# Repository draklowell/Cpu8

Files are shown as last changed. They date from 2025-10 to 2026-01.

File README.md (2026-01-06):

# Architecture of Dragonfly 8b9m CPU

## CPU4/4 (Made by previous students 2024)

CPU4/4

## CPU8/16 (Made by students 2025)

CPU8/16

## Google Spreadsheet for CPU components

<https://docs.google.com/spreadsheets/d/1K8h9GaudWlOMMR60cffy0GHXr_kNyvZ4bdUqfh8yQC4/edit?pli=1&gid=0#gid=0>

## Kicad Components and Footprints used in the project

### Bulk capacitor 100uF 16V

<https://www.rcscomponents.kiev.ua/product/100uf-16v-e5r-6-3x5mm-e5r101m16b-hitano-elektrolitychnyi-kondensator_14183.html>

**Footprint:**

Capacitor_THT:C_Radial_D6.3mm_H5.0mm_P2.50mm

### Decoupling capacitor 100nF 50V Y5V

<https://www.rcscomponents.kiev.ua/product/100nf-50v-y5v-k-10-d-5mm-cc-100n_163416.html>

**Footprints:**

Capacitor_THT:C_Disc_D5.0mm_W2.5mm_P5.00mm

Capacitor_THT:C_Disc_D5.0mm_W2.5mm_P2.50mm

### Resistor Pull UP 10k Ohm 0.25W

<https://www.rcscomponents.kiev.ua/product/10-kohm-5-0-25w-vyv-cr025sjtb-10k-hitano_13787.html>

**Footprint:**

Resistor_THT:R_Axial_DIN0207_L6.3mm_D2.5mm_P7

### Screw Terminal DG126/5.0-02P-14.00Z-H**

<https://www.rcscomponents.kiev.ua/product/klemnyk-dg126-5-0-02p-14-00z-h_18375.html>

**Footprint:**

<https://www.tme.eu/en/details/dg126-5.0-2p14/pcb-terminal-blocks/degson-electronics/dg126-5-0-02p-14-00a-h/>

### Connector PDB-38

<https://www.rcscomponents.kiev.ua/product/pbd-38-kls1-208-2-38-s_119543.html>

**Footprint:**

Connector_PinSocket_2.54mm:PinSocket_2x19_P2.54mm_Vertical

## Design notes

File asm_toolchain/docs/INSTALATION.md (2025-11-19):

# Installation Guide

## Prerequisites

- CMake 3.xx

### 1. Build without installation

```bash
cd asm_toolchain
cmake -S . -B build -DCMAKE_BUILD_TYPE=Release
cmake --build build -j
```

**Створює бінарники в**

```bash
build/bin/cpua
build/bin/cpul
build/bin/cpu_objdump
```

**Використання**

```bash
./build/bin/cpua --help
./build/bin/cpul --help
./build/bin/cpu_objdump main.o
```

### 2. System-wide installation (requires sudo)

Встановлює в `/usr/local/bin` - PATH вже налаштований автоматично:

```bash
cd asm_toolchain
cmake -S . -B build -DCMAKE_BUILD_TYPE=Release -DCMAKE_INSTALL_PREFIX=/usr/local
cmake --build build -j
sudo cmake --install build
```

**Перевірка:**

```bash
which cpua
which cpul
which cpu_objdump
cpua --help
cpul --help
cpu_objdump --help
```

### 3. User-local installation (без sudo)

Встановлює в `$HOME/.local/bin` - потребує додавання до PATH один раз:

```bash
cd asm_toolchain
cmake -S . -B build -DCMAKE_BUILD_TYPE=Release -DCMAKE_INSTALL_PREFIX="$HOME/.local"
cmake --build build -j
cmake --install build
```

**Додайте до PATH (один раз для macOS/Linux):**

```bash
echo 'export PATH="$HOME/.local/bin:$PATH"' >> ~/.zshrc
source ~/.zshrc
```

Для bash:

```bash
echo 'export PATH="$HOME/.local/bin:$PATH"' >> ~/.bashrc
source ~/.bashrc
```

**Перевірка:**

```bash
which cpua
which cpul
which cpu_objdump
cpua --help
cpul --help
```

### 4. Uninstallation

**Для user-local installation:**

```bash
cd asm_toolchain
xargs rm -vf < build/install_manifest.txt
```

**Для system-wide installation:**

```bash
cd asm_toolchain
sudo xargs rm -vf < build/install_manifest.txt
```

**Альтернативно (перегляд файлів перед видаленням):**

```bash
cd asm_toolchain
cat build/install_manifest.txt
```

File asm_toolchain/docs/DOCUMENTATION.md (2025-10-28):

# DOCUMENTATION

# ASM Structures

## Operand Types

| OperandType | Explanation | Example | Machine code (Big Endian) |
|---|---|---|---|
| **None** | Інструкція без аргументів | `nop`, `ret`, `hlt` | Тільки 1 байт опкоду |
| **Reg** | 8-бітний регістр | `add ac`, `mov xh, ac` | Опкод визначається регістрами |
| **Imm8** | 8-бітне безпосереднє значення | `ldi ac, 0x12` | 1 байт значення після опкоду |
| **Imm16** | 16-бітне безпосереднє значення (адреса) | `jmp 0x1234` | 2 байти у Big Endian (`12 34`) |
| **Label** | Мітка, що посилається на адресу коду/даних | `jmp main` | Як `Imm16`, але через релокацію |
| **MemAbs16** | Абсолютна адресація через пам'ять | `ld ac, [0x1234]`, `ld ac, [value]` | 2 байти адреси у Big Endian (`12 34`) |
| **MemAtReg16** | Непряма адресація через 16-бітний регістр  | `ld ac, [X]`, `st [Y], ac` | Опкод кодує вибір пари (X/Y/Z/SP/ADR) |
| **SP** | Використання стекового покажчика | `push ac`, `pop ac` | Спеціальний режим доступу |
| **PC** | Лічильник команд | `jmp pc` (якщо підтримується) | Спеціальний режим |

> **Endianness:** усі 16-бітні значення у машинному коді зберігаються у **Big Endian** — спочатку **старший**, потім **молодший** байт (`HI -> LO`).

> **Примітка:** квадратні дужки тепер можуть містити як числовий літерал, так і мітку (`ld ac, [data]`). У випадку з міткою асемблер створює релокацію для абсолютної адреси.

---

## Registers

| Name | Type | Description |
|---|---|---|
| **AC**  | 8-bit  | Основний акумулятор (ALU), молодший байт пари **X** |
| **XH**  | 8-bit  | Старший байт регістра **X** |
| **YH**  | 8-bit  | Старший байт регістра **Y** |
| **YL**  | 8-bit  | Молодший байт регістра **Y** |
| **ZH**  | 8-bit  | Старший байт регістра **Z** |
| **ZL**  | 8-bit  | Молодший байт регістра **Z** |
| **FR**  | 3-bit  | Регістр прапорів: **Sign (S)**,**NotCarry (C)**, **Zero (Z)** NotCarry – інвертований |
| **IR**  | 8-bit  | Instruction Register (зберігає поточний опкод) |
| **X** | 16-bit | Об'єднання **(XH:AC)** — використовується як 16-бітний адресний або арифметичний регістр |
| **Y** | 16-bit | Об'єднання **(YH:YL)** — 16-бітний покажчик |
| **Z** | 16-bit | Об'єднання **(ZH:ZL)** — 16-бітний покажчик |
| **SP**  | 16-bit | Stack Pointer — лічить **вгору/вниз** залежно від операції |
| **PC**  | 16-bit | Program Counter — завжди рахує **вгору** |
| **ADR** | 16-bit | Address Register — завжди також пише адресу в пам’ять |
| **ARG** | 16-bit | Argument Register — тимчасовий регістр для збереження адрес або аргументів |

---

# Symbol Table

## Purpose

**Symbol Table** — це таблиця, у якій асемблер зберігає всі **імена, що з’являються у програмі**:

* мітки (`main:`, `loop:`)
* імена змінних у секціях `.data`, `.bss`
* зовнішні або глобальні символи (`.globl func`, `extern printf`)

## Structure of symbol record

| Field | Desc |
|---|---|
| `name` | Ім’я символу (`"main"`, `"var1"`, `"printf"`) |
| `section` | Секція, де визначено символ (`.text`, `.data`, `.bss`, або `None`) |
| `value` | Адреса (offset у байтах) всередині секції |
| `bind` | Видимість: `Local`, `Global`, або `Weak` |
| `defined` | Чи символ уже має адресу (`true` — визначений, `false` — тільки оголошений) |

## Symbol Life Cycle

### Pass1

Асемблер читає вихідний код і **будує таблицю символів**.

#### Якщо зустрічає мітку

```asm
main:
```

Додає або оновлює символ:

```
define("main", SectionType::Text, current_offset, Local)
```

#### Якщо директива `.globl foo`

Оголошує символ як глобальний, але `defined = false`.

#### Якщо зустрічає посилання на невідомий символ

```asm
jmp func
```

Створює запис `declare("func")` без визначення — щоб пізніше його знайти.

### Pass2

Асемблер формує машинний код.

* Якщо **символ визначений**, бере його адресу (`value`) і вставляє у код.
* Якщо **ще не визначений**, створює **релокаційний запис (RelocEntry)**, щоб лінкер пізніше підставив адресу.

## Example

```asm
.text
main:
    ldi z, func
    jmpx

func:
    nop
```

### Pass1

| name | section | value  | bind  | defined |
|---|---|---|---|---|
| main | .text | 0x0000 | Local | true |
| func | .text | 0x0004 | Local | true |

### Pass2

`ldi z, func` -> знаходить `func` (визначений у `.text` з адресою `0x0004`)
-> асемблер вставляє `0x0004` у машинний код (`00 04`, Big Endian).

## Example with undefined symbol

```asm
.text
main:
    ldi y, msg
    jmp print

.data
msg:
    .ascii "Hello"

.globl print
```

### Pass1

| name  | section | value  | bind | defined |
|---|---|---|---|---|
| main  | .text | 0x0000 | Local  | true |
| msg | .data | 0x0000 | Local  | true |
| print | None | 0x0000 | Global | false |

### Pass2

* `ldi y, msg` -> `msg` визначений, адреса вставляється напряму.
* `jmp print` -> `print` ще не визначений, створюється **релокація**:

```
reloc:
  offset = 0x0003      ; байт, де треба вставити адресу
  symbol = "print"
  type = ABS16
```

Коли `.o` файл зв’яжеться з іншим, де `print` визначений — **лінкер** підставить справжню адресу.

## Error Types

| Error | When |
|---|---|
| `redefinition of symbol` | символ з таким іменем уже визначений |
| `undefined symbol` | після Pass2 символ не знайдений і не Global |
| `invalid section reference` | посилання на секцію, якої не існує |

## Example with `ldi` and `.text`

```asm
.text
main:
    ldi z, label
    jmpx

label:
    nop
```

Це **нормально**: `ldi` просто завантажує адресу `label` (наприклад, `0x0004`) у регістр `Z`, а `jmpx` виконує стрибок туди. `.text` — така ж секція з валідними адресами.

# Object File and Relocation System

## Overview

The **Object File** is an intermediate binary format generated by the assembler and consumed by the linker. It contains:

* Encoded sections of machine code and data.
* A list of symbols (labels, globals, etc.).
* Relocation entries that describe how to adjust addresses during linking.

This system allows the assembler and linker to work independently: the assembler doesn't need to know final memory addresses — it only marks where they should be patched.

---

## Object File Structure

Кожен об'єктний файл складається з трьох основних таблиць:

| Component | Description |
|---|---|
| **Sections** | Містять байти коду або даних (наприклад, `.text`, `.data`, `.bss`). |
| **Symbols** | Містять всі визначені та згадані імена з їхніми адресами та типами зв'язування. |
| **Relocations** | Містять всі позиції, де лінкер повинен підставити адреси. |

### SectionDescription

```cpp
struct SectionDescription {
    std::string name;     // ".text", ".data", ".bss"
    uint8_t flags{0};     // 1=EXEC, 2=WRITE, 4=READ
    uint8_t align{1};     // alignment (1,2,4,...)
    std::vector<uint8_t> data; // raw bytes for .text/.data
    uint32_t bss_size{0}; // size of uninitialized section
};
```

#### Fields Explained

* **name** — ім'я секції.
* **flags** — права доступу секції (EXEC, WRITE, READ). Бітове кодування.
* **align** — вирівнювання пам'яті для секції (має бути степенем 2).
* **data** — машинний код або ініціалізовані дані.
* **bss_size** — розмір пам'яті для неініціалізованих даних (.bss).

#### Example

| Section | Flags | Align | Description |
|---|---|---|---|
| `.text` | EXEC (1) | 1 | Секція коду, виконується |
| `.data` | WRITE+READ (6) | 2 | Ініціалізовані дані |
| `.bss`  | WRITE+READ (6) | 2 | Змінні, ініціалізовані нулями |

---

### SymbolDescription

```cpp
struct SymbolDescription {
    std::string name;    // symbol name
    int32_t section_index; // section index, -1 = UNDEF
    uint32_t value;      // offset within section
    uint8_t bind;        // 0=Local, 1=Global, 2=Weak
};
```

#### Fields Explained

* **name** — ідентифікатор символу (наприклад, `main`, `msg`).
* **section_index** — секція, до якої належить символ (`-1` означає невизначений).
* **value** — зміщення від початку секції.
* **bind** — видимість і тип зв'язування.

#### Usage

* **Local** символи видимі тільки всередині одного об'єктного файлу.
* **Global** символи видимі для інших об'єктних файлів.
* **Weak** символи можуть бути перевизначені сильнішими.

---

## Relocation System

Коли інструкція посилається на мітку або змінну, адреса якої ще не відома, асемблер не може безпосередньо закодувати адресу. Замість цього він генерує **RelocEntry**, який описує де і як підставити значення, коли фінальне розміщення буде відоме.

### RelocEntry

```cpp
struct RelocEntry {
    uint32_t section_index; // section where the relocation applies
    uint32_t offset;        // byte offset within the section
    RelocType type;         // type of relocation (e.g., ABS16)
    uint32_t symbol_index;  // index of the referenced symbol in the symbol table
    int32_t addend{0};      // additional constant offset
};
```

#### Fields Explained

| Field | Meaning |
|---|---|
| **section_index** | У якій секції застосувати релокацію (наприклад, .text). |
| **offset** | Точна позиція байта всередині цієї секції, яку потрібно підставити. |
| **type** | Визначає як застосувати релокацію (наприклад, абсолютна 16-бітна адреса). |
| **symbol_index**  | Вказує на символ, адреса якого має бути вставлена. |
| **addend** | Додаткова константа, яка додається до адреси символу (для `label + N`). |

#### RelocType

| Name | Meaning |
|---|---|
| `ABS16` | Абсолютна 16-бітна адреса, збережена у форматі Big Endian. |

---

### Example Workflow

```asm
.text
main:
    ldi z, msg   ; load address of msg into Z
    jmpx         ; jump to Z

data:
msg:
    .ascii "Hello"
```

#### Pass1

* Визначає `main` та `msg` у секціях `.text` та `.data`.

#### Pass2

* Кодує `ldi z, msg` -> опкод + заповнювач для адреси.
* Оскільки `msg` відомий (у `.data`), його зміщення вставляється.
* Якби `msg` був в іншому об'єкті, асемблер би створив релокацію:

```cpp
RelocEntry {
    section_index = 0,     // .text
    offset = 2,            // where to patch
    type = RelocType::ABS16,
    symbol_index = 1,      // msg
    addend = 0
};
```

#### Linking

* Лінкер завантажує всі `.o` файли, об'єднує секції.
* Він замінює кожну релокацію фінальною абсолютною адресою:

  ```
  final_value = symbol_address + addend
  ```

  і записує її у `offset` всередині відповідної секції.

---

# Lexer

## Purpose

Лексер — це перший етап роботи асемблера.
Він читає вихідний текст програми (`.asm`) і перетворює його у **послідовність токенів** — базових одиниць синтаксису (імена, числа, дужки, коми, тощо).

Кожен токен містить:

* **тип** (`Ident`, `Number`, `Comma`, `Dot`, …),
* **текстове значення** (наприклад `"ldi"` або `"0x42"`),
* **позицію у файлі** (рядок і стовпчик для зручного виведення помилок).

---

## Algorithm

Лексер проходить текст посимвольно зліва направо,
веде лічильники **рядка** і **колонки**, і будує токени за певними правилами.

1. **Пропускає порожні символи** — пробіли, табуляцію, вертикальні/форматні пробіли.
2. **Розпізнає коментарі**:

* `;` або `#` — до кінця рядка;
* `//` — також коментар до кінця рядка.
    Коментарі не потрапляють у потік токенів.

3. **Фіксує переходи рядка** (`\n`, `\r`, `\r\n`) — створює токен `NewLine`,
   оновлює `line++`, `col = 1`.
4. **Розпізнає розділові символи**:

   ```
   [ ] , : .
   ```

   — кожен стає окремим токеном (`LBracket`, `RBracket`, `Comma`, `Colon`, `Dot`).
5. **Ідентифікатори** — послідовність, що починається з літери або `_`,
   далі можуть бути літери, цифри або `_`.
   Формує токен `Ident`.
6. **Числа** — якщо перший символ — цифра, зчитує всі наступні **цифри або літери**,
   формуючи токен `Number`.
   Тип системи числення (0x..., 0b...) визначається пізніше у `parseNumber`.
7. Якщо зустрічає **невідомий символ** — кидає помилку `util::Error("Unexpected character in input")`.
8. Після завершення додає токен `Eof` — кінець файлу.

---

## FSM

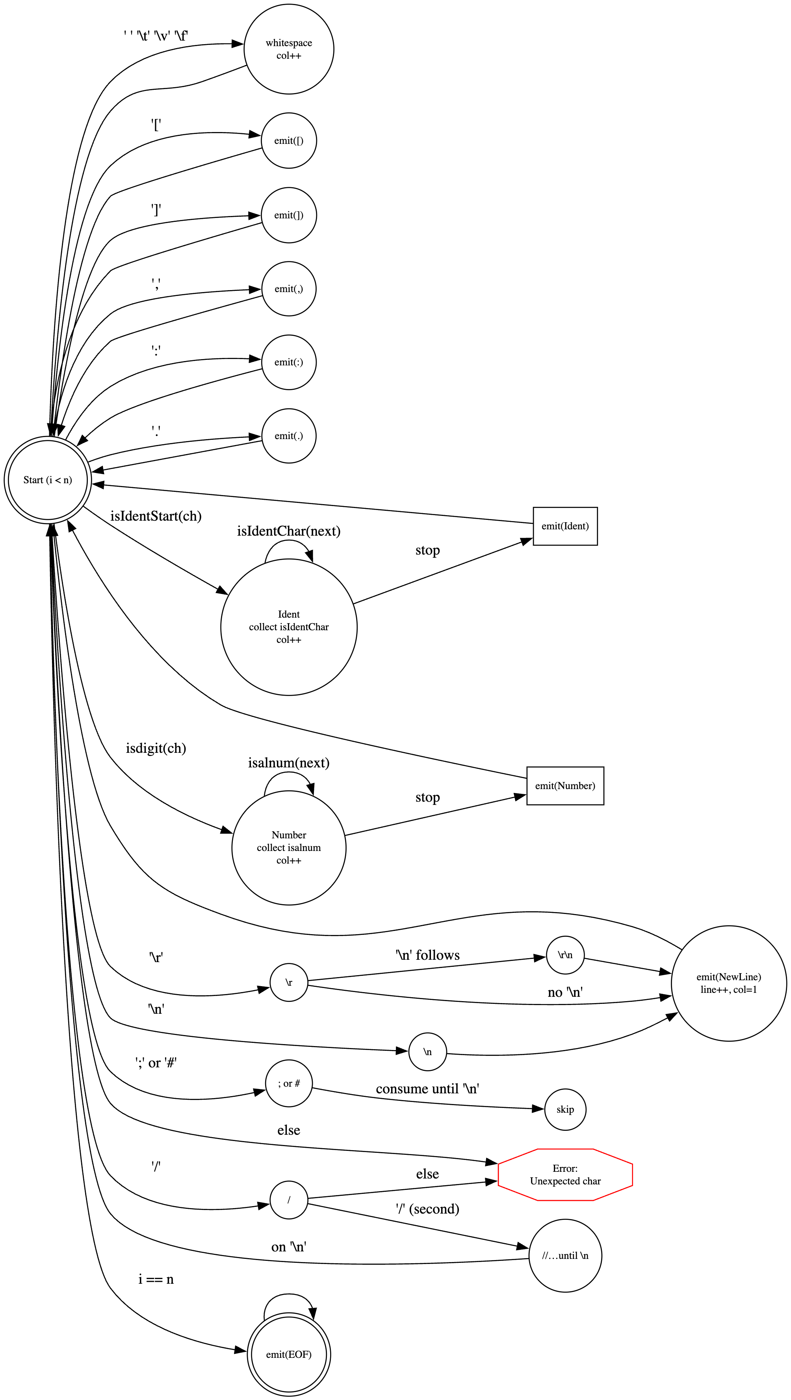
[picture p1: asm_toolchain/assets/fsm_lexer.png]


На зображенні нижче показано **спрощену модель кінцевого автомата (Finite State Machine)**,
який відображає переходи між станами лексера.

* `Start` — початковий стан;
* `NewLine` — обробка переходів рядків;
* `WS` — пропуск пробільних символів;
* `Ident`, `Number` — накопичення тексту токенів;
* `Slash`, `LineComment`, `SemiHash` — обробка коментарів;
* `Emit*` — формування готового токена;
* `Eof` — завершення аналізу;
* `Error` — некоректний символ.

> Кожна стрілка позначає перевірку символу і перехід у новий стан.
> Коли лексер знаходить токен, він “викидає” його у список результатів і повертається до стану `Start`.

---

## Example

Вхідний код:

```asm
; comment
ldi x, 0x42
add-xh
```

Після `lex()` отримаємо токени:

| Тип токена | Текст | Рядок | Колонка |
|---|---|---|---|
| `NewLine`  | | 1 | 1 |
| `Ident` | `ldi` | 2 | 1 |
| `Ident` | `x` | 2 | 5 |
| `Comma` | `,` | 2 | 6 |
| `Number` | `0x42` | 2 | 8 |
| `NewLine`  | | 2 | 12 |
| `Ident` | `add-xh` | 3 | 1 |
| `Eof` | | 3 | 8 |

---

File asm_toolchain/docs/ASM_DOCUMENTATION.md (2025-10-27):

# Documentation assembler CPU8/16

## 1. Overview

CPU8/16 — це навчальний кастомний асемблер для однойменного 8-бітного процесора з вибірковою підтримкою 16-бітних операцій. Джерельні файли проходять через GCC-препроцесор (`cpp`), тому можна використовувати `#define`, `#include`, `#ifdef` та інші директиви. Процес складання виконується у два проходи: **Pass1** збирає мітки та формує таблицю символів, а **Pass2** підставляє адреси й генерує машинний код. Результатом є плоский ROM-образ на 16 КБ, заповнений байтами `0xFF`, у який потрапляють секції `.text` та `.rodata`.

## 2. Syntax basics

Кожен рядок інструкції має формат:

```
<label>:    <mnemonic> <operand1>, <operand2>   ; optional comment
```

* **Мітки** оголошуються через `label:` і можуть використовуватись як адреси.
* **Регістр** нечутливий до регістру запису: `AC`, `ac`, `Ac` — тотожні.
* **Числові літерали**:
  * десяткові: `13`
  * шістнадцяткові: `0x12FF`
  * двійкові: `0b10101010`

## 3. Sections and directives

Нижче наведені стандартні секції з прикладами використання:

### `.text` — код

```asm
.text
.global main
main:
    ldi ac, 0x01
    hlt
```

### `.rodata` — константи

```asm
.rodata
msg: .asciz "Hi"
```

### `.data` — ініціалізовані змінні
>
> **Примітка:** наразі секція `.data` не копіюється до RAM автоматично, але її можна використовувати для явних таблиць у ROM.

```asm
.data
init_value: .word 0x1234
```

### `.bss` — неініціалізовані змінні

У секції `.bss` дані **не** емітяться — асемблер лише підраховує розмір.

```asm
.bss
array:
    .res 64    ; резервує 64 байти, не емітиться у бінарник
```

### `.globl` / `.extern`

```asm
.globl main
.extern memcpy
```

### Directives for data definition

* `.byte`, `.word`, `.ascii`, `.asciz` — формують байти у поточній секції (**заборонено** у `.bss`).
* `.res` — резервує байти лише у `.bss`.

## 4. Adddresation and operand types

| Тип | Приклад | Опис |
|---|---|---|
| Імедіатна | `ldi ac, 0x12` | Завантажує константу у регістр. |
| Абсолютна пам’ять | `ld ac, [label]` | Читає байт із адреси в пам’яті. |
| Регістр до регістра | `mov xh, ac` | Копіює значення між регістрами. |
| 16-бітні адреси | `ldi z, label` | Завантажує повну адресу мітки. |

⚠️(NOT SUPPORTED YET) **Помилка:** якщо спробувати завантажити 16-бітне значення в 8-бітний регістр, з’явиться повідомлення:

```
error: cannot load 16-bit immediate into 8-bit register 'zl'
note: use 'ld zl, [label]' if you meant to load a byte
```

## 5. Mnemonics and instruction set

Інструкції групуються за функціями, подібно до документації AVR:

* **LDI / LD / ST** — завантаження та збереження даних (безпосередні, абсолютні, через покажчики).
* **MOV / PUSH / POP** — передавання даних між регістрами та стеком.
* **CALL / RET / JMP / JZ / JC / ...** — передавання керування.
* **ADD / SUB / NAND / NOR / XOR / NOT / INC / DEC / ...** — арифметико-логічні операції.

Кожна канонічна форма зберігається у таблиці `table.csv`. Людські записи на кшталт `mov ac, xh` автоматично нормалізуються до канонічних імен із дефісами (`mov-ac-xh`) під час підбору опкодів.

## 6. Examples

### Приклад із константою в `.rodata`

```asm
.rodata
msg: .asciz "Hi"

.text
.global main
main:
    ldi z, msg
    ld ac, [msg]
    intd
    shl
    inte
    hlt
```

### Example with `.bss`

```asm
.bss
n: .res 4

.text
main:
    ldi sp, 0xFFFF
    st [n], ac
    hlt
```

## 7. Diagnostics — error messages

| Помилка | Пояснення |
|---|---|
| `undefined symbol` | Посилання на мітку, яка не визначена. |
| `invalid operands for instruction` | Невідповідні операнди, наприклад `mov ac, 0x12`.|
| `cannot load 16-bit immediate into 8-bit register` | Спроба `ldi zl, label` або `ldi ac, 0x1234`. |
| `.byte not allowed in .bss` | Заборонені директиви в секції `.bss`. |
| `unknown instruction` | Мнемоніка відсутня у `table.csv`. |

---

## CLI utilities

### `asm_cli`

```bash
Usage: asm_cli [options] <input.asm> [output]
Options:
  -o <file>         Output path (bin or obj)
  --object          Emit relocatable object (.o)
  --no-preprocess   Do not run external preprocessor
  --verbose         Print section size summary
  --help            Show this help message
```

* **Базова збірка ROM** (16 КБ образ, заповнений `0xFF`):

  ```bash
  ./asm_cpu program.S build/program.bin
  ```

* **Вивід обʼєкта для лінкера**:

  ```bash
  ./asm_cpu --object -o build/program.o program.S
  ```

  У цьому режимі `.text`, `.rodata` та релокації зберігаються для подальшого лінкування.

* **Вимкнення зовнішнього препроцесора** — корисно, якщо файл уже пройшов `cpp` або препроцесор не потрібен (притримуємось конвенції, що .s файли не потребують препроцесингу, а .S файли — потребують):

  ```bash
  ./asm_cpu --no-preprocess program_pp.S build/program.bin
  ```

* **Додаткові підказки про розмір секцій**:

  ```bash
  ./asm_cpu --verbose program.S build/program.bin
  ```

  Після успішної збірки утиліта виведе кількість байтів у `.text` та `.rodata`, а також сумарний розмір ROM.

### `ld_cli`

```bash
Usage: ld <out.bin> <in1.o> <in2.o> ... [--map <file.map>] [--entry <sym>] [--rom-size N] [--rom-fill 0xFF]
```

* **Стандартне лінкування кількох обʼєктів**:

  ```bash
  ./ld_cpu build/program.bin build/startup.o build/main.o
  ```

  За замовчуванням точка входу — символ `main`, а результатом буде 16 КБ ROM із заповненням `0xFF`.

* **Зміна точки входу**:

  ```bash
  ./ld_cpu build/program.bin build/startup.o build/main.o --entry reset
  ```

* **Генерація map-файлу з розкладкою символів**:

  ```bash
  ./ld_cpu build/program.bin build/main.o --map build/program.map
  ```

* **Контроль розміру та заповнення ROM** (байтове значення можна задавати у будь-якій нотації, що підтримується `std::stoul`):

  ```bash
  ./ld_cpu build/program.bin build/main.o --rom-size 8192 --rom-fill 0x00
  ```

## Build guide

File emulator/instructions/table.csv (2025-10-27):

hexOpcode | decOpcode | mnemonic | maxCycles | minCycles
00 | 000 | nop | 3 | 3
01 | 001 | inte | 4 | 4
02 | 002 | intd | 4 | 4
03 | 003 | ldi-ac-[byte] | 6 | 6
04 | 004 | ld-ac-[word] | 10 | 10
05 | 005 | ldi-xh-[byte] | 6 | 6
06 | 006 | ld-xh-[word] | 10 | 10
07 | 007 | ldi-yl-[byte] | 6 | 6
08 | 008 | ld-yl-[word] | 10 | 10
09 | 009 | ldi-yh-[byte] | 6 | 6
0a | 010 | ld-yh-[word] | 10 | 10
0b | 011 | ldi-fr-[byte] | 6 | 6
0c | 012 | ld-fr-[word] | 10 | 10
0d | 013 | ldi-zl-[byte] | 6 | 6
0e | 014 | ld-zl-[word] | 10 | 10
0f | 015 | ldi-zh-[byte] | 6 | 6
10 | 016 | ld-zh-[word] | 10 | 10
11 | 017 | ldi-x-[word] | 7 | 7
12 | 018 | ldi-y-[word] | 7 | 7
13 | 019 | ldi-z-[word] | 7 | 7
14 | 020 | ldi-sp-[word] | 7 | 7
15 | 021 | ldx-ac | 6 | 6
16 | 022 | ldx-xh | 6 | 6
17 | 023 | ldx-yl | 6 | 6
18 | 024 | ldx-yh | 6 | 6
19 | 025 | ldx-fr | 6 | 6
1a | 026 | st-[word]-ac | 10 | 10
1b | 027 | st-[word]-xh | 10 | 10
1c | 028 | inth | 11 | 11
1d | 029 | st-[word]-yl | 10 | 10
1e | 030 | st-[word]-yh | 10 | 10
1f | 031 | st-[word]-fr | 10 | 10
20 | 032 | st-[word]-zl | 10 | 10
21 | 033 | st-[word]-zh | 10 | 10
22 | 034 | stx-ac | 6 | 6
23 | 035 | stx-xh | 6 | 6
24 | 036 | stx-yl | 6 | 6
25 | 037 | stx-yh | 6 | 6
26 | 038 | stx-fr | 6 | 6
27 | 039 | mov-xh-ac | 4 | 4
28 | 040 | mov-yl-ac | 4 | 4
29 | 041 | mov-yh-ac | 4 | 4
2a | 042 | mov-fr-ac | 4 | 4
2b | 043 | mov-zl-ac | 4 | 4
2c | 044 | mov-zh-ac | 4 | 4
2d | 045 | mov-ac-xh | 4 | 4
2e | 046 | mov-yl-xh | 4 | 4
2f | 047 | mov-yh-xh | 4 | 4
30 | 048 | mov-fr-xh | 4 | 4
31 | 049 | mov-zl-xh | 4 | 4
32 | 050 | mov-zh-xh | 4 | 4
33 | 051 | mov-ac-yl | 4 | 4
34 | 052 | mov-xh-yl | 4 | 4
35 | 053 | mov-yh-yl | 4 | 4
36 | 054 | mov-fr-yl | 4 | 4
37 | 055 | mov-zl-yl | 4 | 4
38 | 056 | mov-zh-yl | 4 | 4
39 | 057 | mov-ac-yh | 4 | 4
3a | 058 | mov-xh-yh | 4 | 4
3b | 059 | mov-yl-yh | 4 | 4
3c | 060 | mov-fr-yh | 4 | 4
3d | 061 | mov-zl-yh | 4 | 4
3e | 062 | mov-zh-yh | 4 | 4
3f | 063 | mov-ac-fr | 4 | 4
40 | 064 | mov-xh-fr | 4 | 4
41 | 065 | mov-yl-fr | 4 | 4
42 | 066 | mov-yh-fr | 4 | 4
43 | 067 | mov-zl-fr | 4 | 4
44 | 068 | mov-zh-fr | 4 | 4
45 | 069 | mov-ac-zl | 4 | 4
46 | 070 | mov-xh-zl | 4 | 4
47 | 071 | mov-yl-zl | 4 | 4
48 | 072 | mov-yh-zl | 4 | 4
49 | 073 | mov-fr-zl | 4 | 4
4a | 074 | mov-zh-zl | 4 | 4
4b | 075 | mov-ac-zh | 4 | 4
4c | 076 | mov-xh-zh | 4 | 4
4d | 077 | mov-yl-zh | 4 | 4
4e | 078 | mov-yh-zh | 4 | 4
4f | 079 | mov-fr-zh | 4 | 4
50 | 080 | mov-zl-zh | 4 | 4
51 | 081 | mov-sp-z | 5 | 5
52 | 082 | mov-z-sp | 5 | 5
53 | 083 | mov-z-pc | 5 | 5
54 | 084 | push-ac | 6 | 6
55 | 085 | push-xh | 6 | 6
56 | 086 | push-yl | 6 | 6
57 | 087 | push-yh | 6 | 6
58 | 088 | push-fr | 6 | 6
59 | 089 | push-zl | 6 | 6
5a | 090 | push-zh | 6 | 6
5b | 091 | push-x | 7 | 7
5c | 092 | push-y | 7 | 7
5d | 093 | push-z | 7 | 7
5e | 094 | push-pc | 7 | 7
5f | 095 | pop-ac | 7 | 7
60 | 096 | pop-xh | 7 | 7
61 | 097 | pop-yl | 7 | 7
62 | 098 | pop-yh | 7 | 7
63 | 099 | pop-fr | 7 | 7
64 | 100 | pop-zl | 7 | 7
65 | 101 | pop-zh | 7 | 7
66 | 102 | pop-x | 8 | 8
67 | 103 | pop-y | 8 | 8
68 | 104 | pop-z | 8 | 8
69 | 105 | jnz-[word] | 9 | 3
6a | 106 | jnzx | 5 | 3
6b | 107 | jz-[word] | 9 | 3
6c | 108 | jzx | 5 | 3
6d | 109 | jnc-[word] | 9 | 3
6e | 110 | jncx | 5 | 3
6f | 111 | jc-[word] | 9 | 3
70 | 112 | jcx | 5 | 3
71 | 113 | jp-[word] | 9 | 3
72 | 114 | jpx | 5 | 3
73 | 115 | jm-[word] | 9 | 3
74 | 116 | jmx | 5 | 3
75 | 117 | jmp-[word] | 9 | 9
76 | 118 | jmpx | 5 | 5
77 | 119 | cnz-[word] | 13 | 3
78 | 120 | cz-[word] | 13 | 3
79 | 121 | cnc-[word] | 13 | 3
7a | 122 | cc-[word] | 13 | 3
7b | 123 | cp-[word] | 13 | 3
7c | 124 | cm-[word] | 13 | 3
7d | 125 | call-[word] | 13 | 13
7e | 126 | rnz | 8 | 3
7f | 127 | rz | 8 | 3
80 | 128 | rnc | 8 | 3
81 | 129 | rc | 8 | 3
82 | 130 | rp | 8 | 3
83 | 131 | rm | 8 | 3
84 | 132 | ret | 8 | 8
85 | 133 | add-ac | 5 | 5
86 | 134 | add-xh | 5 | 5
87 | 135 | add-yl | 5 | 5
88 | 136 | add-yh | 5 | 5
89 | 137 | add-zl | 5 | 5
8a | 138 | add-zh | 5 | 5
8b | 139 | addi-[byte] | 7 | 7
8c | 140 | sub-ac | 5 | 5
8d | 141 | sub-xh | 5 | 5
8e | 142 | sub-yl | 5 | 5
8f | 143 | sub-yh | 5 | 5
90 | 144 | sub-zl | 5 | 5
91 | 145 | sub-zh | 5 | 5
92 | 146 | subi-[byte] | 7 | 7
93 | 147 | nand-ac | 5 | 5
94 | 148 | nand-xh | 5 | 5
95 | 149 | nand-yl | 5 | 5
96 | 150 | nand-yh | 5 | 5
97 | 151 | nand-zl | 5 | 5
98 | 152 | nand-zh | 5 | 5
99 | 153 | nandi-[byte] | 7 | 7
9a | 154 | xor-ac | 5 | 5
9b | 155 | xor-xh | 5 | 5
9c | 156 | xor-yl | 5 | 5
9d | 157 | xor-yh | 5 | 5
9e | 158 | xor-zl | 5 | 5
9f | 159 | xor-zh | 5 | 5
a0 | 160 | xori-[byte] | 7 | 7
a1 | 161 | nor-ac | 5 | 5
a2 | 162 | nor-xh | 5 | 5
a3 | 163 | nor-yl | 5 | 5
a4 | 164 | nor-yh | 5 | 5
a5 | 165 | nor-zl | 5 | 5
a6 | 166 | nor-zh | 5 | 5
a7 | 167 | nori-[byte] | 7 | 7
a8 | 168 | adc-ac | 5 | 5
a9 | 169 | adc-xh | 5 | 5
aa | 170 | adc-yl | 5 | 5
ab | 171 | adc-yh | 5 | 5
ac | 172 | adc-zl | 5 | 5
ad | 173 | adc-zh | 5 | 5
ae | 174 | adci-[byte] | 7 | 7
af | 175 | sbb-ac | 5 | 5
b0 | 176 | sbb-xh | 5 | 5
b1 | 177 | sbb-yl | 5 | 5
b2 | 178 | sbb-yh | 5 | 5
b3 | 179 | sbb-zl | 5 | 5
b4 | 180 | sbb-zh | 5 | 5
b5 | 181 | sbbi-[byte] | 7 | 7
b6 | 182 | inc-ac | 5 | 5
b7 | 183 | inc-xh | 5 | 5
b8 | 184 | inc-yl | 5 | 5
b9 | 185 | inc-yh | 5 | 5
ba | 186 | inc-zl | 5 | 5
bb | 187 | inc-zh | 5 | 5
bc | 188 | dec-ac | 5 | 5
bd | 189 | dec-xh | 5 | 5
be | 190 | dec-yl | 5 | 5
bf | 191 | dec-yh | 5 | 5
c0 | 192 | dec-zl | 5 | 5
c1 | 193 | dec-zh | 5 | 5
c2 | 194 | icc-ac | 5 | 5
c3 | 195 | icc-xh | 5 | 5
c4 | 196 | icc-yl | 5 | 5
c5 | 197 | icc-yh | 5 | 5
c6 | 198 | icc-zl | 5 | 5
c7 | 199 | icc-zh | 5 | 5
c8 | 200 | dcb-ac | 5 | 5
c9 | 201 | dcb-xh | 5 | 5
ca | 202 | dcb-yl | 5 | 5
cb | 203 | dcb-yh | 5 | 5
cc | 204 | dcb-zl | 5 | 5
cd | 205 | dcb-zh | 5 | 5
ce | 206 | not-ac | 5 | 5
cf | 207 | not-xh | 5 | 5
d0 | 208 | not-yl | 5 | 5
d1 | 209 | not-yh | 5 | 5
d2 | 210 | not-zl | 5 | 5
d3 | 211 | not-zh | 5 | 5
d4 | 212 | cmp-ac | 5 | 5
d5 | 213 | cmp-xh | 5 | 5
d6 | 214 | cmp-yl | 5 | 5
d7 | 215 | cmp-yh | 5 | 5
d8 | 216 | cmp-zl | 5 | 5
d9 | 217 | cmp-zh | 5 | 5
da | 218 | cmpi-[byte] | 7 | 7
db | 219 | shl | 4 | 4
dc | 220 | shr | 4 | 4
dd | 221 | hlt | 1 | 1

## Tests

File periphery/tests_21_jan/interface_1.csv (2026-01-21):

time | not_read | not_write | address | data | clk
676 | 1 | 1 | 0 | 225 | 0
1512 | 1 | 1 | 0 | 225 | 0
2404 | 1 | 1 | 0 | 225 | 0
3284 | 1 | 1 | 0 | 225 | 0
4476 | 1 | 1 | 0 | 225 | 0
6008 | 1 | 1 | 0 | 225 | 0
7536 | 1 | 1 | 0 | 160 | 0
9068 | 1 | 1 | 0 | 0 | 0
10436 | 1 | 1 | 0 | 0 | 0
11872 | 1 | 1 | 0 | 0 | 0
13324 | 1 | 1 | 0 | 0 | 0
14764 | 1 | 1 | 0 | 0 | 0
16208 | 1 | 1 | 0 | 0 | 0
17652 | 1 | 1 | 0 | 0 | 0
19096 | 1 | 1 | 0 | 161 | 0
20712 | 1 | 1 | 0 | 225 | 0
22328 | 1 | 1 | 0 | 225 | 0
23944 | 1 | 1 | 0 | 225 | 0
25556 | 1 | 1 | 0 | 225 | 0
27172 | 1 | 1 | 0 | 160 | 0
28796 | 1 | 1 | 0 | 0 | 0
30232 | 1 | 1 | 0 | 0 | 0
31676 | 1 | 1 | 0 | 0 | 0
33124 | 1 | 1 | 0 | 0 | 0
34568 | 1 | 1 | 0 | 0 | 0
36020 | 1 | 1 | 0 | 0 | 0
37456 | 1 | 1 | 0 | 0 | 0
38904 | 1 | 1 | 0 | 161 | 0
40516 | 1 | 1 | 0 | 225 | 0
42140 | 1 | 1 | 0 | 225 | 0
43748 | 1 | 1 | 0 | 225 | 0
45364 | 1 | 1 | 0 | 225 | 0
46976 | 1 | 1 | 0 | 161 | 0
48592 | 1 | 1 | 0 | 0 | 0
50040 | 1 | 1 | 0 | 0 | 0
51484 | 1 | 1 | 0 | 0 | 0
52928 | 1 | 1 | 0 | 0 | 0
54380 | 1 | 1 | 0 | 0 | 0
55816 | 1 | 1 | 0 | 0 | 0
57264 | 1 | 1 | 0 | 0 | 0
58708 | 1 | 1 | 0 | 161 | 0
60324 | 1 | 1 | 0 | 225 | 0
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

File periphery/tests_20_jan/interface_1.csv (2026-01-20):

time | not_read | not_write | address | data | clk
676 | 1 | 1 | 0 | 0 | 0
1416 | 1 | 1 | 0 | 0 | 0
2200 | 1 | 1 | 0 | 0 | 0
2984 | 1 | 1 | 0 | 0 | 0
3800 | 1 | 1 | 0 | 0 | 0
5164 | 1 | 1 | 0 | 0 | 0
6516 | 1 | 1 | 0 | 255 | 0
8048 | 1 | 1 | 0 | 255 | 0
9576 | 1 | 1 | 0 | 255 | 0
11108 | 1 | 1 | 0 | 255 | 0
12724 | 1 | 1 | 0 | 255 | 0
14344 | 1 | 1 | 0 | 255 | 0
15952 | 1 | 1 | 0 | 0 | 0
17396 | 1 | 1 | 0 | 0 | 0
18844 | 1 | 1 | 0 | 0 | 0
20288 | 1 | 1 | 0 | 0 | 0
21736 | 1 | 1 | 0 | 0 | 0
23180 | 1 | 1 | 0 | 0 | 0
24628 | 1 | 1 | 0 | 0 | 0
26068 | 1 | 1 | 0 | 255 | 0
27688 | 1 | 1 | 0 | 255 | 0
29300 | 1 | 1 | 0 | 255 | 0
30920 | 1 | 1 | 0 | 255 | 0
32528 | 1 | 1 | 0 | 255 | 0
34144 | 1 | 1 | 0 | 255 | 0
35756 | 1 | 1 | 0 | 0 | 0
37204 | 1 | 1 | 0 | 0 | 0
38648 | 1 | 1 | 0 | 0 | 0
40100 | 1 | 1 | 0 | 0 | 0
41540 | 1 | 1 | 0 | 0 | 0
42984 | 1 | 1 | 0 | 0 | 0
44428 | 1 | 1 | 0 | 0 | 0
45872 | 1 | 1 | 0 | 255 | 0
47488 | 1 | 1 | 0 | 255 | 0
49104 | 1 | 1 | 0 | 255 | 0
50720 | 1 | 1 | 0 | 255 | 0
52340 | 1 | 1 | 0 | 255 | 0
53948 | 1 | 1 | 0 | 255 | 0
55564 | 1 | 1 | 0 | 0 | 0
57008 | 1 | 1 | 0 | 0 | 0
58460 | 1 | 1 | 0 | 0 | 0
59896 | 1 | 1 | 0 | 0 | 0
61344 | 1 | 1 | 0 | 0 | 0
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

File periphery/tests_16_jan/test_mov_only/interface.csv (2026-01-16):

time | not_read | not_write | address | data | clk
676 | 1 | 1 | 0 | 0 | 0
1416 | 1 | 1 | 0 | 0 | 0
2200 | 1 | 1 | 0 | 0 | 0
2984 | 1 | 1 | 0 | 0 | 0
3800 | 1 | 1 | 0 | 0 | 0
5164 | 1 | 1 | 0 | 0 | 0
6516 | 1 | 1 | 0 | 0 | 0
7880 | 1 | 1 | 0 | 0 | 0
9244 | 1 | 1 | 0 | 0 | 0
10600 | 1 | 1 | 0 | 0 | 0
12044 | 1 | 1 | 0 | 0 | 0
13496 | 1 | 1 | 0 | 0 | 0
14932 | 1 | 1 | 0 | 0 | 0
16380 | 1 | 1 | 0 | 0 | 0
17824 | 1 | 1 | 0 | 0 | 0
19268 | 1 | 1 | 0 | 0 | 0
20712 | 1 | 1 | 0 | 0 | 0
22156 | 1 | 1 | 0 | 0 | 0
23608 | 1 | 1 | 0 | 0 | 0
25048 | 1 | 1 | 0 | 0 | 0
26492 | 1 | 1 | 0 | 0 | 0
27936 | 1 | 1 | 0 | 0 | 0
29384 | 1 | 1 | 0 | 0 | 0
30836 | 1 | 1 | 0 | 0 | 0
32272 | 1 | 1 | 0 | 0 | 0
33716 | 1 | 1 | 0 | 0 | 0
35164 | 1 | 1 | 0 | 0 | 0
36608 | 1 | 1 | 0 | 0 | 0
38060 | 1 | 1 | 0 | 0 | 0
39496 | 1 | 1 | 0 | 0 | 0
40944 | 1 | 1 | 0 | 0 | 0
42388 | 1 | 1 | 0 | 0 | 0
43832 | 1 | 1 | 0 | 0 | 0
45284 | 1 | 1 | 0 | 0 | 0
46724 | 1 | 1 | 0 | 0 | 0
48176 | 1 | 1 | 0 | 0 | 0
49612 | 1 | 1 | 0 | 0 | 0
51060 | 1 | 1 | 0 | 0 | 0
52504 | 1 | 1 | 0 | 0 | 0
53948 | 1 | 1 | 0 | 0 | 0
55400 | 1 | 1 | 0 | 0 | 0
56840 | 1 | 1 | 0 | 0 | 0
58284 | 1 | 1 | 0 | 0 | 0
59728 | 1 | 1 | 0 | 0 | 0
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

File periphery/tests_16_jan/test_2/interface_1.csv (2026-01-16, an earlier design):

time | not_read | not_write | address | data | clk
676 | 1 | 1 | 0 | 0 | 0
1416 | 1 | 1 | 0 | 0 | 0
2200 | 1 | 1 | 0 | 0 | 0
2984 | 1 | 1 | 0 | 0 | 0
3800 | 1 | 1 | 0 | 0 | 0
5164 | 1 | 1 | 0 | 0 | 0
6516 | 1 | 1 | 0 | 0 | 0
7880 | 1 | 1 | 0 | 0 | 0
9244 | 1 | 1 | 0 | 0 | 0
10600 | 1 | 1 | 0 | 0 | 0
12044 | 1 | 1 | 0 | 0 | 0
13496 | 1 | 1 | 0 | 0 | 0
14932 | 1 | 1 | 0 | 0 | 0
16380 | 1 | 1 | 0 | 0 | 0
17824 | 1 | 1 | 0 | 0 | 0
19268 | 1 | 1 | 0 | 0 | 0
20712 | 1 | 1 | 0 | 0 | 0
22156 | 1 | 1 | 0 | 0 | 0
23608 | 1 | 1 | 0 | 0 | 0
25048 | 1 | 1 | 0 | 0 | 0
26492 | 1 | 1 | 0 | 0 | 0
27936 | 1 | 1 | 0 | 0 | 0
29384 | 1 | 1 | 0 | 0 | 0
30836 | 1 | 1 | 0 | 0 | 0
32272 | 1 | 1 | 0 | 0 | 0
33716 | 1 | 1 | 0 | 0 | 0
35164 | 1 | 1 | 0 | 0 | 0
36608 | 1 | 1 | 0 | 0 | 0
38060 | 1 | 1 | 0 | 0 | 0
39496 | 1 | 1 | 0 | 0 | 0
40944 | 1 | 1 | 0 | 0 | 0
42388 | 1 | 1 | 0 | 0 | 0
43832 | 1 | 1 | 0 | 0 | 0
45284 | 1 | 1 | 0 | 0 | 0
46724 | 1 | 1 | 0 | 0 | 0
48176 | 1 | 1 | 0 | 0 | 0
49612 | 1 | 1 | 0 | 0 | 0
51060 | 1 | 1 | 0 | 0 | 0
52504 | 1 | 1 | 0 | 0 | 0
53948 | 1 | 1 | 0 | 0 | 0
55400 | 1 | 1 | 0 | 0 | 0
56840 | 1 | 1 | 0 | 0 | 0
58284 | 1 | 1 | 0 | 0 | 0
59728 | 1 | 1 | 0 | 0 | 0
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

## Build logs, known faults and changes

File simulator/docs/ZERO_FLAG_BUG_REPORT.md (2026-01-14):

# Звіт про помилку: Неправильна робота Zero Flag Detection

**Дата:** 13 січня 2026
**Статус:** Критична помилка
**Компонент:** ALU Hub — схема визначення Zero Flag

---

## Опис проблеми

При виконанні програми з умовним переходом `jz` (jump if zero), інструкція **завжди виконує стрибок**, незалежно від значення акумулятора.

### Тестова програма

```asm
ldi-ac-[byte] 0x0A   ; AC = 10 (не нуль!)
cmpi-[byte] 0x05     ; порівняти AC з 5 (10 ≠ 5, Z має бути 0)
jz-[word] 0x000B     ; НЕ повинен стрибати, бо Z=0
```

### Очікувана vs Фактична поведінка

| Параметр | Очікувано | Фактично |
|---|---|---|
| AC після `ldi` | 0x0A | 0x0A ✓ |
| Z після `cmpi` | 0 | **1** ✗ |
| Стрибок `jz` | НІ | **ТАК** ✗ |
| Кінцевий PC | 0x0007 | **0x000B** ✗ |

---

## Діагностика

### Крок 1: Моніторинг сигналу STATE10 (Zero Flag)

Запуск діагностичного скрипта `diag_jz.py`:

```
Cyc | PC     | Instr | AC   | ZeroOut | Mnemonic
------------------------------------------------------------
 11 | 0x0004 | 0xDA  | 0x0A | Z=0     | cmpi-[byte]
 12 | 0x0004 | 0xDA  | 0x0A | Z=1     | cmpi-[byte]  ← ПОМИЛКА!
 16 | 0x0005 | 0x6B  | 0x0A | Z=1     | jz-[word]
 22 | 0x000B | 0x6B  | 0x0A | Z=1     | jz-[word]    ← Стрибнув!
```

**Висновок:** Флаг Z неправильно встановлюється в 1 після `cmpi`.

### Крок 2: Моніторинг виходу ALU

Запуск діагностичного скрипта `diag_alu.py`:

```
Cyc | PC     | AC   | ALU  | Z   | ZO  | Mnemonic
------------------------------------------------------------
 11 | 0x0004 | 0x0A | 0x05 | Z=0 | ZO=1 | cmpi-[byte]  ← ZO=1 при ALU≠0!
 12 | 0x0004 | 0x0A | 0x74 | Z=1 | ZO=1 | cmpi-[byte]
```

**Критична помилка:** `ZO=1` (Zero Output HIGH) коли `ALU=0x05` (не нуль!).

---

## Аналіз схеми

### Компоненти Zero Detection

Схема визначення Zero flag знаходиться в `alu_hub.frp` і використовує:
- **U10** — 74LS02 (quad NOR) для нижніх біт F0-F3
- **U9** — 74LS02 (quad NOR) для верхніх біт F4-F7

### Поточна логіка (НЕПРАВИЛЬНА)

```
U10 (нижні біти):
├── Gate 1: Y1 = NOR(F0, F1)
├── Gate 2: Y2 = NOR(F2, F3)
├── Gate 3: Y3 = NOR(Y1, Y2)  ← Проблемний каскад!
└── Gate 4: ALUZO = NOT(Y4_u9)

U9 (верхні біти):
├── Gate 1: Y1 = NOR(F4, F5)
├── Gate 2: Y2 = NOR(F6, F7)
├── Gate 3: Y3 = NOR(Y1, Y2)
└── Gate 4: Y4 = NOR(Y3_u9, Y3_u10)
```

### Математичний доказ помилки

**Тест 1: Всі біти = 0 (результат 0x00)**
```
U10: Y1 = NOR(0,0) = 1
     Y2 = NOR(0,0) = 1
     Y3 = NOR(1,1) = 0  ← НЕ ТАК!

U9:  Y3 = NOR(1,1) = 0
     Y4 = NOR(0,0) = 1

ALUZO = NOT(1) = 0  ← НЕПРАВИЛЬНО! Має бути 1!
```

**Тест 2: F0 = 1, решта = 0 (результат 0x01)**
```
U10: Y1 = NOR(1,0) = 0
     Y2 = NOR(0,0) = 1
     Y3 = NOR(0,1) = 0

U9:  Y3 = 0
     Y4 = NOR(0,0) = 1

ALUZO = NOT(1) = 0  ← Той самий результат!
```

**Висновок:** ALUZO завжди = 0, незалежно від вхідних даних.

### Причина помилки

Каскад `NOR → NOR` реалізує формулу:
```
NOR(NOR(A,B), NOR(C,D)) = (A OR B) AND (C OR D)
```

Це **НЕ еквівалентно** потрібній функції:
```
ZERO = NOT(F0 OR F1 OR F2 OR F3 OR F4 OR F5 OR F6 OR F7)
```

---

## Вплив на систему

### Зламані інструкції

| Мнемоніка | Опис | Статус |
|---|---|---|
| `jz-[word]` | Jump if Zero | ❌ Завжди стрибає |
| `jnz-[word]` | Jump if Not Zero | ❌ Ніколи не стрибає |
| `jzx` | Jump if Zero (indirect) | ❌ Завжди стрибає |
| `jnzx` | Jump if Not Zero (indirect) | ❌ Ніколи не стрибає |
| `cz-[word]` | Call if Zero | ❌ Завжди викликає |
| `cnz-[word]` | Call if Not Zero | ❌ Ніколи не викликає |
| `rz` | Return if Zero | ❌ Завжди повертає |
| `rnz` | Return if Not Zero | ❌ Ніколи не повертає |

**Всього:** 8 інструкцій повністю непрацездатні.

---

## Рекомендації щодо виправлення

### Варіант 1: Апаратне виправлення (рекомендовано)

Замінити каскад NOR→NOR на правильну логіку:

**Опція A: Використати 74LS30 (8-input NAND) + інвертор**
```
ZERO = NOT(NAND(F0,F1,F2,F3,F4,F5,F6,F7))
     = NOT(NOT(F0 AND F1 AND ... AND F7))
```
*Примітка: Потрібно інвертувати входи!*

**Опція B: Правильний каскад з AND**
```
        F0 ──┬── NOR ──┐
        F1 ──┘         │
        F2 ──┬── NOR ──┼── AND ──┐
        F3 ──┘         │         │
        F4 ──┬── NOR ──┘         ├── ALUZO
        F5 ──┘                   │
        F6 ──┬── NOR ────────────┘
        F7 ──┘
```

### Варіант 2: Виправлення в симуляторі

Модифікувати файл `simulator/netlists/alu_hub.frp`:
1. Змінити підключення U9/U10 gates
2. Або додати новий компонент для Zero detection

### Варіант 3: Обхідний шлях в мікрокоді

Не рекомендується — потребує повного перепроектування мікрокоду.

---

## Файли для аналізу

| Файл | Опис |
|---|---|
| `simulator/netlists/alu_hub.frp` | Netlist ALU Hub (містить помилку) |
| `simulator/diag_jz.py` | Діагностика JZ інструкції |
| `simulator/diag_alu.py` | Діагностика ALU виходів |
| `schematics/alu_hub/` | KiCad схема ALU Hub |

---

## Історія змін

| Дата | Автор | Опис |
|---|---|---|
| 2026-01-13 | GitHub Copilot | Початкова діагностика та звіт |

---

## Додаток: Діагностичні скрипти

### diag_jz.py
Моніторить сигнал STATE10 (Zero flag) під час виконання тестової програми.

### diag_alu.py
Моніторить виходи ALU (F0-F7) та сигнали ZO/Z для аналізу логіки Zero detection.

### Запуск діагностики
```bash
cd /Users/nikitalenyk/Desktop/Cpu8/simulator
python3 diag_jz.py
python3 diag_alu.py
```

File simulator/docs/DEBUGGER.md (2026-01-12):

# Dragonfly 8b9m GDB CLI - Debugger Documentation

Interactive debugger for the CPU8 simulator with GDB-style commands.

## Quick Start

```bash
# Start debugger with ROM file
python debugger.py program.bin

# Execute command on startup
python debugger.py -c "run" program.bin

# Execute commands from file
python debugger.py -x commands.txt program.bin
```

## Architecture Notes

### Instruction Encoding

Instructions are 1, 2, or 3 bytes:
- **1-byte**: Opcode only (e.g., `nop`, `hlt`, `ret`)
- **2-byte**: Opcode + byte operand (e.g., `ldi zh, 0x10`)
- **3-byte**: Opcode + word operand (e.g., `ldi sp, 0xFFFE`, `call 0x000D`)

### Endianness

Word operands (16-bit addresses/values) are stored in **big-endian** format:
- High byte first, then low byte
- Example: `ldi sp, 0xFFFE` is encoded as `14 FF FE`
  - `0x14` = opcode
  - `0xFF` = high byte
  - `0xFE` = low byte

### Accumulator (AC)

The Accumulator (AC) is the **XL register** — they are the same physical register:
- `ac` and `xl` refer to the same 8-bit register
- The X register pair consists of XH (high byte) and XL/AC (low byte)

## Command Reference

### Execution Commands

| Command | Alias | Description |
|---|---|---|
| `run` | `r` | Start or restart the program |
| `nexti [count]` | `n`, `ni` | Execute next instruction(s) (full instruction) |
| `step [count]` | `s` | Step program (same as nexti) |
| `stepi [count]` | `si` | Step one clock cycle (more granular than nexti) |
| `continue` | `c` | Continue until breakpoint or halt |
| `reset` | - | Reset CPU to initial state |

#### Execution Granularity

The debugger provides three levels of execution control:

1. **`nexti`/`n`** — Execute a **full CPU instruction**
   - A 3-byte instruction (e.g., `ldi sp, 0xFFFE`) executes completely
   - PC advances by the instruction size (1, 2, or 3 bytes)

2. **`stepi`/`si`** — Execute one **clock cycle**
   - More granular than nexti
   - Useful for seeing CPU state mid-instruction

3. **`tick`/`t`** — Execute one **simulator tick**
   - Lowest level granularity
   - One clock cycle = period/2 ticks per phase

#### Examples
```
(gdb-dragonfly) run
(gdb-dragonfly) nexti 5        # Execute 5 full instructions
(gdb-dragonfly) stepi 10       # Execute 10 clock cycles
(gdb-dragonfly) continue       # Run until breakpoint
```

---

### Display Commands

| Command | Alias | Description |
|---|---|---|
| `info <what>` | `i` | Display various information |
| `registers` | `reg` | Display all CPU registers |
| `print <expr>` | `p` | Print register/expression value |
| `examine [/FMT] <addr>` | `x` | Examine memory |
| `disassemble [addr] [count]` | `dis` | Disassemble instructions |
| `list [addr]` | `l` | List disassembly around location |
| `backtrace [count]` | `bt` | Show execution history |
| `status` | - | Show CPU status |

#### Register Display

The `registers` command shows all CPU registers:

```
--------- Registers ----------
  PC = 0x0009   (    9)
  SP = 0xFFFE   (65534)

  X = 0x000C     XH=0x00 AC=0x0C
  Y = 0x0000     YH=0x00 YL=0x00
  Z = 0x0800     ZH=0x08 ZL=0x00

  FLAGS = 0b00000000  (0x00)
------------------------------
```

> The X register line shows AC (Accumulator) instead of XL because AC = XL.

#### Info Subcommands
```
info registers      (or: info reg, info r)   - Display all CPU registers
info breakpoints    (or: info b)             - List all breakpoints
info watches        (or: info w)             - List watch expressions
info program                                 - Show ROM and program info
info cpu                                     - Show CPU state
info components     (or: info comp, info c)  - List hardware components
info period                                  - Show clock period
```

#### Examine Format
Format: `/[count][format]`
- `b` - bytes
- `h` - halfwords (16-bit)
- `w` - words (32-bit)
- `i` - instructions

#### Examples
```
(gdb-dragonfly) info registers
(gdb-dragonfly) print pc
(gdb-dragonfly) x/16b 0x100     # Examine 16 bytes at 0x100
(gdb-dragonfly) x/8i 0x0        # Disassemble 8 instructions
(gdb-dragonfly) disassemble 0x100 20
```

---

### Breakpoint Commands

| Command | Alias | Description |
|---|---|---|
| `break <addr>` | `b` | Set breakpoint at address |
| `delete [id]` | `d` | Delete breakpoint(s) |
| `enable <id>` | - | Enable breakpoint |
| `disable <id>` | - | Disable breakpoint |

#### Examples
```
(gdb-dragonfly) break 0x100     # Set breakpoint
(gdb-dragonfly) info b          # List breakpoints
(gdb-dragonfly) delete 1        # Delete breakpoint #1
(gdb-dragonfly) delete          # Delete all breakpoints
```

---

### Watch Commands

| Command | Description |
|---|---|
| `watch <expr>` | Add watch expression |

#### Examples
```
(gdb-dragonfly) watch pc        # Watch program counter
(gdb-dragonfly) watch x         # Watch X register
(gdb-dragonfly) info watches    # Show all watches
```

---

### Low-Level Simulation Commands

| Command | Alias | Description |
|---|---|---|
| `tick [count]` | `t` | Execute simulator ticks (lowest level) |
| `period [value]` | - | Get/set clock period |
| `check [cycles]` | `sc` | Check for short circuits |

#### Simulation Levels

The CPU8 simulator operates at multiple levels:

```
┌─────────────────────────────────────────────────────────┐
│  nexti/n    Execute full instruction (1-3 bytes)        │
│             PC advances by instruction size             │
├─────────────────────────────────────────────────────────┤
│  stepi/si   Execute one clock cycle                     │
│             PC may advance by 1 byte                    │
├─────────────────────────────────────────────────────────┤
│  tick/t     Execute one simulator tick                  │
│             Lowest level (period/2 ticks = half cycle)  │
└─────────────────────────────────────────────────────────┘
```

- **tick**: Executes individual simulator ticks (lowest granularity)
- **period**: Controls simulator ticks per CPU clock cycle (default: 800)
- **check**: Runs simulation and checks for conflicts (short circuits) on rising clock edge

#### Examples
```
(gdb-dragonfly) tick            # Execute one simulator tick
(gdb-dragonfly) tick 100        # Execute 100 ticks
(gdb-dragonfly) period          # Show current period
(gdb-dragonfly) period 800      # Set period to 800 ticks
(gdb-dragonfly) check           # Check 1 clock cycle for short circuits
(gdb-dragonfly) check 10        # Check 10 clock cycles
(gdb-dragonfly) sc 100          # Check 100 cycles (alias)
```

---

### Network/Pin Read Commands

| Command | Description |
|---|---|
| `rn <network> [...]` | Read network value(s) |
| `rc <component> <pin>` | Read component pin by alias |
| `pins <component>` | Show all pins for component |
| `components [filter]` | List components |

#### Network Output Format
- `1` - HIGH (driven high)
- `0` - LOW (driven low)
- `Z` - FLOATING (not driven)
- `X` - CONFLICT (multiple drivers)

#### Range Specification
Use ` - ` (with spaces) to specify a range from high bit to low bit:
```
rn C3:/STATE16 - C3:/STATE0    # Read 17 bits (16 down to 0)
rn PC:/DATA7 - PC:/DATA0       # Read 8-bit bus
```

#### Examples
```
(gdb-dragonfly) rn C3:/STATE0!              # Single network
(gdb-dragonfly) rn NET1 NET2 NET3           # Multiple networks
(gdb-dragonfly) rn C3:/STATE16 - C3:/STATE0 # Range (17 bits)

(gdb-dragonfly) rc C1:DECODER1 Y0           # Read decoder output
(gdb-dragonfly) rc I:PAD2 CLOCK             # Read clock input
(gdb-dragonfly) rc I:PAD2 N_HALT            # Read halt signal

(gdb-dragonfly) pins C1:DECODER1            # Show all decoder pins
(gdb-dragonfly) pins I:PAD2                 # Show interface pins

(gdb-dragonfly) components                  # List all components
(gdb-dragonfly) components C1               # Filter by prefix
```

---

### Configuration Commands

| Command | Description |
|---|---|
| `set disasm on\|off` | Toggle auto-disassembly |
| `set context <count>` | Set disassembly context lines |
| `set period <ticks>` | Set clock period |
| `set var <comp> <var> <val>` | Set component variable |

#### Examples
```
(gdb-dragonfly) set disasm off              # Disable auto-disassembly
(gdb-dragonfly) set context 10              # Show 10 context lines
(gdb-dragonfly) set period 800              # Set clock period
(gdb-dragonfly) set var I:PAD2 RESET 1      # Set RESET high
(gdb-dragonfly) set var I:PAD2 WAIT 0       # Set WAIT low
```

---

### Other Commands

| Command | Alias | Description |
|---|---|---|
| `quit` | `q` | Exit debugger |
| `help [command]` | - | Show help |

---

## Available Registers

| Register | Description |
|---|---|
| `pc` | Program Counter (16-bit) |
| `sp` | Stack Pointer (16-bit) |
| `ac` | Accumulator (same as `xl`) |
| `x`, `xh`, `xl` | X register pair and bytes (XL = Accumulator) |
| `y`, `yh`, `yl` | Y register pair and bytes |
| `z`, `zh`, `zl` | Z register pair and bytes |
| `flags`, `fr` | Flags register |

> **Note:** The Accumulator (AC) is the same physical register as XL.
> In the register display, it appears as `X = 0x00XX  XH=0x00 AC=0xXX`.

---

## Component Naming Convention

Components use the format `MODULE:COMPONENT`:

| Module | Description |
|---|---|
| `ALU` | ALU hub |
| `C1` | Core 1 (instruction decoder) |
| `C2` | Core 2 |
| `C3` | Core 3 (microcode) |
| `I` | Interface (external connections) |
| `PC` | Program counter |
| `REG` | Register file |
| `SP` | Stack pointer |

---

## Tips

1. **Empty line** repeats the last command (like GDB)
2. **Tab completion** works for commands
3. Use `help <command>` for detailed help on any command
4. Network names usually end with `!` - it's added automatically if missing
5. Use `info components` to discover available component names
6. Use `pins <component>` to see available pin aliases

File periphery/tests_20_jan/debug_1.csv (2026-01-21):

time | data | state | pcinc | not_scclear | not_instread | clk | not_enable | direction
904 | 0 | 130 | 0 | 1 | 0 | 0 | 1 | 0
2860 | 0 | 130 | 0 | 1 | 0 | 0 | 1 | 0
4900 | 0 | 130 | 0 | 1 | 0 | 0 | 1 | 0
6940 | 0 | 130 | 0 | 1 | 0 | 0 | 1 | 0
8980 | 0 | 130 | 0 | 1 | 0 | 0 | 1 | 0
11020 | 0 | 130 | 0 | 1 | 0 | 0 | 1 | 0
13144 | 0 | 130 | 0 | 1 | 0 | 0 | 1 | 0
15272 | 0 | 130 | 0 | 1 | 0 | 0 | 1 | 0
17396 | 0 | 130 | 0 | 1 | 0 | 0 | 1 | 0
19528 | 0 | 130 | 0 | 1 | 0 | 0 | 1 | 0
21644 | 0 | 130 | 0 | 1 | 0 | 0 | 1 | 0
23772 | 0 | 130 | 0 | 1 | 0 | 0 | 1 | 0
25896 | 0 | 130 | 0 | 1 | 0 | 0 | 1 | 0
28020 | 0 | 130 | 0 | 1 | 0 | 0 | 1 | 0
30144 | 0 | 130 | 0 | 1 | 0 | 0 | 1 | 0
32272 | 0 | 130 | 0 | 1 | 0 | 0 | 1 | 0
34396 | 0 | 130 | 0 | 1 | 0 | 0 | 1 | 0
36520 | 0 | 130 | 0 | 1 | 0 | 0 | 1 | 0
38644 | 0 | 130 | 0 | 1 | 0 | 0 | 1 | 0
40772 | 0 | 130 | 0 | 1 | 0 | 0 | 1 | 0
42896 | 0 | 130 | 0 | 1 | 0 | 0 | 1 | 0
45020 | 0 | 130 | 0 | 1 | 0 | 0 | 1 | 0
47152 | 0 | 130 | 0 | 1 | 0 | 0 | 1 | 0
49272 | 0 | 130 | 0 | 1 | 0 | 0 | 1 | 0
51396 | 0 | 130 | 0 | 1 | 0 | 0 | 1 | 0
53520 | 0 | 130 | 0 | 1 | 0 | 0 | 1 | 0
55644 | 0 | 130 | 0 | 1 | 0 | 0 | 1 | 0
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

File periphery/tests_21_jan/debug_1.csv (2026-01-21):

time | data | state | pcinc | not_scclear | not_instread | clk | not_enable | direction
904 | 0 | 132 | 0 | 1 | 0 | 0 | 1 | 0
2860 | 0 | 132 | 0 | 1 | 0 | 0 | 1 | 0
4900 | 0 | 132 | 0 | 1 | 0 | 0 | 1 | 0
6940 | 0 | 132 | 0 | 1 | 0 | 0 | 1 | 0
8980 | 0 | 132 | 0 | 1 | 0 | 0 | 1 | 0
11020 | 0 | 132 | 0 | 1 | 0 | 0 | 1 | 0
13144 | 0 | 132 | 0 | 1 | 0 | 0 | 1 | 0
15272 | 0 | 132 | 0 | 1 | 0 | 0 | 1 | 0
17396 | 0 | 132 | 0 | 1 | 0 | 0 | 1 | 0
19528 | 0 | 132 | 0 | 1 | 0 | 0 | 1 | 0
21644 | 0 | 132 | 0 | 1 | 0 | 0 | 1 | 0
23772 | 0 | 132 | 0 | 1 | 0 | 0 | 1 | 0
25896 | 0 | 132 | 0 | 1 | 0 | 0 | 1 | 0
28020 | 0 | 132 | 0 | 1 | 0 | 0 | 1 | 0
30144 | 0 | 132 | 0 | 1 | 0 | 0 | 1 | 0
32272 | 0 | 132 | 0 | 1 | 0 | 0 | 1 | 0
34396 | 0 | 132 | 0 | 1 | 0 | 0 | 1 | 0
36520 | 0 | 132 | 0 | 1 | 0 | 0 | 1 | 0
38644 | 0 | 132 | 0 | 1 | 0 | 0 | 1 | 0
40772 | 0 | 132 | 0 | 1 | 0 | 0 | 1 | 0
42896 | 0 | 132 | 0 | 1 | 0 | 0 | 1 | 0
45020 | 0 | 132 | 0 | 1 | 0 | 0 | 1 | 0
47152 | 0 | 132 | 0 | 1 | 0 | 0 | 1 | 0
49272 | 0 | 132 | 0 | 1 | 0 | 0 | 1 | 0
51396 | 0 | 132 | 0 | 1 | 0 | 0 | 1 | 0
53520 | 0 | 132 | 0 | 1 | 0 | 0 | 1 | 0
55644 | 0 | 132 | 0 | 1 | 0 | 0 | 1 | 0
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

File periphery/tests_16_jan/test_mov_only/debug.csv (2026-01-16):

time | data | state | pcinc | not_scclear | not_instread | clk
556 | 0 | 128 | 0 | 1 | 1 | 0
1360 | 0 | 128 | 0 | 1 | 1 | 0
2428 | 0 | 128 | 0 | 1 | 1 | 0
4132 | 0 | 128 | 0 | 1 | 1 | 0
5828 | 0 | 128 | 0 | 1 | 1 | 0
7528 | 0 | 128 | 0 | 1 | 1 | 0
9232 | 0 | 128 | 0 | 1 | 1 | 0
10928 | 0 | 128 | 0 | 1 | 1 | 0
12712 | 0 | 128 | 0 | 1 | 1 | 0
14496 | 0 | 128 | 0 | 1 | 1 | 0
16284 | 0 | 128 | 0 | 1 | 1 | 0
18068 | 0 | 128 | 0 | 1 | 1 | 0
19852 | 0 | 128 | 0 | 1 | 1 | 0
21636 | 0 | 128 | 0 | 1 | 1 | 0
23424 | 0 | 128 | 0 | 1 | 1 | 0
25208 | 0 | 128 | 0 | 1 | 1 | 0
26992 | 0 | 128 | 0 | 1 | 1 | 0
28784 | 0 | 128 | 0 | 1 | 1 | 0
30564 | 0 | 128 | 0 | 1 | 1 | 0
32348 | 0 | 128 | 0 | 1 | 1 | 0
34132 | 0 | 128 | 0 | 1 | 1 | 0
35924 | 0 | 128 | 0 | 1 | 1 | 0
37700 | 0 | 128 | 0 | 1 | 1 | 0
39488 | 0 | 128 | 0 | 1 | 1 | 0
41272 | 0 | 128 | 0 | 1 | 1 | 0
43064 | 0 | 128 | 0 | 1 | 1 | 0
44844 | 0 | 128 | 0 | 1 | 1 | 0
46628 | 0 | 128 | 0 | 1 | 1 | 0
48412 | 0 | 128 | 0 | 1 | 1 | 0
50204 | 0 | 128 | 0 | 1 | 1 | 0
51980 | 0 | 128 | 0 | 1 | 1 | 0
53768 | 0 | 128 | 0 | 1 | 1 | 0
55552 | 0 | 128 | 0 | 1 | 1 | 0
57336 | 0 | 128 | 0 | 1 | 1 | 0
59124 | 0 | 128 | 0 | 1 | 1 | 0
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

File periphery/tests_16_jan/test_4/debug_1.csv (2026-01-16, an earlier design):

time | data | state | pcinc | not_scclear | not_instread | clk
556 | 16 | 248 | 0 | 1 | 1 | 0
1412 | 16 | 248 | 0 | 1 | 1 | 0
2596 | 16 | 248 | 0 | 1 | 1 | 0
4384 | 16 | 248 | 0 | 1 | 1 | 0
6172 | 16 | 248 | 0 | 1 | 1 | 0
7952 | 16 | 248 | 0 | 1 | 1 | 0
9736 | 16 | 248 | 0 | 1 | 1 | 0
11520 | 16 | 248 | 0 | 1 | 1 | 0
13400 | 16 | 248 | 0 | 1 | 1 | 0
15264 | 16 | 248 | 0 | 1 | 1 | 0
17132 | 16 | 248 | 0 | 1 | 1 | 0
19000 | 16 | 248 | 0 | 1 | 1 | 0
20872 | 16 | 248 | 0 | 1 | 1 | 0
22744 | 16 | 248 | 0 | 1 | 1 | 0
24620 | 16 | 248 | 0 | 1 | 1 | 0
26484 | 16 | 248 | 0 | 1 | 1 | 0
28352 | 16 | 248 | 0 | 1 | 1 | 0
30220 | 16 | 248 | 0 | 1 | 1 | 0
32092 | 16 | 248 | 0 | 1 | 1 | 0
33960 | 16 | 248 | 0 | 1 | 1 | 0
35832 | 16 | 248 | 0 | 1 | 1 | 0
37704 | 16 | 248 | 0 | 1 | 1 | 0
39572 | 16 | 248 | 0 | 1 | 1 | 0
41444 | 16 | 248 | 0 | 1 | 1 | 0
43312 | 16 | 248 | 0 | 1 | 1 | 0
45184 | 16 | 248 | 0 | 1 | 1 | 0
47052 | 16 | 248 | 0 | 1 | 1 | 0
48924 | 16 | 248 | 0 | 1 | 1 | 0
50792 | 16 | 248 | 0 | 1 | 1 | 0
52660 | 16 | 248 | 0 | 1 | 1 | 0
54532 | 16 | 248 | 0 | 1 | 1 | 0
56408 | 16 | 248 | 0 | 1 | 1 | 0
58272 | 16 | 248 | 0 | 1 | 1 | 0
60144 | 16 | 248 | 0 | 1 | 1 | 0
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

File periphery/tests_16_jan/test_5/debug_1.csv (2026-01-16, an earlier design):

time | data | state | pcinc | not_scclear | not_instread | clk
556 | 16 | 248 | 0 | 1 | 0 | 0
1412 | 16 | 248 | 0 | 1 | 0 | 0
2596 | 16 | 248 | 0 | 1 | 0 | 0
4384 | 16 | 248 | 0 | 1 | 0 | 0
6172 | 16 | 248 | 0 | 1 | 0 | 0
7952 | 16 | 248 | 0 | 1 | 0 | 0
9736 | 16 | 248 | 0 | 1 | 0 | 0
11520 | 16 | 248 | 0 | 1 | 0 | 0
13400 | 16 | 248 | 0 | 1 | 0 | 0
15264 | 16 | 248 | 0 | 1 | 0 | 0
17132 | 16 | 248 | 0 | 1 | 0 | 0
19000 | 16 | 248 | 0 | 1 | 0 | 0
20872 | 16 | 248 | 0 | 1 | 0 | 0
22744 | 16 | 248 | 0 | 1 | 0 | 0
24620 | 16 | 248 | 0 | 1 | 0 | 0
26484 | 16 | 248 | 0 | 1 | 0 | 0
28352 | 16 | 248 | 0 | 1 | 0 | 0
30220 | 16 | 248 | 0 | 1 | 0 | 0
32092 | 16 | 248 | 0 | 1 | 0 | 0
33960 | 16 | 248 | 0 | 1 | 0 | 0
35832 | 16 | 248 | 0 | 1 | 0 | 0
37704 | 16 | 248 | 0 | 1 | 0 | 0
39572 | 16 | 248 | 0 | 1 | 0 | 0
41444 | 16 | 248 | 0 | 1 | 0 | 0
43312 | 16 | 248 | 0 | 1 | 0 | 0
45184 | 16 | 248 | 0 | 1 | 0 | 0
47052 | 16 | 248 | 0 | 1 | 0 | 0
48924 | 16 | 248 | 0 | 1 | 0 | 0
50792 | 16 | 248 | 0 | 1 | 0 | 0
52660 | 16 | 248 | 0 | 1 | 0 | 0
54532 | 16 | 248 | 0 | 1 | 0 | 0
56408 | 16 | 248 | 0 | 1 | 0 | 0
58272 | 16 | 248 | 0 | 1 | 0 | 0
60144 | 16 | 248 | 0 | 1 | 0 | 0
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

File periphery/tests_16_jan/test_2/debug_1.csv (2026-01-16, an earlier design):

time | data | state | pcinc | not_scclear | not_instread | clk
556 | 0 | 128 | 0 | 1 | 1 | 0
1360 | 0 | 128 | 0 | 1 | 1 | 0
2428 | 0 | 128 | 0 | 1 | 1 | 0
4132 | 0 | 128 | 0 | 1 | 1 | 0
5828 | 0 | 128 | 0 | 1 | 1 | 0
7528 | 0 | 128 | 0 | 1 | 1 | 0
9232 | 0 | 128 | 0 | 1 | 1 | 0
10928 | 0 | 128 | 0 | 1 | 1 | 0
12712 | 0 | 128 | 0 | 1 | 1 | 0
14496 | 0 | 128 | 0 | 1 | 1 | 0
16284 | 0 | 128 | 0 | 1 | 1 | 0
18068 | 0 | 128 | 0 | 1 | 1 | 0
19852 | 0 | 128 | 0 | 1 | 1 | 0
21636 | 0 | 128 | 0 | 1 | 1 | 0
23424 | 0 | 128 | 0 | 1 | 1 | 0
25208 | 0 | 128 | 0 | 1 | 1 | 0
26992 | 0 | 128 | 0 | 1 | 1 | 0
28784 | 0 | 128 | 0 | 1 | 1 | 0
30564 | 0 | 128 | 0 | 1 | 1 | 0
32348 | 0 | 128 | 0 | 1 | 1 | 0
34132 | 0 | 128 | 0 | 1 | 1 | 0
35924 | 0 | 128 | 0 | 1 | 1 | 0
37700 | 0 | 128 | 0 | 1 | 1 | 0
39488 | 0 | 128 | 0 | 1 | 1 | 0
41272 | 0 | 128 | 0 | 1 | 1 | 0
43064 | 0 | 128 | 0 | 1 | 1 | 0
44844 | 0 | 128 | 0 | 1 | 1 | 0
46628 | 0 | 128 | 0 | 1 | 1 | 0
48412 | 0 | 128 | 0 | 1 | 1 | 0
50204 | 0 | 128 | 0 | 1 | 1 | 0
51980 | 0 | 128 | 0 | 1 | 1 | 0
53768 | 0 | 128 | 0 | 1 | 1 | 0
55552 | 0 | 128 | 0 | 1 | 1 | 0
57336 | 0 | 128 | 0 | 1 | 1 | 0
59124 | 0 | 128 | 0 | 1 | 1 | 0
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

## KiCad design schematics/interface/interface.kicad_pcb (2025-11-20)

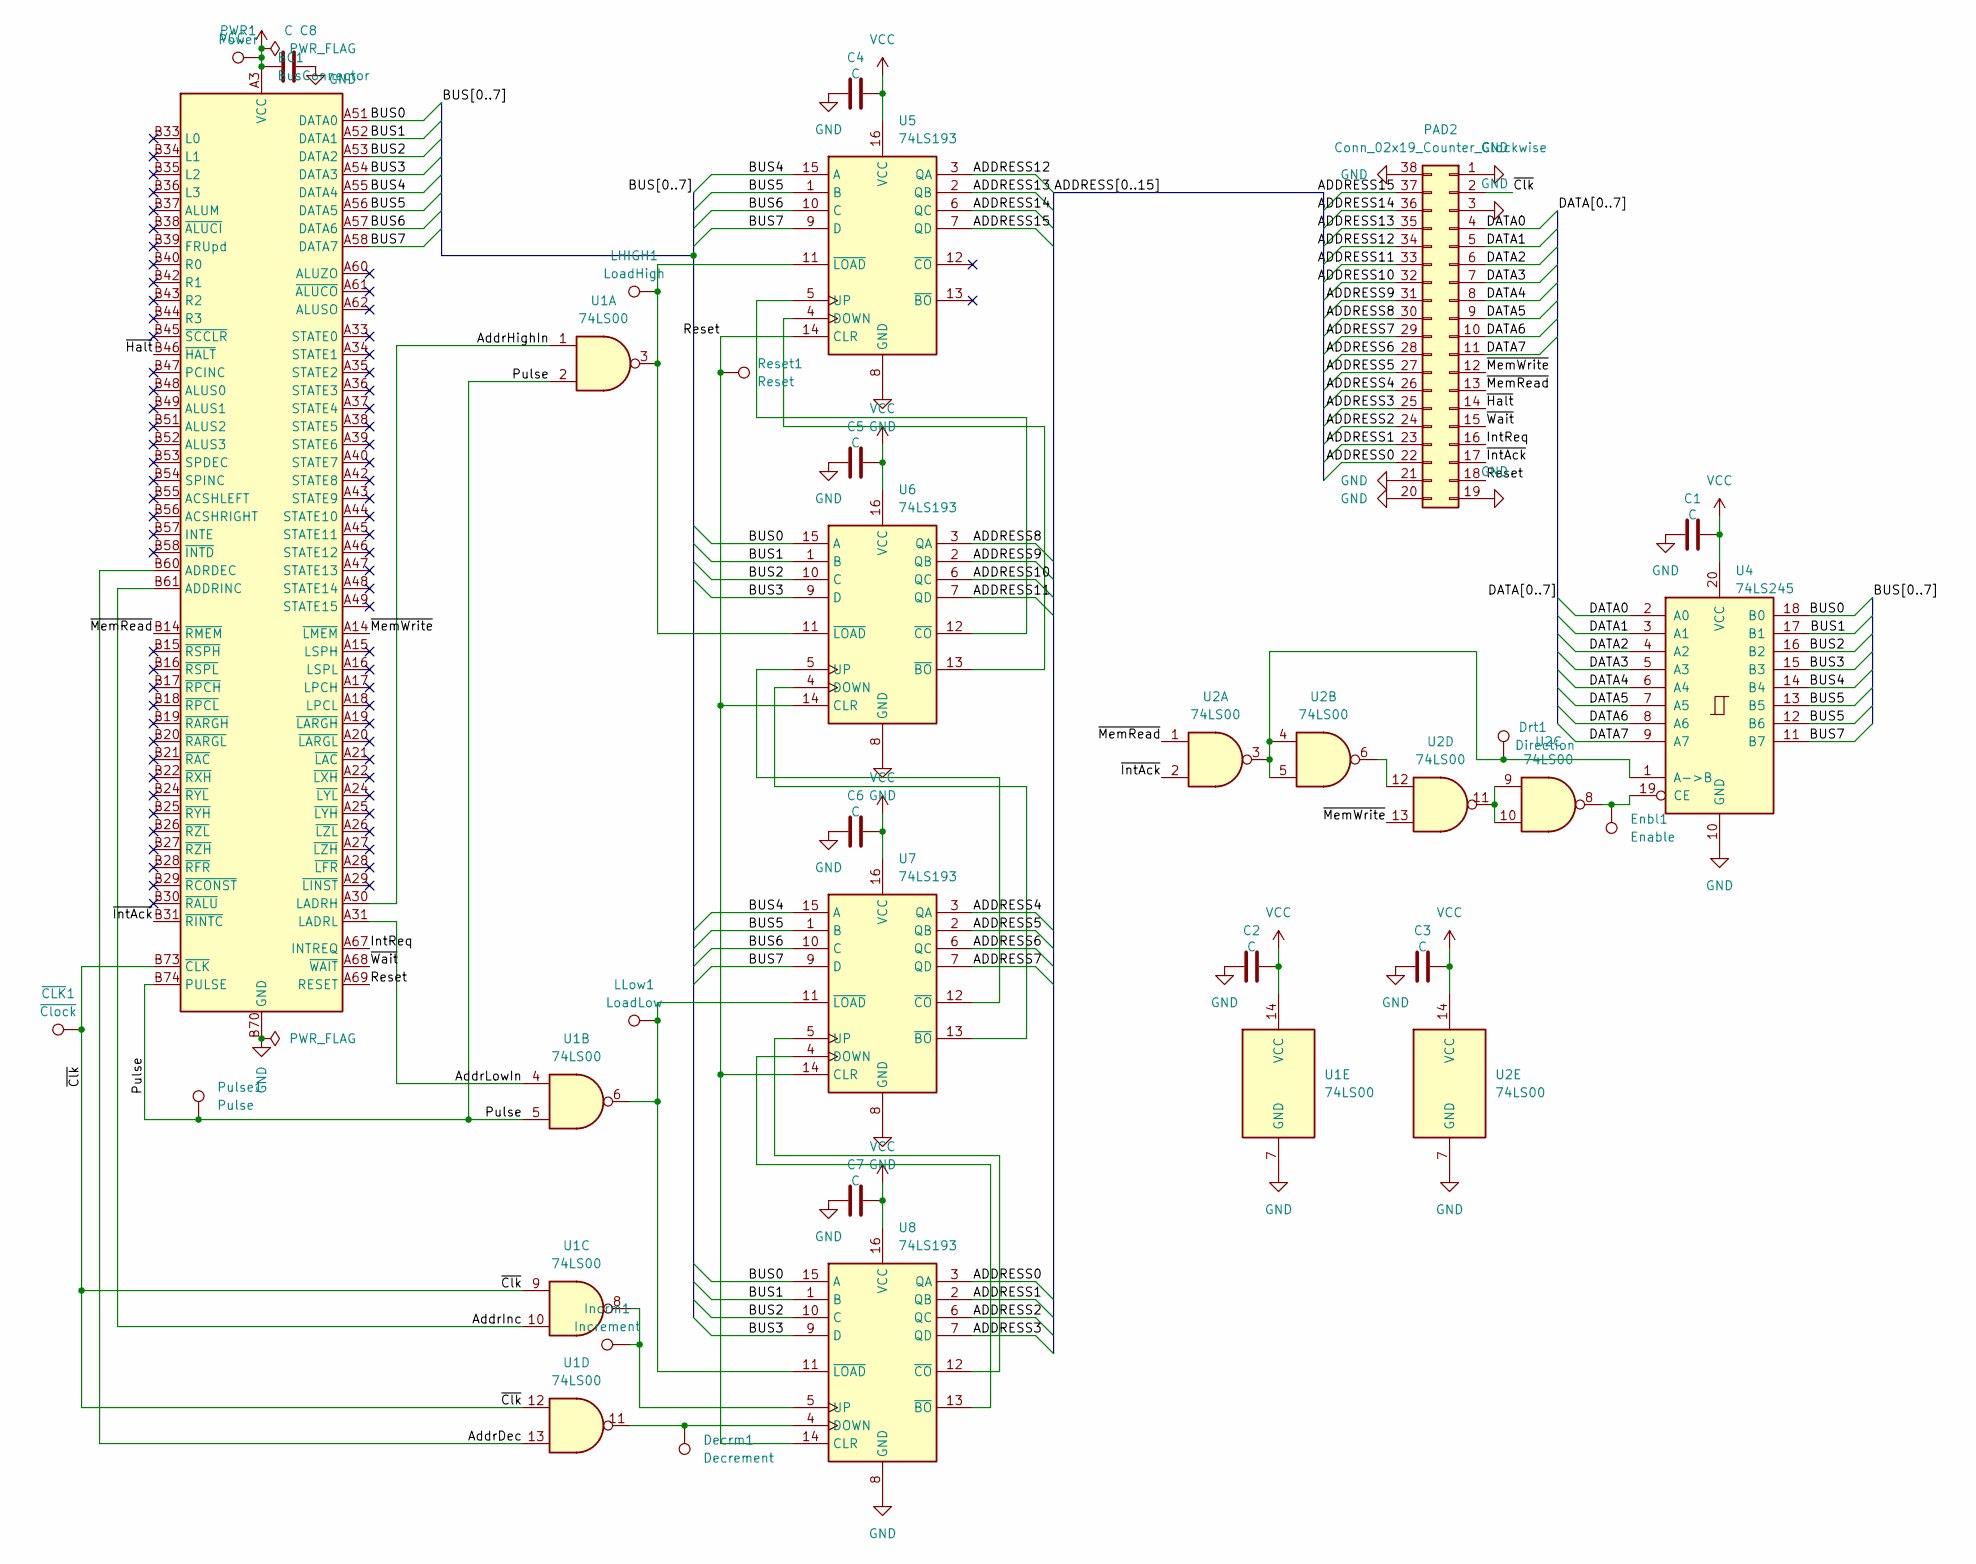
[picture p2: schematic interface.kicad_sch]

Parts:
BC1: BusConnector; BUS_PCIexpress_x16
C1, C2, C3, C4, C5, C6, C7: C; C_Disc_D5.0mm_W2.5mm_P5.00mm
C8: C; C_Radial_D6.3mm_H5.0mm_P2.50mm
Decrm1: Decrement; TestPoint_Pad_D1.0mm
Drt1: Direction; TestPoint_Pad_D1.0mm
Enbl1: Enable; TestPoint_Pad_D1.0mm
Incrm1: Increment; TestPoint_Pad_D1.0mm
LHIGH1: LoadHigh; TestPoint_Pad_D1.0mm
LLow1: LoadLow; TestPoint_Pad_D1.0mm
PAD2: Conn_02x19_Counter_Clockwise; PinSocket_2x19_P2.54mm_Vertical
PWR1: Power; TestPoint_Pad_D1.0mm
Pulse1: Pulse; TestPoint_Pad_D1.0mm
Reset1: Reset; TestPoint_Pad_D1.0mm
U1, U2: 74LS00; DIP-14_W7.62mm_Socket_LongPads
U4: 74LS245; DIP-20_W7.62mm_Socket_LongPads
U5, U6, U7, U8: 74LS193; DIP-16_W7.62mm_Socket_LongPads
~{CLK}1: ~{Clock}; TestPoint_Pad_D1.0mm

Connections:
/ADDRESS0: PAD2.22, U8.3 (QA)
/ADDRESS1: PAD2.23, U8.2 (QB)
/ADDRESS2: PAD2.24, U8.6 (QC)
/ADDRESS3: PAD2.25, U8.7 (QD)
/ADDRESS4: PAD2.26, U7.3 (QA)
/ADDRESS5: PAD2.27, U7.2 (QB)
/ADDRESS6: PAD2.28, U7.6 (QC)
/ADDRESS7: PAD2.29, U7.7 (QD)
/ADDRESS8: PAD2.30, U6.3 (QA)
/ADDRESS9: PAD2.31, U6.2 (QB)
/ADDRESS10: PAD2.32, U6.6 (QC)
/ADDRESS11: PAD2.33, U6.7 (QD)
/ADDRESS12: PAD2.34, U5.3 (QA)
/ADDRESS13: PAD2.35, U5.2 (QB)
/ADDRESS14: PAD2.36, U5.6 (QC)
/ADDRESS15: PAD2.37, U5.7 (QD)
/AddrDec: BC1.B60 (ADRDEC), U1.13
/AddrHighIn: BC1.A30 (LADRH), U1.1
/AddrInc: BC1.B61 (ADDRINC), U1.10
/AddrLowIn: BC1.A31 (LADRL), U1.4
/BUS0: BC1.A51 (DATA0), U4.18 (B0), U6.15 (A), U8.15 (A)
/BUS1: BC1.A52 (DATA1), U4.17 (B1), U6.1 (B), U8.1 (B)
/BUS2: BC1.A53 (DATA2), U4.16 (B2), U6.10 (C), U8.10 (C)
/BUS3: BC1.A54 (DATA3), U4.15 (B3), U6.9 (D), U8.9 (D)
/BUS4: BC1.A55 (DATA4), U4.14 (B4), U5.15 (A), U7.15 (A)
/BUS5: BC1.A56 (DATA5), U4.12 (B6), U4.13 (B5), U5.1 (B), U7.1 (B)
/BUS6: BC1.A57 (DATA6), U5.10 (C), U7.10 (C)
/BUS7: BC1.A58 (DATA7), U4.11 (B7), U5.9 (D), U7.9 (D)
/DATA0: PAD2.4, U4.2 (A0)
/DATA1: PAD2.5, U4.3 (A1)
/DATA2: PAD2.6, U4.4 (A2)
/DATA3: PAD2.7, U4.5 (A3)
/DATA4: PAD2.8, U4.6 (A4)
/DATA5: PAD2.9, U4.7 (A5)
/DATA6: PAD2.10, U4.8 (A6)
/DATA7: PAD2.11, U4.9 (A7)
/IntReq: BC1.A67 (INTREQ), PAD2.16
/Pulse: BC1.B74 (PULSE), Pulse1.1, U1.2, U1.5
/Reset: BC1.A69 (RESET), PAD2.18, Reset1.1, U5.14 (CLR), U6.14 (CLR), U7.14 (CLR), U8.14 (CLR)
/~Clk: BC1.B73 (~CLK), PAD2.2, U1.9, U1.12, ~{CLK}1.1
/~Halt: BC1.B46 (~HALT), PAD2.14
/~IntAck: BC1.B31 (~RINTC), PAD2.17, U2.2
/~MemRead: BC1.B14 (~RMEM), PAD2.13, U2.1
/~MemWrite: BC1.A14 (~LMEM), PAD2.12, U2.13
/~Wait: BC1.A68 (~WAIT), PAD2.15
GND: BC1.A12 (GND), BC1.A13 (GND), BC1.A23 (GND), BC1.A32 (GND), BC1.A41 (GND), BC1.A50 (GND), BC1.A59 (GND), BC1.A63 (GND), BC1.A64 (GND), BC1.A65 (GND), BC1.A66 (GND), BC1.A70 (GND), BC1.A71 (GND), BC1.A72 (GND), BC1.A73 (GND), BC1.A74 (GND), BC1.A75 (GND), BC1.A76 (GND), BC1.B12 (GND), BC1.B13 (GND), BC1.B23 (GND), BC1.B32 (GND), BC1.B41 (GND), BC1.B50 (GND), BC1.B59 (GND), BC1.B62 (GND), BC1.B63 (GND), BC1.B64 (GND), BC1.B65 (GND), BC1.B66 (GND), BC1.B67 (GND), BC1.B68 (GND), BC1.B69 (GND), BC1.B70 (GND), BC1.B71 (GND), BC1.B72 (GND), BC1.B75 (GND), BC1.B76 (GND), C1.2, C2.2, C3.2, C4.2, C5.2, C6.2, C7.2, C8.2, PAD2.1, PAD2.3, PAD2.19, PAD2.20, PAD2.21, PAD2.38, U1.7 (GND), U2.7 (GND), U4.10 (GND), U5.8 (GND), U6.8 (GND), U7.8 (GND), U8.8 (GND)
unnamed: U2.9, U2.10, U2.11
unnamed: U2.6, U2.12
unnamed: Drt1.1, U2.3, U2.4, U2.5, U4.1 (A->B)
unnamed: Enbl1.1, U2.8, U4.19 (CE)
unnamed: U5.4 (DOWN), U6.13 (~BO)
unnamed: U5.5 (UP), U6.12 (~CO)
unnamed: LHIGH1.1, U1.3, U5.11 (~LOAD), U6.11 (~LOAD)
unnamed: U6.4 (DOWN), U7.13 (~BO)
unnamed: U6.5 (UP), U7.12 (~CO)
unnamed: U7.4 (DOWN), U8.13 (~BO)
unnamed: U7.5 (UP), U8.12 (~CO)
unnamed: LLow1.1, U1.6, U7.11 (~LOAD), U8.11 (~LOAD)
unnamed: Decrm1.1, U1.11, U8.4 (DOWN)
unnamed: Incrm1.1, U1.8, U8.5 (UP)
VCC: BC1.A1 (VCC), BC1.A2 (VCC), BC1.A3 (VCC), BC1.A4 (VCC), BC1.A5 (VCC), BC1.B1 (VCC), BC1.B2 (VCC), BC1.B3 (VCC), BC1.B4 (VCC), BC1.B5 (VCC), C1.1, C2.1, C3.1, C4.1, C5.1, C6.1, C7.1, C8.1, PWR1.1, U1.14 (VCC), U2.14 (VCC), U4.20 (VCC), U5.16 (VCC), U6.16 (VCC), U7.16 (VCC), U8.16 (VCC)

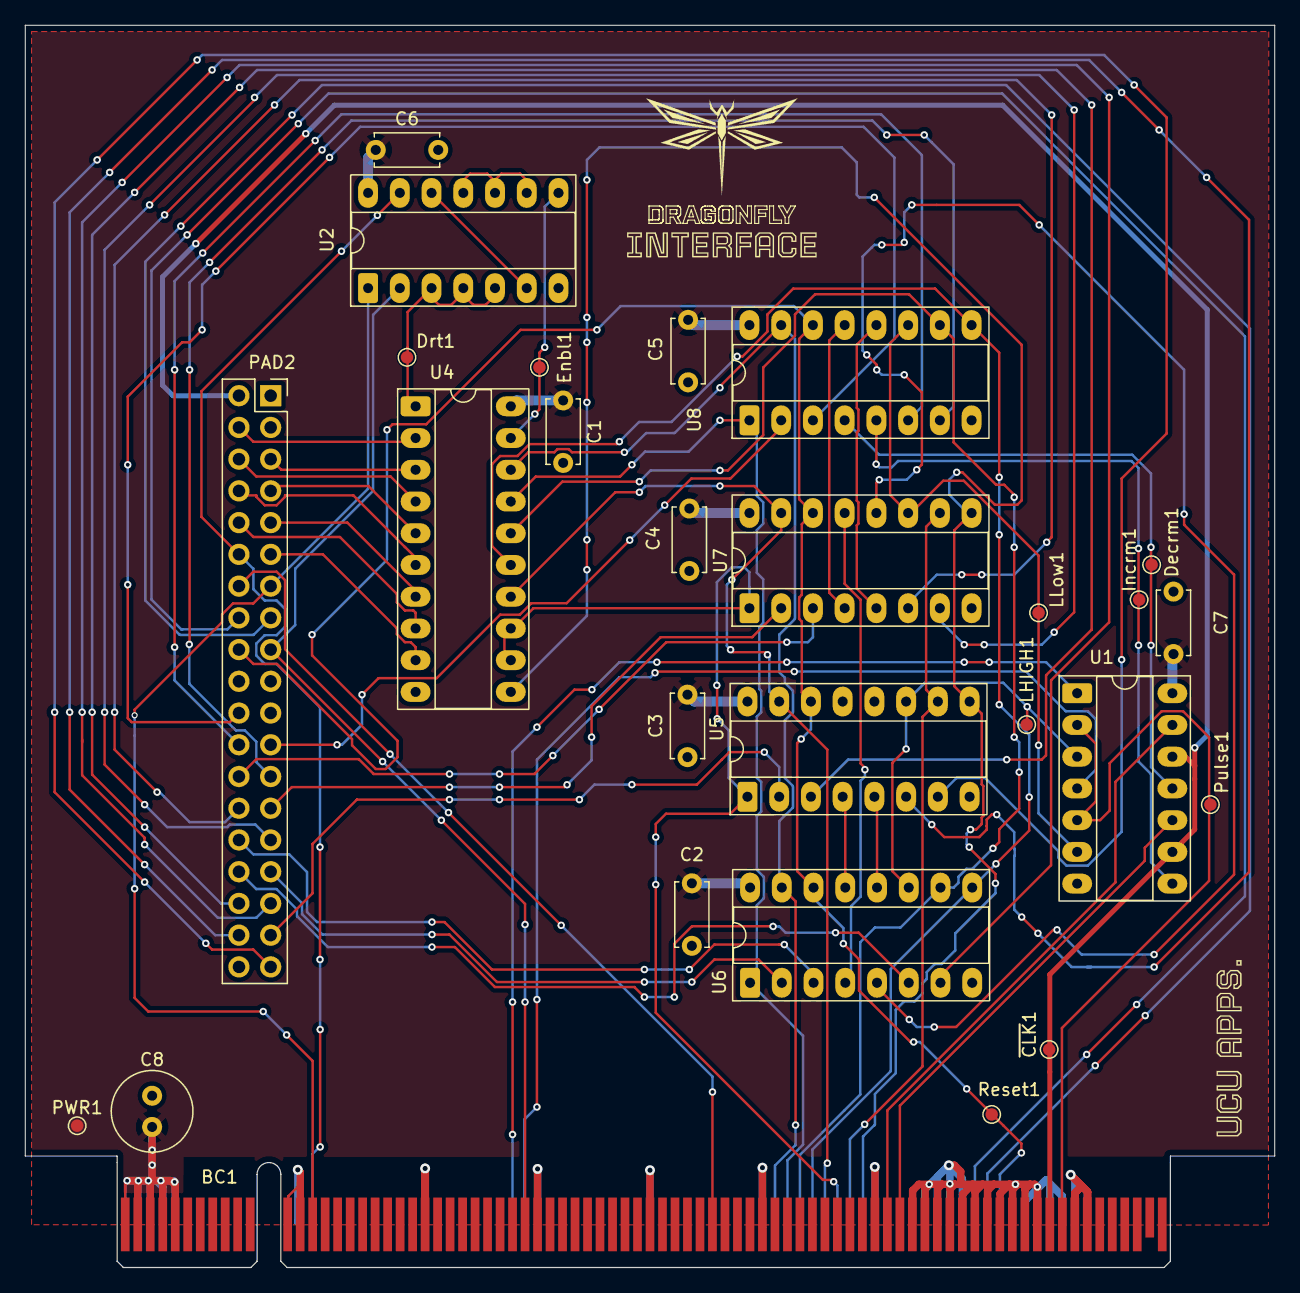
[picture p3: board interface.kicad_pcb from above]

Board: 2 copper layers, 100.0 x 99.4 mm, 28 parts (0 on the bottom side), 61 nets.

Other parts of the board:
kibuzzard-691DE158: G***; kibuzzard-691DE158
kibuzzard-6911D1BC: G***; kibuzzard-6911D1BC

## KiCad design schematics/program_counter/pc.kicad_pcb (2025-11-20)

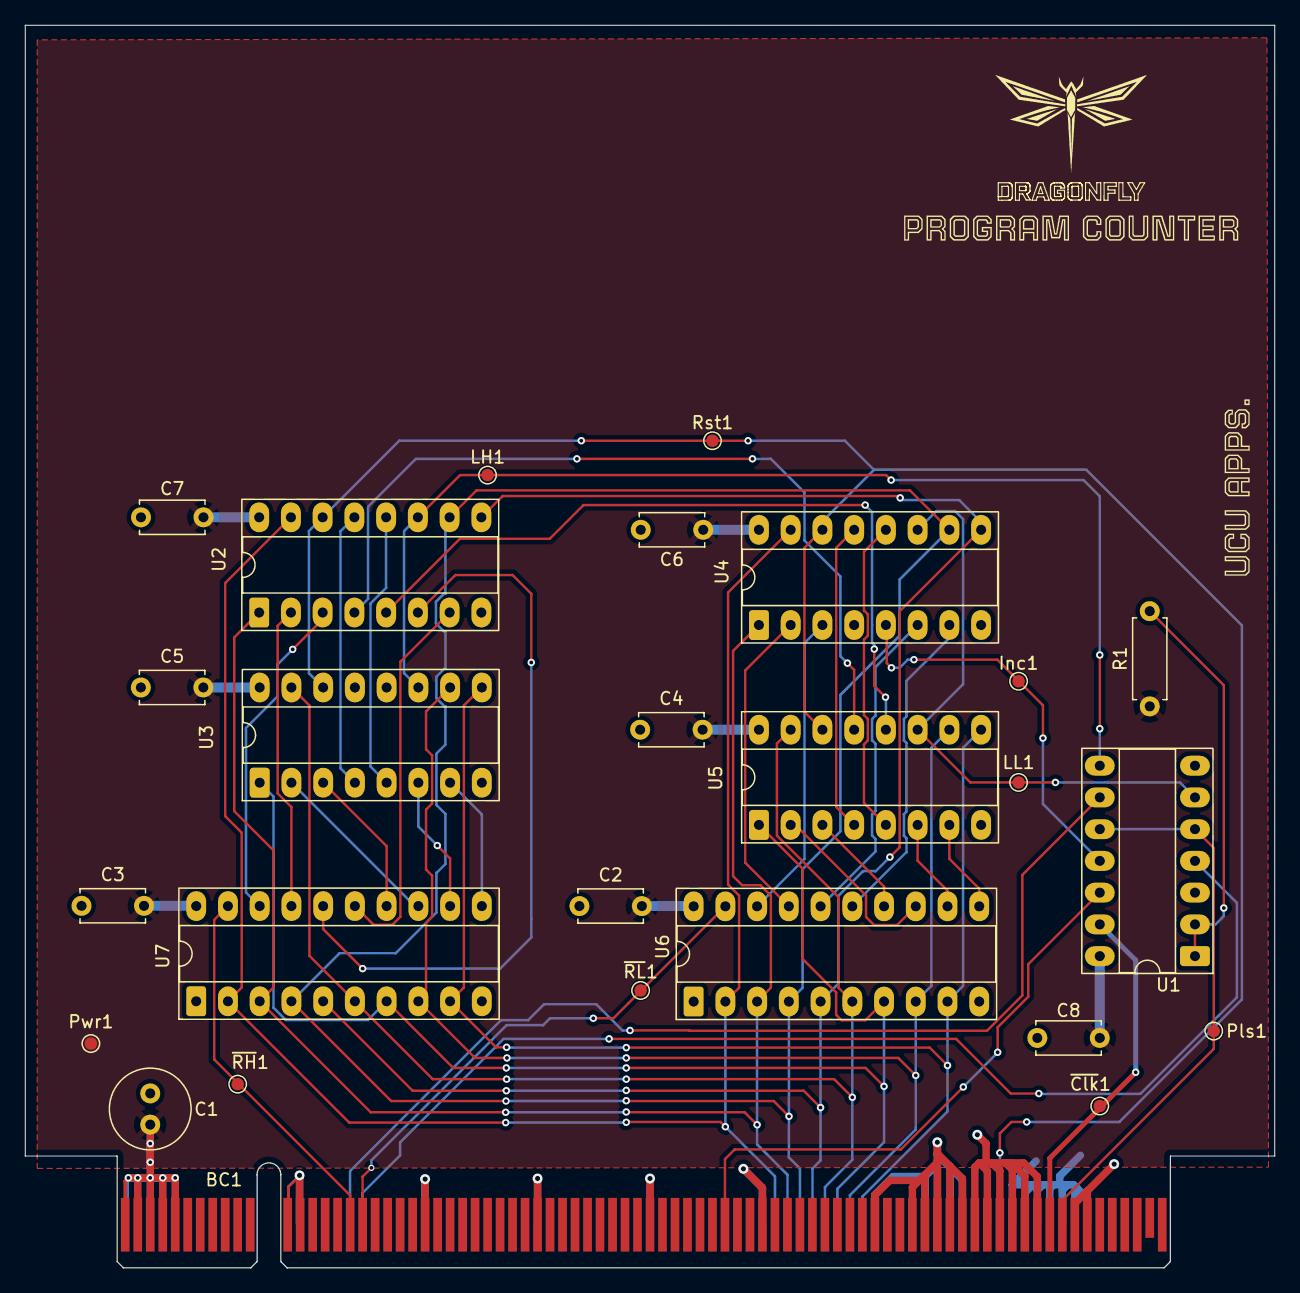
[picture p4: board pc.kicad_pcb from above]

Board: 2 copper layers, 100.0 x 99.4 mm, 25 parts (0 on the bottom side), 44 nets.

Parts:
BC1: BusConnector; BUS_PCIexpress_x16
C1: C; C_Radial_D6.3mm_H5.0mm_P2.50mm
C2, C3, C4, C5, C6, C7, C8: C; C_Disc_D5.0mm_W2.5mm_P5.00mm
Inc1: Increment; TestPoint_Pad_D1.0mm
LH1: LoadHigh; TestPoint_Pad_D1.0mm
LL1: LoadLow; TestPoint_Pad_D1.0mm
Pls1: Pulse; TestPoint_Pad_D1.0mm
Pwr1: Power; TestPoint_Pad_D1.0mm
R1: R; R_Axial_DIN0207_L6.3mm_D2.5mm_P7.62mm_Horizontal
Rst1: Reset; TestPoint_Pad_D1.0mm
U1: 74HC00; DIP-14_W7.62mm_Socket_LongPads
U2, U3, U4, U5: 74HC193; DIP-16_W7.62mm_Socket_LongPads
U6, U7: 74HC245; DIP-20_W7.62mm_Socket_LongPads
kibuzzard-691DE17B: G***; kibuzzard-691DE17B
kibuzzard-6911BE41: G***; kibuzzard-6911BE41

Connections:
/CPu: Inc1.1, U1.11, U4.5 (UP)
/DATA0: BC1.A51 (DATA0), U2.15 (A), U4.15 (A), U6.2 (A0), U7.2 (A0)
/DATA1: BC1.A52 (DATA1), U2.1 (B), U4.1 (B), U6.3 (A1), U7.3 (A1)
/DATA2: BC1.A53 (DATA2), U2.10 (C), U4.10 (C), U6.4 (A2), U7.4 (A2)
/DATA3: BC1.A54 (DATA3), U2.9 (D), U4.9 (D), U6.5 (A3), U7.5 (A3)
/DATA4: BC1.A55 (DATA4), U3.15 (A), U5.15 (A), U6.6 (A4), U7.6 (A4)
/DATA5: BC1.A56 (DATA5), U3.1 (B), U5.1 (B), U6.7 (A5), U7.7 (A5)
/DATA6: BC1.A57 (DATA6), U3.10 (C), U5.10 (C), U6.8 (A6), U7.8 (A6)
/DATA7: BC1.A58 (DATA7), U3.9 (D), U5.9 (D), U6.9 (A7), U7.9 (A7)
/DH0: U2.3 (QA), U7.18 (B0)
/DH1: U2.2 (QB), U7.17 (B1)
/DH2: U2.6 (QC), U7.16 (B2)
/DH3: U2.7 (QD), U7.15 (B3)
/DH4: U3.3 (QA), U7.14 (B4)
/DH5: U3.2 (QB), U7.13 (B5)
/DH6: U3.6 (QC), U7.12 (B6)
/DH7: U3.7 (QD), U7.11 (B7)
/DL0: U4.3 (QA), U6.18 (B0)
/DL1: U4.2 (QB), U6.17 (B1)
/DL2: U4.6 (QC), U6.16 (B2)
/DL3: U4.7 (QD), U6.15 (B3)
/DL4: U5.3 (QA), U6.14 (B4)
/DL5: U5.2 (QB), U6.13 (B5)
/DL6: U5.6 (QC), U6.12 (B6)
/DL7: U5.7 (QD), U6.11 (B7)
/LPCH: BC1.A17 (LPCH), U1.9
/LPCL: BC1.A18 (LPCL), U1.4
/PCINC: BC1.B47 (PCINC), U1.12
/PULSE: BC1.B74 (PULSE), Pls1.1, U1.5, U1.10
/Ph: LH1.1, U1.8, U2.11 (~LOAD), U3.11 (~LOAD)
/Pl: LL1.1, U1.6, U4.11 (~LOAD), U5.11 (~LOAD)
/RESET: BC1.A69 (RESET), Rst1.1, U2.14 (CLR), U3.14 (CLR), U4.14 (CLR), U5.14 (CLR)
/~CLK: BC1.B73 (~CLK), U1.13
/~RPCH: BC1.B17 (~RPCH), U7.19 (CE)
/~RPCL: BC1.B18 (~RPCL), U6.19 (CE)
GND: BC1.A12 (GND), BC1.A13 (GND), BC1.A23 (GND), BC1.A32 (GND), BC1.A41 (GND), BC1.A50 (GND), BC1.A59 (GND), BC1.A63 (GND), BC1.A64 (GND), BC1.A65 (GND), BC1.A66 (GND), BC1.A70 (GND), BC1.A71 (GND), BC1.A72 (GND), BC1.A73 (GND), BC1.A74 (GND), BC1.A75 (GND), BC1.A76 (GND), BC1.B12 (GND), BC1.B13 (GND), BC1.B23 (GND), BC1.B32 (GND), BC1.B41 (GND), BC1.B50 (GND), BC1.B59 (GND), BC1.B62 (GND), BC1.B63 (GND), BC1.B64 (GND), BC1.B65 (GND), BC1.B66 (GND), BC1.B67 (GND), BC1.B68 (GND), BC1.B69 (GND), BC1.B70 (GND), BC1.B71 (GND), BC1.B72 (GND), BC1.B75 (GND), BC1.B76 (GND), C1.2, C2.1, C3.1, C4.1, C5.1, C6.1, C7.2, C8.2, U1.7 (GND), U2.8 (GND), U3.8 (GND), U4.8 (GND), U5.8 (GND), U6.1 (A->B), U6.10 (GND), U7.1 (A->B), U7.10 (GND)
unnamed: R1.2, U1.1, U1.2
unnamed: U2.4 (DOWN), U5.13 (~BO)
unnamed: U2.5 (UP), U5.12 (~CO)
unnamed: U2.13 (~BO), U3.4 (DOWN)
unnamed: U2.12 (~CO), U3.5 (UP)
unnamed: U4.13 (~BO), U5.4 (DOWN)
unnamed: U4.12 (~CO), U5.5 (UP)
VCC: BC1.A1 (VCC), BC1.A2 (VCC), BC1.A3 (VCC), BC1.A4 (VCC), BC1.A5 (VCC), BC1.B1 (VCC), BC1.B2 (VCC), BC1.B3 (VCC), BC1.B4 (VCC), BC1.B5 (VCC), C1.1, C2.2, C3.2, C4.2, C5.2, C6.2, C7.1, C8.1, Pwr1.1, R1.1, U1.14 (VCC), U2.16 (VCC), U3.16 (VCC), U4.16 (VCC), U5.16 (VCC), U6.20 (VCC), U7.20 (VCC)

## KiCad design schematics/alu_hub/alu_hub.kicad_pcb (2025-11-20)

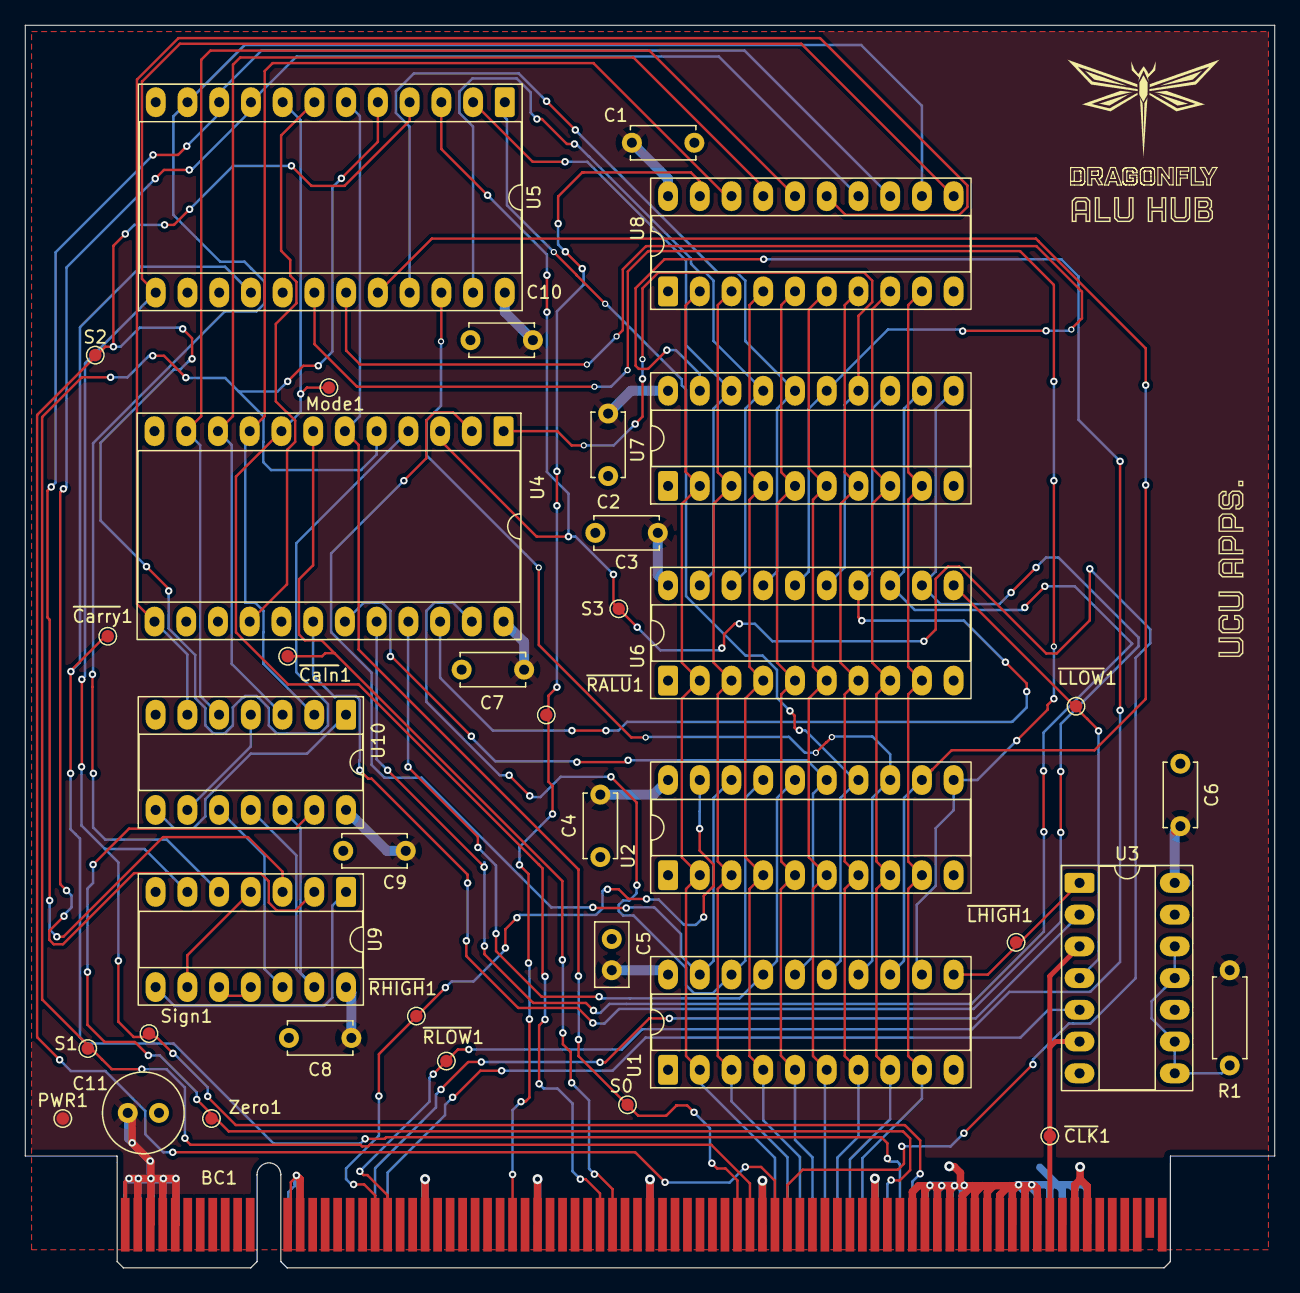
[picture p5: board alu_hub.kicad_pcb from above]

Board: 2 copper layers, 100.0 x 99.4 mm, 33 parts (0 on the bottom side), 59 nets.

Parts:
BC1: BusConnector; BUS_PCIexpress_x16
C1, C2, C3, C4, C6, C7, C8, C9, C10: C; C_Disc_D5.0mm_W2.5mm_P5.00mm
C5: C; C_Disc_D5.0mm_W2.5mm_P2.50mm
C11: C; C_Radial_D6.3mm_H5.0mm_P2.50mm
Mode1: Mode; TestPoint_Pad_D1.0mm
PWR1: Power; TestPoint_Pad_D1.0mm
R1: R; R_Axial_DIN0207_L6.3mm_D2.5mm_P7.62mm_Horizontal
S0: S0; TestPoint_Pad_D1.0mm
S1: S1; TestPoint_Pad_D1.0mm
S2: S2; TestPoint_Pad_D1.0mm
S3: S3; TestPoint_Pad_D1.0mm
Sign1: Sign; TestPoint_Pad_D1.0mm
U1, U6: 74LS574; DIP-20_W7.62mm_Socket_LongPads
U2, U7, U8: 74LS245; DIP-20_W7.62mm_Socket_LongPads
U3, U9, U10: 74LS02; DIP-14_W7.62mm_Socket_LongPads
U4, U5: 74LS181; DIP-24_W15.24mm_Socket_LongPads
Zero1: Zero; TestPoint_Pad_D1.0mm
kibuzzard-691DDF7A: G***; kibuzzard-691DDF7A
kibuzzard-6911C7CA: G***; kibuzzard-6911C7CA

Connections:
/DATA0: BC1.A51 (DATA0), U1.2 (D0), U2.2 (A0), U6.2 (D0), U7.2 (A0), U8.2 (A0)
/DATA1: BC1.A52 (DATA1), U1.3 (D1), U2.3 (A1), U6.3 (D1), U7.3 (A1), U8.3 (A1)
/DATA2: BC1.A53 (DATA2), U1.4 (D2), U2.4 (A2), U6.4 (D2), U7.4 (A2), U8.4 (A2)
/DATA3: BC1.A54 (DATA3), U1.5 (D3), U2.5 (A3), U6.5 (D3), U7.5 (A3), U8.5 (A3)
/DATA4: BC1.A55 (DATA4), U1.6 (D4), U2.6 (A4), U6.6 (D4), U7.6 (A4), U8.6 (A4)
/DATA5: BC1.A56 (DATA5), U1.7 (D5), U2.7 (A5), U6.7 (D5), U7.7 (A5), U8.7 (A5)
/DATA6: BC1.A57 (DATA6), U1.8 (D6), U2.8 (A6), U6.8 (D6), U7.8 (A6), U8.8 (A6)
/DATA7: BC1.A58 (DATA7), U1.9 (D7), U2.9 (A7), U6.9 (D7), U7.9 (A7), U8.9 (A7)
/HIGH0: U1.19 (Q0), U2.18 (B0), U4.2 (A0)
/HIGH1: U1.18 (Q1), U2.17 (B1), U4.23 (A1)
/HIGH2: U1.17 (Q2), U2.16 (B2), U4.21 (A2)
/HIGH3: U1.16 (Q3), U2.15 (B3), U4.19 (A3)
/HIGH4: U1.15 (Q4), U2.14 (B4), U5.1 (B0)
/HIGH5: U1.14 (Q5), U2.13 (B5), U5.22 (B1)
/HIGH6: U1.13 (Q6), U2.12 (B6), U5.20 (B2)
/HIGH7: U1.12 (Q7), U2.11 (B7), U5.18 (B3)
/LOW0: U5.2 (A0), U6.19 (Q0), U7.18 (B0)
/LOW1: U5.23 (A1), U6.18 (Q1), U7.17 (B1)
/LOW2: U5.21 (A2), U6.17 (Q2), U7.16 (B2)
/LOW3: U5.19 (A3), U6.16 (Q3), U7.15 (B3)
/LOW4: U4.1 (B0), U6.15 (Q4), U7.14 (B4)
/LOW5: U4.22 (B1), U6.14 (Q5), U7.13 (B5)
/LOW6: U4.20 (B2), U6.13 (Q6), U7.12 (B6)
/LOW7: U4.18 (B3), U6.12 (Q7), U7.11 (B7)
GND: BC1.A12 (GND), BC1.A13 (GND), BC1.A23 (GND), BC1.A32 (GND), BC1.A41 (GND), BC1.A50 (GND), BC1.A59 (GND), BC1.A63 (GND), BC1.A64 (GND), BC1.A65 (GND), BC1.A66 (GND), BC1.A70 (GND), BC1.A71 (GND), BC1.A72 (GND), BC1.A73 (GND), BC1.A74 (GND), BC1.A75 (GND), BC1.A76 (GND), BC1.B12 (GND), BC1.B13 (GND), BC1.B23 (GND), BC1.B32 (GND), BC1.B41 (GND), BC1.B50 (GND), BC1.B59 (GND), BC1.B62 (GND), BC1.B63 (GND), BC1.B64 (GND), BC1.B65 (GND), BC1.B66 (GND), BC1.B67 (GND), BC1.B68 (GND), BC1.B69 (GND), BC1.B70 (GND), BC1.B71 (GND), BC1.B72 (GND), BC1.B75 (GND), BC1.B76 (GND), C1.1, C2.1, C3.1, C4.1, C5.1, C6.1, C7.1, C8.1, C9.1, C10.1, C11.1, U1.1 (OE), U1.10 (GND), U2.1 (A->B), U2.10 (GND), U3.7 (GND), U4.12 (GND), U5.12 (GND), U6.1 (OE), U6.10 (GND), U7.1 (A->B), U7.10 (GND), U8.1 (A->B), U8.10 (GND), U9.7 (GND), U10.7 (GND)
unnamed: BC1.B37 (ALUM), Mode1.1, U4.8 (M), U5.8 (M)
unnamed: BC1.B48 (ALUS0), S0.1, U4.6 (S0), U5.6 (S0)
unnamed: BC1.B49 (ALUS1), S1.1, U4.5 (S1), U5.5 (S1)
unnamed: BC1.B51 (ALUS2), S2.1, U4.4 (S2), U5.4 (S2)
unnamed: BC1.B52 (ALUS3), S3.1, U4.3 (S3), U5.3 (S3)
unnamed: BC1.A62 (ALUSO), Sign1.1, U5.13 (F3), U8.11 (B7), U9.6
unnamed: BC1.A60 (ALUZO), U10.13, Zero1.1
unnamed: BC1.B38 (~ALUCI), U4.7 (Cn)
unnamed: BC1.A61 (~ALUCO), U5.16 (Cn+4)
unnamed: BC1.B73 (~CLK), U3.3, U3.6
unnamed: BC1.A19 (~LARGH), U3.2
unnamed: BC1.A20 (~LARGL), U3.5
unnamed: BC1.B30 (~RALU), U8.19 (CE)
unnamed: BC1.B19 (~RARGH), U2.19 (CE)
unnamed: BC1.B20 (~RARGL), U7.19 (CE)
unnamed: R1.2, U3.8, U3.9, U3.11, U3.12
unnamed: U1.11 (Cp), U3.1
unnamed: U4.16 (Cn+4), U5.7 (Cn)
unnamed: U4.9 (F0), U8.18 (B0), U10.2
unnamed: U4.10 (F1), U8.17 (B1), U10.3
unnamed: U4.11 (F2), U8.16 (B2), U10.5
unnamed: U4.13 (F3), U8.15 (B3), U10.6
unnamed: U5.9 (F0), U8.14 (B4), U9.2
unnamed: U5.10 (F1), U8.13 (B5), U9.3
unnamed: U5.11 (F2), U8.12 (B6), U9.5
unnamed: U3.4, U6.11 (Cp)
unnamed: U9.1, U9.8
unnamed: U9.4, U9.9
unnamed: U9.10, U9.11
unnamed: U10.1, U10.8
unnamed: U10.4, U10.9
unnamed: U9.12, U10.10
unnamed: U9.13, U10.11, U10.12
VCC: BC1.A1 (VCC), BC1.A2 (VCC), BC1.A3 (VCC), BC1.A4 (VCC), BC1.A5 (VCC), BC1.B1 (VCC), BC1.B2 (VCC), BC1.B3 (VCC), BC1.B4 (VCC), BC1.B5 (VCC), C1.2, C2.2, C3.2, C4.2, C5.2, C6.2, C7.2, C8.2, C9.2, C10.2, C11.2, PWR1.1, R1.1, U1.20 (VCC), U2.20 (VCC), U3.14 (VCC), U4.24 (VCC), U5.24 (VCC), U6.20 (VCC), U7.20 (VCC), U8.20 (VCC), U9.14 (VCC), U10.14 (VCC)

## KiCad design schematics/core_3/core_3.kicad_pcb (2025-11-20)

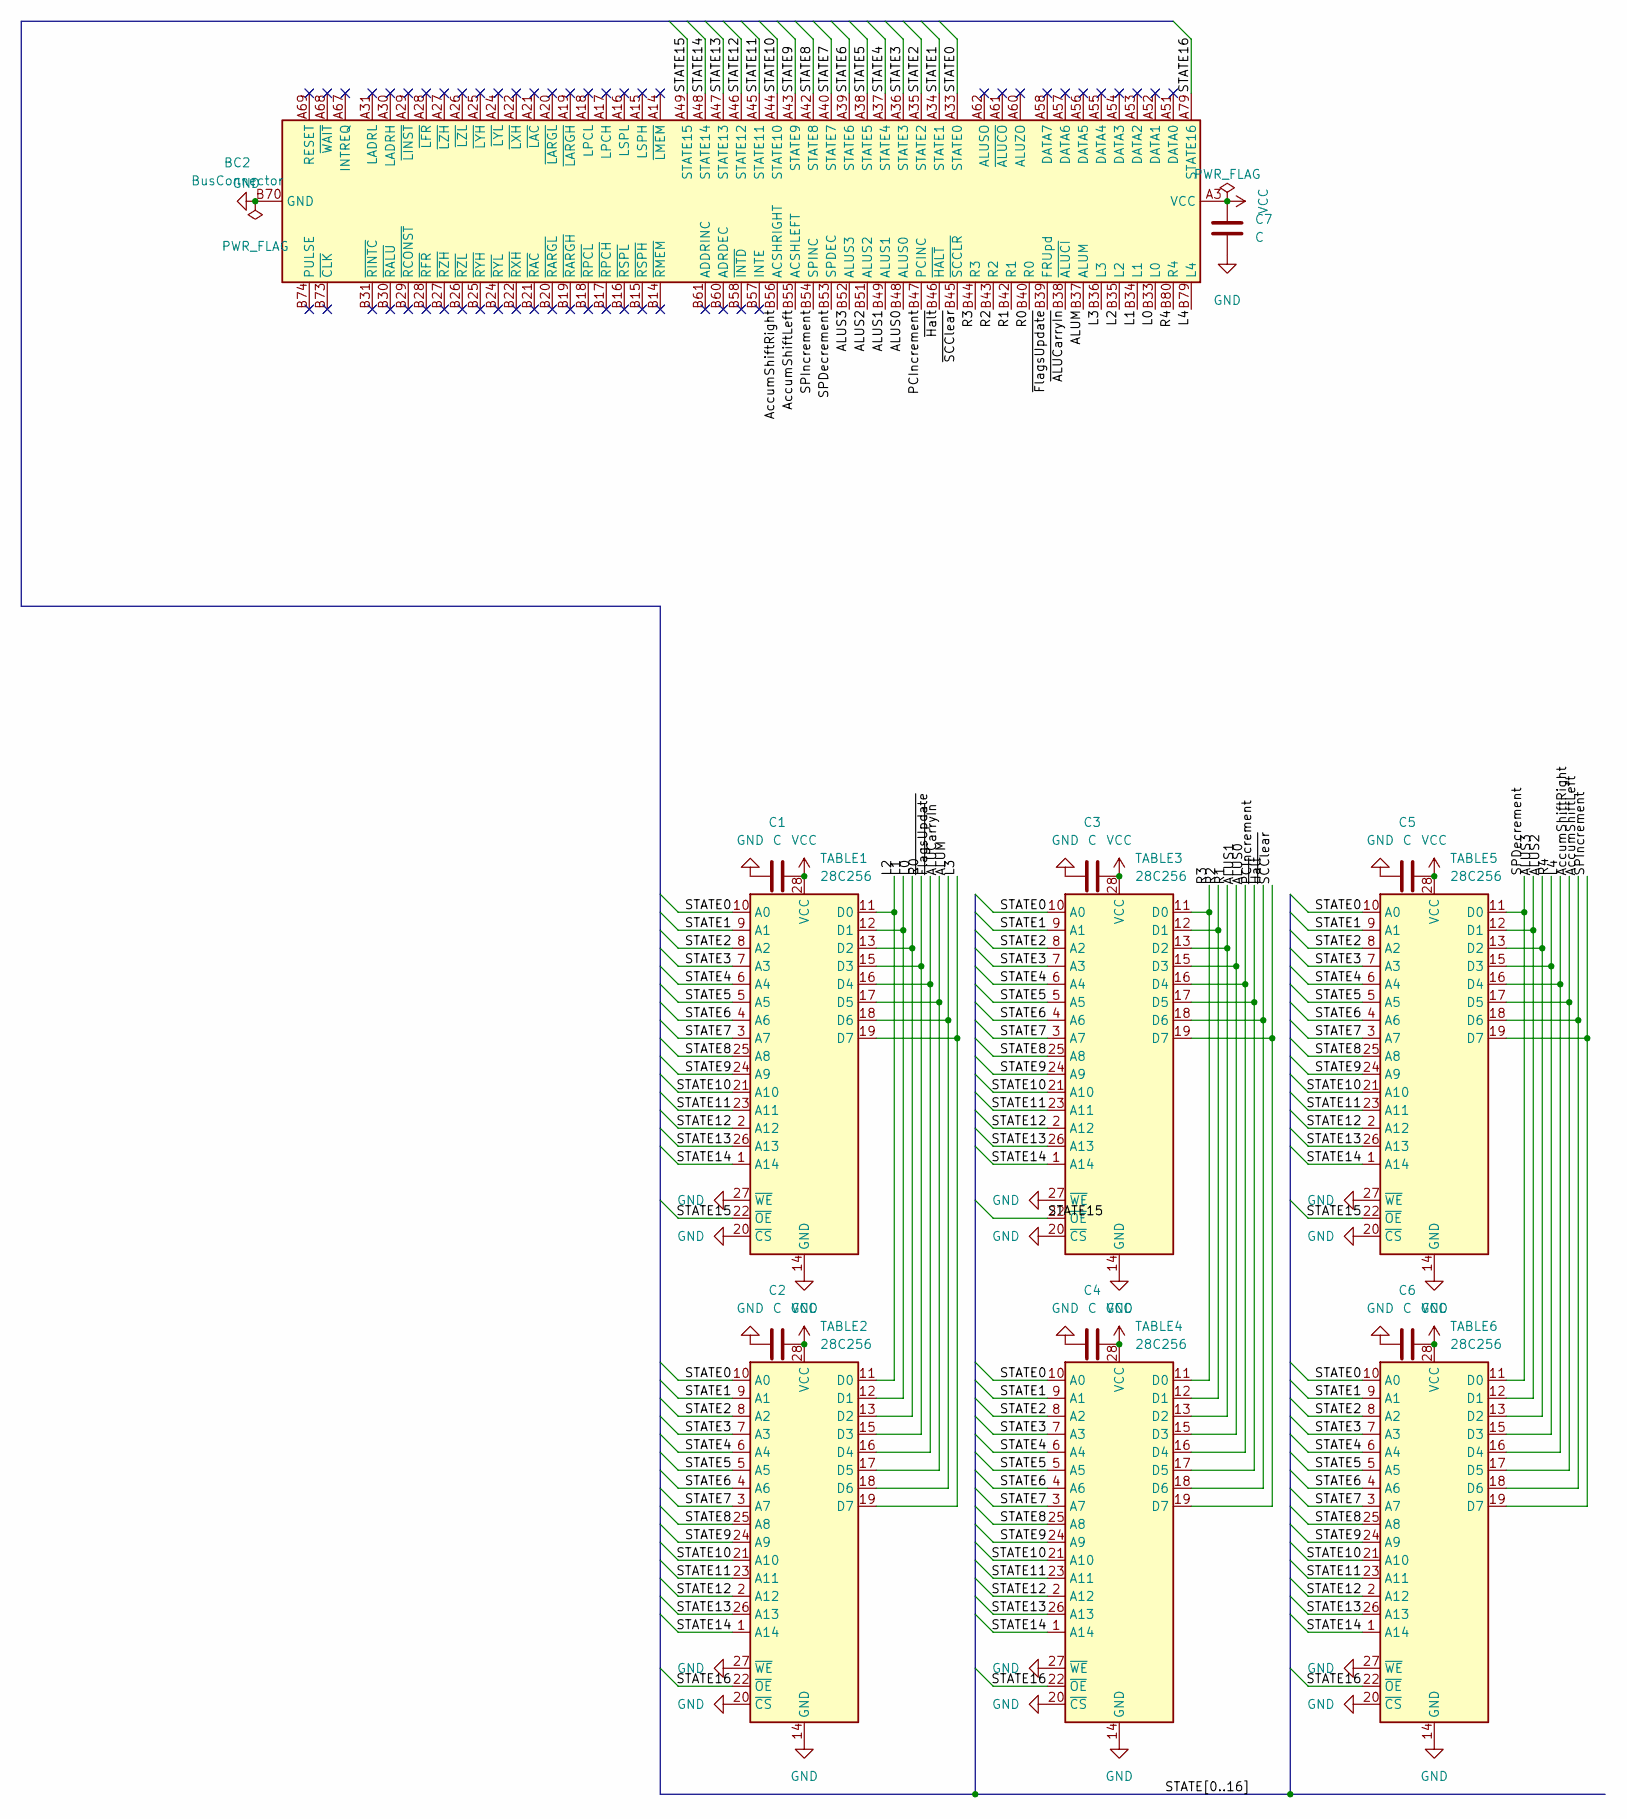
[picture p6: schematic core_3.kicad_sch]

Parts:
BC2: BusConnector; BUS_PCIexpress_x16
C1, C2, C3, C4, C5, C6: C; C_Disc_D5.0mm_W2.5mm_P2.50mm
C7: C; C_Radial_D6.3mm_H5.0mm_P2.50mm
TABLE1, TABLE2, TABLE3, TABLE4, TABLE5, TABLE6: 28C256; DIP-28_W15.24mm_Socket_LongPads

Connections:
/ALUM: BC2.B37 (ALUM), TABLE1.18 (D6), TABLE2.18 (D6)
/ALUS0: BC2.B48 (ALUS0), TABLE3.16 (D4), TABLE4.16 (D4)
/ALUS1: BC2.B49 (ALUS1), TABLE3.15 (D3), TABLE4.15 (D3)
/ALUS2: BC2.B51 (ALUS2), TABLE5.13 (D2), TABLE6.13 (D2)
/ALUS3: BC2.B52 (ALUS3), TABLE5.12 (D1), TABLE6.12 (D1)
/AccumShiftLeft: BC2.B55 (ACSHLEFT), TABLE5.18 (D6), TABLE6.18 (D6)
/AccumShiftRight: BC2.B56 (ACSHRIGHT), TABLE5.17 (D5), TABLE6.17 (D5)
/L0: BC2.B33 (L0), TABLE1.13 (D2), TABLE2.13 (D2)
/L1: BC2.B34 (L1), TABLE1.12 (D1), TABLE2.12 (D1)
/L2: BC2.B35 (L2), TABLE1.11 (D0), TABLE2.11 (D0)
/L3: BC2.B36 (L3), TABLE1.19 (D7), TABLE2.19 (D7)
/L4: BC2.B79 (L4), TABLE5.16 (D4), TABLE6.16 (D4)
/PCIncrement: BC2.B47 (PCINC), TABLE3.17 (D5), TABLE4.17 (D5)
/R0: BC2.B40 (R0), TABLE1.15 (D3), TABLE2.15 (D3)
/R1: BC2.B42 (R1), TABLE3.13 (D2), TABLE4.13 (D2)
/R2: BC2.B43 (R2), TABLE3.12 (D1), TABLE4.12 (D1)
/R3: BC2.B44 (R3), TABLE3.11 (D0), TABLE4.11 (D0)
/R4: BC2.B80 (R4), TABLE5.15 (D3), TABLE6.15 (D3)
/SPDecrement: BC2.B53 (SPDEC), TABLE5.11 (D0), TABLE6.11 (D0)
/SPIncrement: BC2.B54 (SPINC), TABLE5.19 (D7), TABLE6.19 (D7)
/STATE0: BC2.A33 (STATE0), TABLE1.10 (A0), TABLE2.10 (A0), TABLE3.10 (A0), TABLE4.10 (A0), TABLE5.10 (A0), TABLE6.10 (A0)
/STATE1: BC2.A34 (STATE1), TABLE1.9 (A1), TABLE2.9 (A1), TABLE3.9 (A1), TABLE4.9 (A1), TABLE5.9 (A1), TABLE6.9 (A1)
/STATE2: BC2.A35 (STATE2), TABLE1.8 (A2), TABLE2.8 (A2), TABLE3.8 (A2), TABLE4.8 (A2), TABLE5.8 (A2), TABLE6.8 (A2)
/STATE3: BC2.A36 (STATE3), TABLE1.7 (A3), TABLE2.7 (A3), TABLE3.7 (A3), TABLE4.7 (A3), TABLE5.7 (A3), TABLE6.7 (A3)
/STATE4: BC2.A37 (STATE4), TABLE1.6 (A4), TABLE2.6 (A4), TABLE3.6 (A4), TABLE4.6 (A4), TABLE5.6 (A4), TABLE6.6 (A4)
/STATE5: BC2.A38 (STATE5), TABLE1.5 (A5), TABLE2.5 (A5), TABLE3.5 (A5), TABLE4.5 (A5), TABLE5.5 (A5), TABLE6.5 (A5)
/STATE6: BC2.A39 (STATE6), TABLE1.4 (A6), TABLE2.4 (A6), TABLE3.4 (A6), TABLE4.4 (A6), TABLE5.4 (A6), TABLE6.4 (A6)
/STATE7: BC2.A40 (STATE7), TABLE1.3 (A7), TABLE2.3 (A7), TABLE3.3 (A7), TABLE4.3 (A7), TABLE5.3 (A7), TABLE6.3 (A7)
/STATE8: BC2.A42 (STATE8), TABLE1.25 (A8), TABLE2.25 (A8), TABLE3.25 (A8), TABLE4.25 (A8), TABLE5.25 (A8), TABLE6.25 (A8)
/STATE9: BC2.A43 (STATE9), TABLE1.24 (A9), TABLE2.24 (A9), TABLE3.24 (A9), TABLE4.24 (A9), TABLE5.24 (A9), TABLE6.24 (A9)
/STATE10: BC2.A44 (STATE10), TABLE1.21 (A10), TABLE2.21 (A10), TABLE3.21 (A10), TABLE4.21 (A10), TABLE5.21 (A10), TABLE6.21 (A10)
/STATE11: BC2.A45 (STATE11), TABLE1.23 (A11), TABLE2.23 (A11), TABLE3.23 (A11), TABLE4.23 (A11), TABLE5.23 (A11), TABLE6.23 (A11)
/STATE12: BC2.A46 (STATE12), TABLE1.2 (A12), TABLE2.2 (A12), TABLE3.2 (A12), TABLE4.2 (A12), TABLE5.2 (A12), TABLE6.2 (A12)
/STATE13: BC2.A47 (STATE13), TABLE1.26 (A13), TABLE2.26 (A13), TABLE3.26 (A13), TABLE4.26 (A13), TABLE5.26 (A13), TABLE6.26 (A13)
/STATE14: BC2.A48 (STATE14), TABLE1.1 (A14), TABLE2.1 (A14), TABLE3.1 (A14), TABLE4.1 (A14), TABLE5.1 (A14), TABLE6.1 (A14)
/STATE15: BC2.A49 (STATE15), TABLE1.22 (~OE), TABLE3.22 (~OE), TABLE5.22 (~OE)
/STATE16: BC2.A79 (STATE16), TABLE2.22 (~OE), TABLE4.22 (~OE), TABLE6.22 (~OE)
/~ALUCarryIn: BC2.B38 (~ALUCI), TABLE1.17 (D5), TABLE2.17 (D5)
/~FlagsUpdate: BC2.B39 (FRUpd), TABLE1.16 (D4), TABLE2.16 (D4)
/~Halt: BC2.B46 (~HALT), TABLE3.18 (D6), TABLE4.18 (D6)
/~SCClear: BC2.B45 (~SCCLR), TABLE3.19 (D7), TABLE4.19 (D7)
GND: BC2.A12 (GND), BC2.A13 (GND), BC2.A23 (GND), BC2.A32 (GND), BC2.A50 (GND), BC2.A59 (GND), BC2.A63 (GND), BC2.A64 (GND), BC2.A65 (GND), BC2.A66 (GND), BC2.A70 (GND), BC2.A71 (GND), BC2.A72 (GND), BC2.A73 (GND), BC2.A74 (GND), BC2.A75 (GND), BC2.A76 (GND), BC2.B12 (GND), BC2.B13 (GND), BC2.B23 (GND), BC2.B32 (GND), BC2.B50 (GND), BC2.B59 (GND), BC2.B62 (GND), BC2.B63 (GND), BC2.B64 (GND), BC2.B65 (GND), BC2.B66 (GND), BC2.B67 (GND), BC2.B68 (GND), BC2.B69 (GND), BC2.B70 (GND), BC2.B71 (GND), BC2.B72 (GND), BC2.B75 (GND), BC2.B76 (GND), C1.2, C2.2, C3.2, C4.2, C5.2, C6.2, C7.2, TABLE1.14 (GND), TABLE1.20 (~CS), TABLE1.27 (~WE), TABLE2.14 (GND), TABLE2.20 (~CS), TABLE2.27 (~WE), TABLE3.14 (GND), TABLE3.20 (~CS), TABLE3.27 (~WE), TABLE4.14 (GND), TABLE4.20 (~CS), TABLE4.27 (~WE), TABLE5.14 (GND), TABLE5.20 (~CS), TABLE5.27 (~WE), TABLE6.14 (GND), TABLE6.20 (~CS), TABLE6.27 (~WE)
VCC: BC2.A1 (VCC), BC2.A2 (VCC), BC2.A3 (VCC), BC2.A4 (VCC), BC2.A5 (VCC), BC2.B1 (VCC), BC2.B2 (VCC), BC2.B3 (VCC), BC2.B4 (VCC), BC2.B5 (VCC), C1.1, C2.1, C3.1, C4.1, C5.1, C6.1, C7.1, TABLE1.28 (VCC), TABLE2.28 (VCC), TABLE3.28 (VCC), TABLE4.28 (VCC), TABLE5.28 (VCC), TABLE6.28 (VCC)

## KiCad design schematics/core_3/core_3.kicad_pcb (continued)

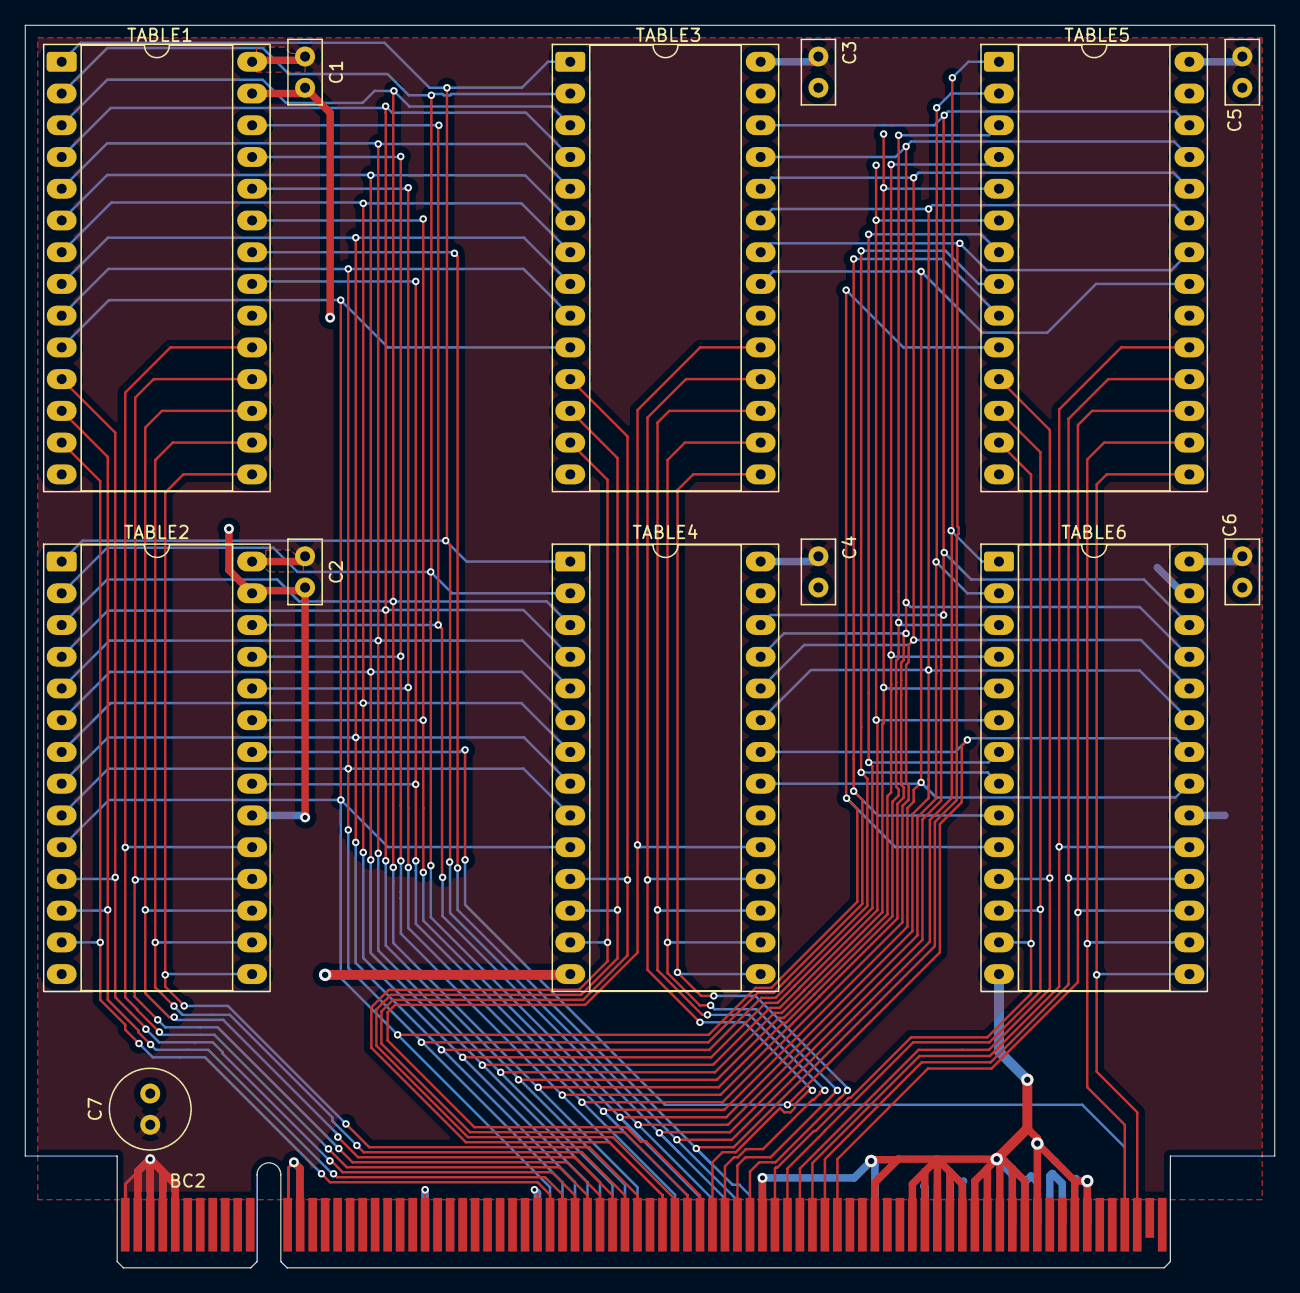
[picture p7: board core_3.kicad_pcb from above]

Board: 2 copper layers, 100.0 x 99.4 mm, 14 parts (0 on the bottom side), 43 nets.

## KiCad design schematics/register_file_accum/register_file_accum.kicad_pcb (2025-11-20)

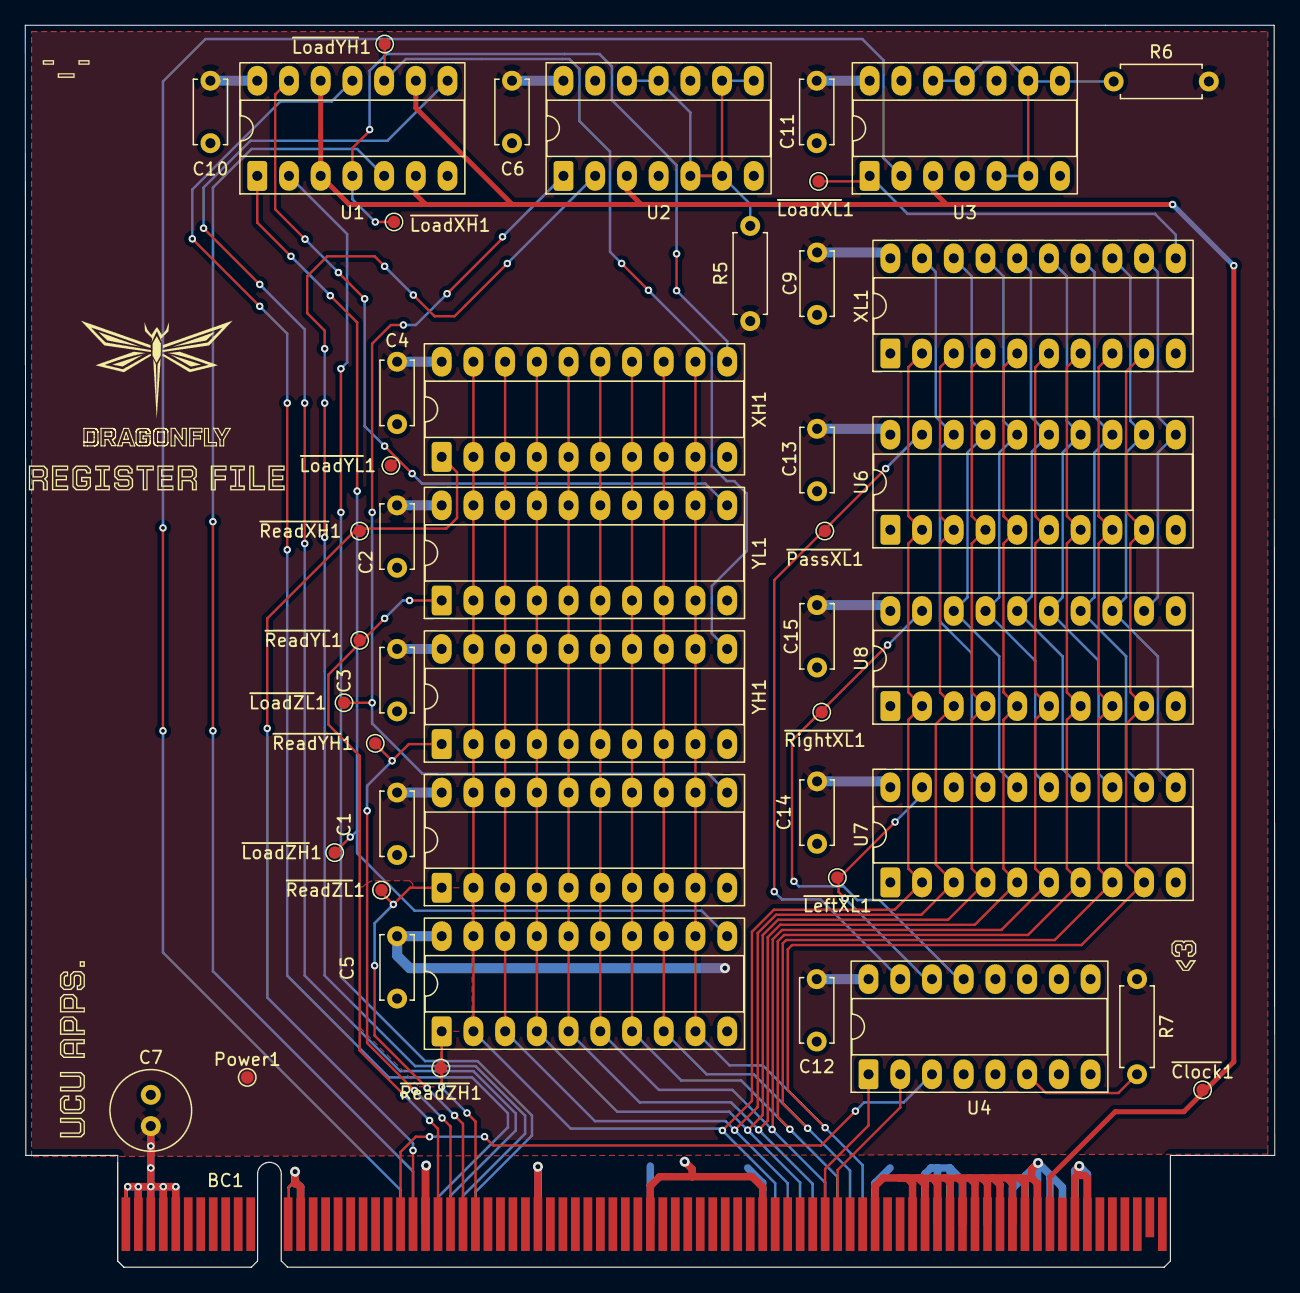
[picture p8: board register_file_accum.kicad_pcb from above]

Board: 2 copper layers, 100.1 x 99.4 mm, 36 parts (0 on the bottom side), 45 nets.

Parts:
BC1: BusConnector; BUS_PCIexpress_x16
C1, C2, C3, C4, C5, C6, C9, C10, C11, C12, C13, C14, C15: C; C_Disc_D5.0mm_W2.5mm_P5.00mm
C7: C; C_Radial_D6.3mm_H5.0mm_P2.50mm
Power1: Power; TestPoint_Pad_D1.0mm
R5, R6, R7: R; R_Axial_DIN0207_L6.3mm_D2.5mm_P7.62mm_Horizontal
U1, U2, U3: 74LS02; DIP-14_W7.62mm_Socket_LongPads
U4: 74LS138; DIP-16_W7.62mm_Socket_LongPads
U6, U7, U8: 74LS245; DIP-20_W7.62mm_Socket_LongPads
XH1: 74LS574; DIP-20_W7.62mm_Socket_LongPads
XL1: 74LS574; DIP-20_W7.62mm_Socket_LongPads
YH1: 74LS574; DIP-20_W7.62mm_Socket_LongPads
YL1: 74LS574; DIP-20_W7.62mm_Socket_LongPads
ZH1: 74LS574; DIP-20_W7.62mm_Socket_LongPads
ZL1: 74LS574; DIP-20_W7.62mm_Socket_LongPads
kibuzzard-691DE1A7: G***; kibuzzard-691DE1A7
kibuzzard-691DE1B7: G***; kibuzzard-691DE1B7
kibuzzard-691DE19C: G***; kibuzzard-691DE19C
kibuzzard-6911B41A: G***; kibuzzard-6911B41A

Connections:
/ACCUM0: U6.18 (B0), U7.17 (B1), XL1.19 (Q0)
/ACCUM1: U6.17 (B1), U7.16 (B2), U8.18 (B0), XL1.18 (Q1)
/ACCUM2: U6.16 (B2), U7.15 (B3), U8.17 (B1), XL1.17 (Q2)
/ACCUM3: U6.15 (B3), U7.14 (B4), U8.16 (B2), XL1.16 (Q3)
/ACCUM4: U6.14 (B4), U7.13 (B5), U8.15 (B3), XL1.15 (Q4)
/ACCUM5: U6.13 (B5), U7.12 (B6), U8.14 (B4), XL1.14 (Q5)
/ACCUM6: U6.12 (B6), U7.11 (B7), U8.13 (B5), XL1.13 (Q6)
/ACCUM7: U6.11 (B7), U8.12 (B6), XL1.12 (Q7)
/ACSHLEFT: U4.14 (O1), U7.19 (CE)
/ACSHRIGHT: U4.13 (O2), U8.19 (CE)
/DATA0: BC1.A51 (DATA0), U6.2 (A0), U7.2 (A0), U8.2 (A0), XH1.2 (D0), XH1.19 (Q0), XL1.2 (D0), YH1.2 (D0), YH1.19 (Q0), YL1.2 (D0), YL1.19 (Q0), ZH1.2 (D0), ZH1.19 (Q0), ZL1.2 (D0), ZL1.19 (Q0)
/DATA1: BC1.A52 (DATA1), U6.3 (A1), U7.3 (A1), U8.3 (A1), XH1.3 (D1), XH1.18 (Q1), XL1.3 (D1), YH1.3 (D1), YH1.18 (Q1), YL1.3 (D1), YL1.18 (Q1), ZH1.3 (D1), ZH1.18 (Q1), ZL1.3 (D1), ZL1.18 (Q1)
/DATA2: BC1.A53 (DATA2), U6.4 (A2), U7.4 (A2), U8.4 (A2), XH1.4 (D2), XH1.17 (Q2), XL1.4 (D2), YH1.4 (D2), YH1.17 (Q2), YL1.4 (D2), YL1.17 (Q2), ZH1.4 (D2), ZH1.17 (Q2), ZL1.4 (D2), ZL1.17 (Q2)
/DATA3: BC1.A54 (DATA3), U6.5 (A3), U7.5 (A3), U8.5 (A3), XH1.5 (D3), XH1.16 (Q3), XL1.5 (D3), YH1.5 (D3), YH1.16 (Q3), YL1.5 (D3), YL1.16 (Q3), ZH1.5 (D3), ZH1.16 (Q3), ZL1.5 (D3), ZL1.16 (Q3)
/DATA4: BC1.A55 (DATA4), U6.6 (A4), U7.6 (A4), U8.6 (A4), XH1.6 (D4), XH1.15 (Q4), XL1.6 (D4), YH1.6 (D4), YH1.15 (Q4), YL1.6 (D4), YL1.15 (Q4), ZH1.6 (D4), ZH1.15 (Q4), ZL1.6 (D4), ZL1.15 (Q4)
/DATA5: BC1.A56 (DATA5), U6.7 (A5), U7.7 (A5), U8.7 (A5), XH1.7 (D5), XH1.14 (Q5), XL1.7 (D5), YH1.7 (D5), YH1.14 (Q5), YL1.7 (D5), YL1.14 (Q5), ZH1.7 (D5), ZH1.14 (Q5), ZL1.7 (D5), ZL1.14 (Q5)
/DATA6: BC1.A57 (DATA6), U6.8 (A6), U7.8 (A6), U8.8 (A6), XH1.8 (D6), XH1.13 (Q6), XL1.8 (D6), YH1.8 (D6), YH1.13 (Q6), YL1.8 (D6), YL1.13 (Q6), ZH1.8 (D6), ZH1.13 (Q6), ZL1.8 (D6), ZL1.13 (Q6)
/DATA7: BC1.A58 (DATA7), U6.9 (A7), U7.9 (A7), U8.9 (A7), XH1.9 (D7), XH1.12 (Q7), XL1.9 (D7), YH1.9 (D7), YH1.12 (Q7), YL1.9 (D7), YL1.12 (Q7), ZH1.9 (D7), ZH1.12 (Q7), ZL1.9 (D7), ZL1.12 (Q7)
/LAC: BC1.A21 (~LAC), U3.2
/SHL: BC1.B55 (ACSHLEFT), U4.1 (A0)
/SHR: BC1.B56 (ACSHRIGHT), U4.2 (A1)
/~CLK: BC1.B73 (~CLK), U1.3, U1.6, U1.9, U1.12, U2.3, U3.3
/~PASS: BC1.B21 (~RAC), U4.3 (A2)
/~RAC: U4.15 (O0), U6.19 (CE)
GND: BC1.A12 (GND), BC1.A13 (GND), BC1.A23 (GND), BC1.A32 (GND), BC1.A41 (GND), BC1.A50 (GND), BC1.A59 (GND), BC1.A63 (GND), BC1.A64 (GND), BC1.A65 (GND), BC1.A66 (GND), BC1.A70 (GND), BC1.A71 (GND), BC1.A72 (GND), BC1.A73 (GND), BC1.A74 (GND), BC1.A75 (GND), BC1.A76 (GND), BC1.B12 (GND), BC1.B13 (GND), BC1.B23 (GND), BC1.B32 (GND), BC1.B41 (GND), BC1.B50 (GND), BC1.B59 (GND), BC1.B62 (GND), BC1.B63 (GND), BC1.B64 (GND), BC1.B65 (GND), BC1.B66 (GND), BC1.B67 (GND), BC1.B68 (GND), BC1.B69 (GND), BC1.B70 (GND), BC1.B71 (GND), BC1.B72 (GND), BC1.B75 (GND), BC1.B76 (GND), C1.1, C2.1, C3.1, C4.1, C5.1, C6.2, C7.2, C9.2, C10.2, C11.2, C12.2, C13.2, C14.2, C15.2, U1.7 (GND), U2.7 (GND), U3.7 (GND), U4.4 (E1), U4.5 (E2), U4.8 (GND), U6.1 (A->B), U6.10 (GND), U7.1 (A->B), U7.10 (GND), U7.18 (B0), U8.1 (A->B), U8.10 (GND), U8.11 (B7), XH1.10 (GND), XL1.1 (OE), XL1.10 (GND), YH1.10 (GND), YL1.10 (GND), ZH1.10 (GND), ZL1.10 (GND)
unnamed: BC1.A22 (~LXH), U1.5
unnamed: BC1.A25 (~LYH), U1.8
unnamed: BC1.A24 (~LYL), U1.11
unnamed: BC1.A27 (~LZH), U1.2
unnamed: BC1.A26 (~LZL), U2.2
unnamed: BC1.B22 (~RXH), XH1.1 (OE)
unnamed: BC1.B25 (~RYH), YH1.1 (OE)
unnamed: BC1.B24 (~RYL), YL1.1 (OE)
unnamed: BC1.B27 (~RZH), ZH1.1 (OE)
unnamed: BC1.B26 (~RZL), ZL1.1 (OE)
unnamed: R5.2, U2.5, U2.6, U2.8, U2.9, U2.11, U2.12
unnamed: R6.1, U3.5, U3.6, U3.8, U3.9, U3.11, U3.12
unnamed: R7.2, U4.6 (E3)
unnamed: U1.4, XH1.11 (Cp)
unnamed: U3.1, XL1.11 (Cp)
unnamed: U1.10, YH1.11 (Cp)
unnamed: U1.13, YL1.11 (Cp)
unnamed: U1.1, ZH1.11 (Cp)
unnamed: U2.1, ZL1.11 (Cp)
VCC: BC1.A1 (VCC), BC1.A2 (VCC), BC1.A3 (VCC), BC1.A4 (VCC), BC1.A5 (VCC), BC1.B1 (VCC), BC1.B2 (VCC), BC1.B3 (VCC), BC1.B4 (VCC), BC1.B5 (VCC), C1.2, C2.2, C3.2, C4.2, C5.2, C6.1, C7.1, C9.1, C10.1, C11.1, C12.1, C13.1, C14.1, C15.1, Power1.1, R5.1, R6.2, R7.1, U1.14 (VCC), U2.14 (VCC), U3.14 (VCC), U4.16 (VCC), U6.20 (VCC), U7.20 (VCC), U8.20 (VCC), XH1.20 (VCC), XL1.20 (VCC), YH1.20 (VCC), YL1.20 (VCC), ZH1.20 (VCC), ZL1.20 (VCC)

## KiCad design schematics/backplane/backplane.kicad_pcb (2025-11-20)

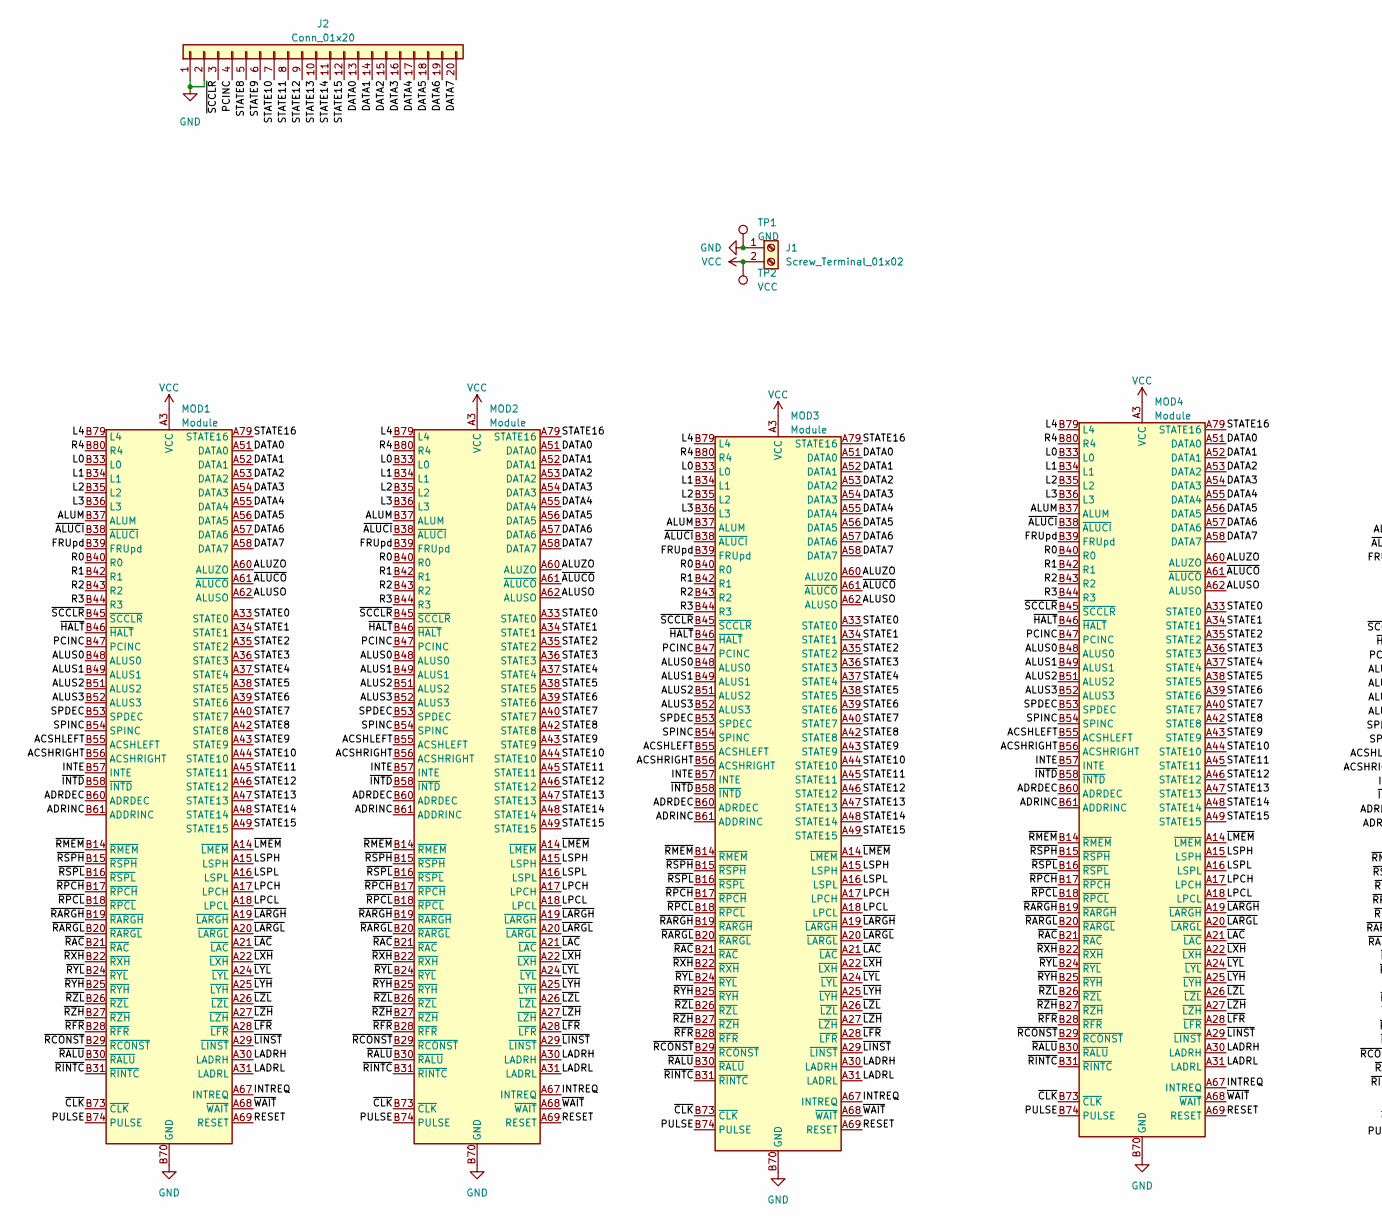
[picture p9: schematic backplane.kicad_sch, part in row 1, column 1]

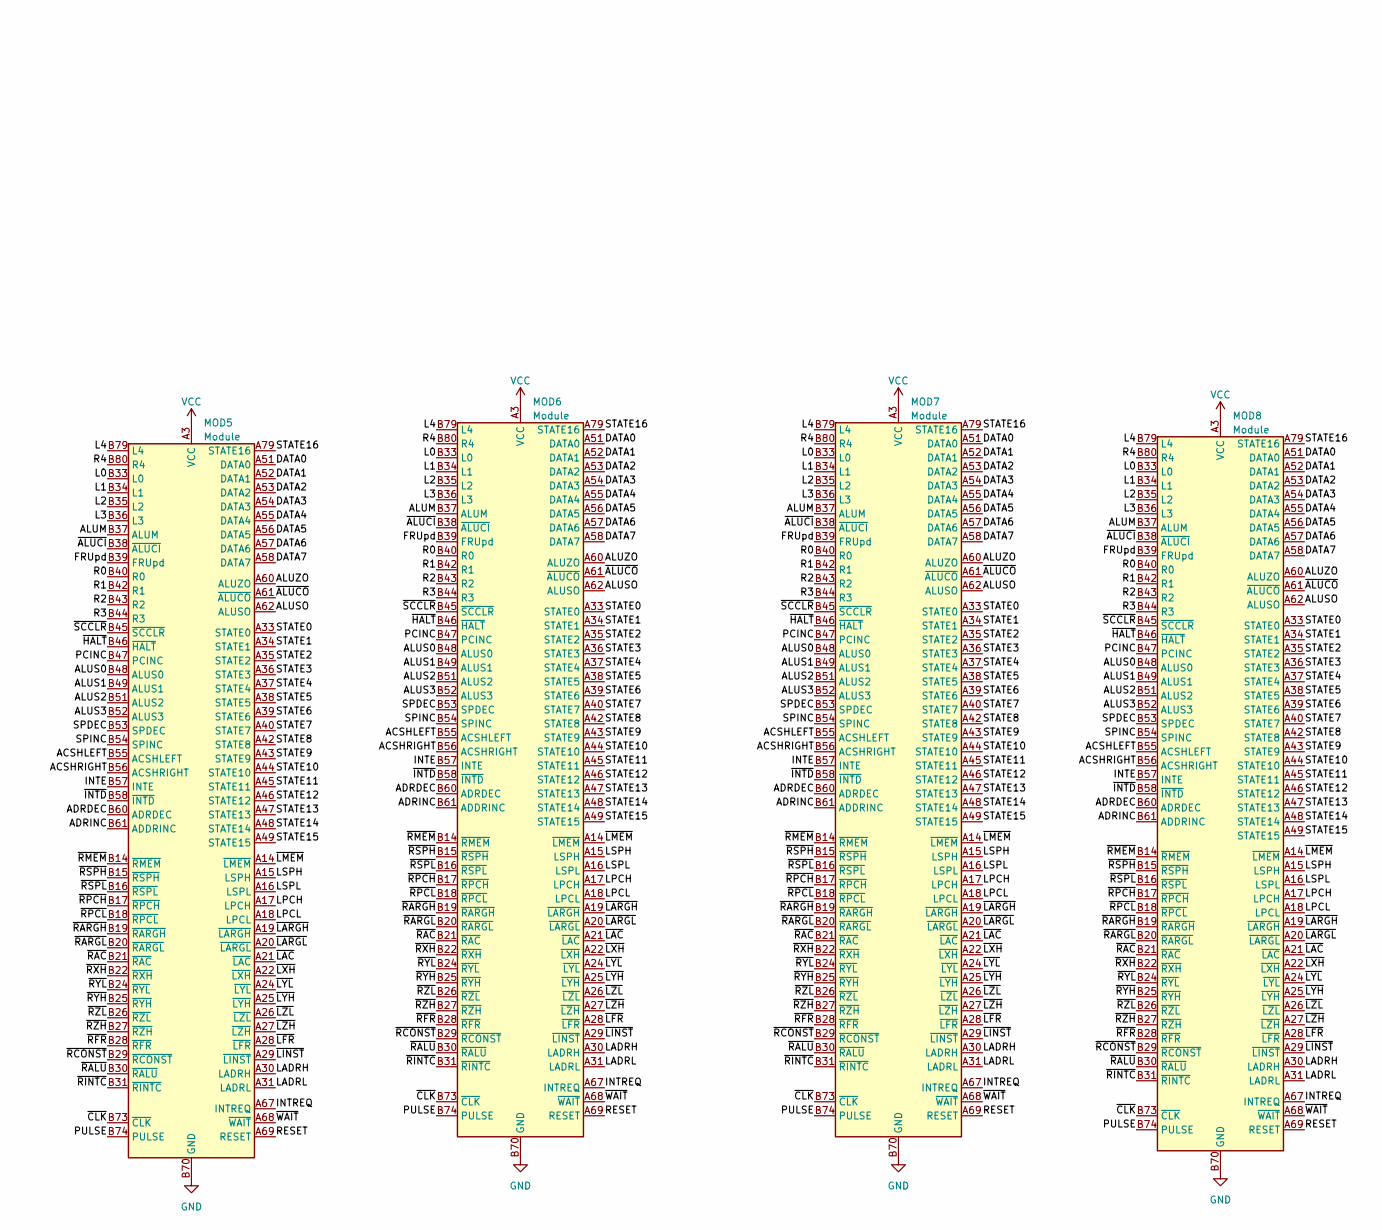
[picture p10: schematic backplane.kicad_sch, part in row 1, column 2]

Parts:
J1: Screw_Terminal_01x02; SHDR2W100P0X500_1X2_1000X780X1020P
J2: Conn_01x20; PinSocket_1x20_P2.54mm_Vertical
MOD1, MOD2, MOD3, MOD4, MOD5, MOD6, MOD7, MOD8: Module; BusSlot
TP1: GND; TestPoint_Pad_D1.5mm
TP2: VCC; TestPoint_Pad_D1.5mm

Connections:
/ACSHLEFT: MOD1.B55 (ACSHLEFT), MOD2.B55 (ACSHLEFT), MOD3.B55 (ACSHLEFT), MOD4.B55 (ACSHLEFT), MOD5.B55 (ACSHLEFT), MOD6.B55 (ACSHLEFT), MOD7.B55 (ACSHLEFT), MOD8.B55 (ACSHLEFT)
/ACSHRIGHT: MOD1.B56 (ACSHRIGHT), MOD2.B56 (ACSHRIGHT), MOD3.B56 (ACSHRIGHT), MOD4.B56 (ACSHRIGHT), MOD5.B56 (ACSHRIGHT), MOD6.B56 (ACSHRIGHT), MOD7.B56 (ACSHRIGHT), MOD8.B56 (ACSHRIGHT)
/ADRDEC: MOD1.B60 (ADRDEC), MOD2.B60 (ADRDEC), MOD3.B60 (ADRDEC), MOD4.B60 (ADRDEC), MOD5.B60 (ADRDEC), MOD6.B60 (ADRDEC), MOD7.B60 (ADRDEC), MOD8.B60 (ADRDEC)
/ADRINC: MOD1.B61 (ADDRINC), MOD2.B61 (ADDRINC), MOD3.B61 (ADDRINC), MOD4.B61 (ADDRINC), MOD5.B61 (ADDRINC), MOD6.B61 (ADDRINC), MOD7.B61 (ADDRINC), MOD8.B61 (ADDRINC)
/ALUM: MOD1.B37 (ALUM), MOD2.B37 (ALUM), MOD3.B37 (ALUM), MOD4.B37 (ALUM), MOD5.B37 (ALUM), MOD6.B37 (ALUM), MOD7.B37 (ALUM), MOD8.B37 (ALUM)
/ALUS0: MOD1.B48 (ALUS0), MOD2.B48 (ALUS0), MOD3.B48 (ALUS0), MOD4.B48 (ALUS0), MOD5.B48 (ALUS0), MOD6.B48 (ALUS0), MOD7.B48 (ALUS0), MOD8.B48 (ALUS0)
/ALUS1: MOD1.B49 (ALUS1), MOD2.B49 (ALUS1), MOD3.B49 (ALUS1), MOD4.B49 (ALUS1), MOD5.B49 (ALUS1), MOD6.B49 (ALUS1), MOD7.B49 (ALUS1), MOD8.B49 (ALUS1)
/ALUS2: MOD1.B51 (ALUS2), MOD2.B51 (ALUS2), MOD3.B51 (ALUS2), MOD4.B51 (ALUS2), MOD5.B51 (ALUS2), MOD6.B51 (ALUS2), MOD7.B51 (ALUS2), MOD8.B51 (ALUS2)
/ALUS3: MOD1.B52 (ALUS3), MOD2.B52 (ALUS3), MOD3.B52 (ALUS3), MOD4.B52 (ALUS3), MOD5.B52 (ALUS3), MOD6.B52 (ALUS3), MOD7.B52 (ALUS3), MOD8.B52 (ALUS3)
/ALUSO: MOD1.A62 (ALUSO), MOD2.A62 (ALUSO), MOD3.A62 (ALUSO), MOD4.A62 (ALUSO), MOD5.A62 (ALUSO), MOD6.A62 (ALUSO), MOD7.A62 (ALUSO), MOD8.A62 (ALUSO)
/ALUZO: MOD1.A60 (ALUZO), MOD2.A60 (ALUZO), MOD3.A60 (ALUZO), MOD4.A60 (ALUZO), MOD5.A60 (ALUZO), MOD6.A60 (ALUZO), MOD7.A60 (ALUZO), MOD8.A60 (ALUZO)
/DATA0: J2.13, MOD1.A51 (DATA0), MOD2.A51 (DATA0), MOD3.A51 (DATA0), MOD4.A51 (DATA0), MOD5.A51 (DATA0), MOD6.A51 (DATA0), MOD7.A51 (DATA0), MOD8.A51 (DATA0)
/DATA1: J2.14, MOD1.A52 (DATA1), MOD2.A52 (DATA1), MOD3.A52 (DATA1), MOD4.A52 (DATA1), MOD5.A52 (DATA1), MOD6.A52 (DATA1), MOD7.A52 (DATA1), MOD8.A52 (DATA1)
/DATA2: J2.15, MOD1.A53 (DATA2), MOD2.A53 (DATA2), MOD3.A53 (DATA2), MOD4.A53 (DATA2), MOD5.A53 (DATA2), MOD6.A53 (DATA2), MOD7.A53 (DATA2), MOD8.A53 (DATA2)
/DATA3: J2.16, MOD1.A54 (DATA3), MOD2.A54 (DATA3), MOD3.A54 (DATA3), MOD4.A54 (DATA3), MOD5.A54 (DATA3), MOD6.A54 (DATA3), MOD7.A54 (DATA3), MOD8.A54 (DATA3)
/DATA4: J2.17, MOD1.A55 (DATA4), MOD2.A55 (DATA4), MOD3.A55 (DATA4), MOD4.A55 (DATA4), MOD5.A55 (DATA4), MOD6.A55 (DATA4), MOD7.A55 (DATA4), MOD8.A55 (DATA4)
/DATA5: J2.18, MOD1.A56 (DATA5), MOD2.A56 (DATA5), MOD3.A56 (DATA5), MOD4.A56 (DATA5), MOD5.A56 (DATA5), MOD6.A56 (DATA5), MOD7.A56 (DATA5), MOD8.A56 (DATA5)
/DATA6: J2.19, MOD1.A57 (DATA6), MOD2.A57 (DATA6), MOD3.A57 (DATA6), MOD4.A57 (DATA6), MOD5.A57 (DATA6), MOD6.A57 (DATA6), MOD7.A57 (DATA6), MOD8.A57 (DATA6)
/DATA7: J2.20, MOD1.A58 (DATA7), MOD2.A58 (DATA7), MOD3.A58 (DATA7), MOD4.A58 (DATA7), MOD5.A58 (DATA7), MOD6.A58 (DATA7), MOD7.A58 (DATA7), MOD8.A58 (DATA7)
/FRUpd: MOD1.B39 (FRUpd), MOD2.B39 (FRUpd), MOD3.B39 (FRUpd), MOD4.B39 (FRUpd), MOD5.B39 (FRUpd), MOD6.B39 (FRUpd), MOD7.B39 (FRUpd), MOD8.B39 (FRUpd)
/INTE: MOD1.B57 (INTE), MOD2.B57 (INTE), MOD3.B57 (INTE), MOD4.B57 (INTE), MOD5.B57 (INTE), MOD6.B57 (INTE), MOD7.B57 (INTE), MOD8.B57 (INTE)
/INTREQ: MOD1.A67 (INTREQ), MOD2.A67 (INTREQ), MOD3.A67 (INTREQ), MOD4.A67 (INTREQ), MOD5.A67 (INTREQ), MOD6.A67 (INTREQ), MOD7.A67 (INTREQ), MOD8.A67 (INTREQ)
/L0: MOD1.B33 (L0), MOD2.B33 (L0), MOD3.B33 (L0), MOD4.B33 (L0), MOD5.B33 (L0), MOD6.B33 (L0), MOD7.B33 (L0), MOD8.B33 (L0)
/L1: MOD1.B34 (L1), MOD2.B34 (L1), MOD3.B34 (L1), MOD4.B34 (L1), MOD5.B34 (L1), MOD6.B34 (L1), MOD7.B34 (L1), MOD8.B34 (L1)
/L2: MOD1.B35 (L2), MOD2.B35 (L2), MOD3.B35 (L2), MOD4.B35 (L2), MOD5.B35 (L2), MOD6.B35 (L2), MOD7.B35 (L2), MOD8.B35 (L2)
/L3: MOD1.B36 (L3), MOD2.B36 (L3), MOD3.B36 (L3), MOD4.B36 (L3), MOD5.B36 (L3), MOD6.B36 (L3), MOD7.B36 (L3), MOD8.B36 (L3)
/L4: MOD1.B79 (L4), MOD2.B79 (L4), MOD3.B79 (L4), MOD4.B79 (L4), MOD5.B79 (L4), MOD6.B79 (L4), MOD7.B79 (L4), MOD8.B79 (L4)
/LADRH: MOD1.A30 (LADRH), MOD2.A30 (LADRH), MOD3.A30 (LADRH), MOD4.A30 (LADRH), MOD5.A30 (LADRH), MOD6.A30 (LADRH), MOD7.A30 (LADRH), MOD8.A30 (LADRH)
/LADRL: MOD1.A31 (LADRL), MOD2.A31 (LADRL), MOD3.A31 (LADRL), MOD4.A31 (LADRL), MOD5.A31 (LADRL), MOD6.A31 (LADRL), MOD7.A31 (LADRL), MOD8.A31 (LADRL)
/LPCH: MOD1.A17 (LPCH), MOD2.A17 (LPCH), MOD3.A17 (LPCH), MOD4.A17 (LPCH), MOD5.A17 (LPCH), MOD6.A17 (LPCH), MOD7.A17 (LPCH), MOD8.A17 (LPCH)
/LPCL: MOD1.A18 (LPCL), MOD2.A18 (LPCL), MOD3.A18 (LPCL), MOD4.A18 (LPCL), MOD5.A18 (LPCL), MOD6.A18 (LPCL), MOD7.A18 (LPCL), MOD8.A18 (LPCL)
/LSPH: MOD1.A15 (LSPH), MOD2.A15 (LSPH), MOD3.A15 (LSPH), MOD4.A15 (LSPH), MOD5.A15 (LSPH), MOD6.A15 (LSPH), MOD7.A15 (LSPH), MOD8.A15 (LSPH)
/LSPL: MOD1.A16 (LSPL), MOD2.A16 (LSPL), MOD3.A16 (LSPL), MOD4.A16 (LSPL), MOD5.A16 (LSPL), MOD6.A16 (LSPL), MOD7.A16 (LSPL), MOD8.A16 (LSPL)
/PCINC: J2.4, MOD1.B47 (PCINC), MOD2.B47 (PCINC), MOD3.B47 (PCINC), MOD4.B47 (PCINC), MOD5.B47 (PCINC), MOD6.B47 (PCINC), MOD7.B47 (PCINC), MOD8.B47 (PCINC)
/PULSE: MOD1.B74 (PULSE), MOD2.B74 (PULSE), MOD3.B74 (PULSE), MOD4.B74 (PULSE), MOD5.B74 (PULSE), MOD6.B74 (PULSE), MOD7.B74 (PULSE), MOD8.B74 (PULSE)
/R0: MOD1.B40 (R0), MOD2.B40 (R0), MOD3.B40 (R0), MOD4.B40 (R0), MOD5.B40 (R0), MOD6.B40 (R0), MOD7.B40 (R0), MOD8.B40 (R0)
/R1: MOD1.B42 (R1), MOD2.B42 (R1), MOD3.B42 (R1), MOD4.B42 (R1), MOD5.B42 (R1), MOD6.B42 (R1), MOD7.B42 (R1), MOD8.B42 (R1)
/R2: MOD1.B43 (R2), MOD2.B43 (R2), MOD3.B43 (R2), MOD4.B43 (R2), MOD5.B43 (R2), MOD6.B43 (R2), MOD7.B43 (R2), MOD8.B43 (R2)
/R3: MOD1.B44 (R3), MOD2.B44 (R3), MOD3.B44 (R3), MOD4.B44 (R3), MOD5.B44 (R3), MOD6.B44 (R3), MOD7.B44 (R3), MOD8.B44 (R3)
/R4: MOD1.B80 (R4), MOD2.B80 (R4), MOD3.B80 (R4), MOD4.B80 (R4), MOD5.B80 (R4), MOD6.B80 (R4), MOD7.B80 (R4), MOD8.B80 (R4)
/RESET: MOD1.A69 (RESET), MOD2.A69 (RESET), MOD3.A69 (RESET), MOD4.A69 (RESET), MOD5.A69 (RESET), MOD6.A69 (RESET), MOD7.A69 (RESET), MOD8.A69 (RESET)
/SPDEC: MOD1.B53 (SPDEC), MOD2.B53 (SPDEC), MOD3.B53 (SPDEC), MOD4.B53 (SPDEC), MOD5.B53 (SPDEC), MOD6.B53 (SPDEC), MOD7.B53 (SPDEC), MOD8.B53 (SPDEC)
/SPINC: MOD1.B54 (SPINC), MOD2.B54 (SPINC), MOD3.B54 (SPINC), MOD4.B54 (SPINC), MOD5.B54 (SPINC), MOD6.B54 (SPINC), MOD7.B54 (SPINC), MOD8.B54 (SPINC)
/STATE0: MOD1.A33 (STATE0), MOD2.A33 (STATE0), MOD3.A33 (STATE0), MOD4.A33 (STATE0), MOD5.A33 (STATE0), MOD6.A33 (STATE0), MOD7.A33 (STATE0), MOD8.A33 (STATE0)
/STATE1: MOD1.A34 (STATE1), MOD2.A34 (STATE1), MOD3.A34 (STATE1), MOD4.A34 (STATE1), MOD5.A34 (STATE1), MOD6.A34 (STATE1), MOD7.A34 (STATE1), MOD8.A34 (STATE1)
/STATE2: MOD1.A35 (STATE2), MOD2.A35 (STATE2), MOD3.A35 (STATE2), MOD4.A35 (STATE2), MOD5.A35 (STATE2), MOD6.A35 (STATE2), MOD7.A35 (STATE2), MOD8.A35 (STATE2)
/STATE3: MOD1.A36 (STATE3), MOD2.A36 (STATE3), MOD3.A36 (STATE3), MOD4.A36 (STATE3), MOD5.A36 (STATE3), MOD6.A36 (STATE3), MOD7.A36 (STATE3), MOD8.A36 (STATE3)
/STATE4: MOD1.A37 (STATE4), MOD2.A37 (STATE4), MOD3.A37 (STATE4), MOD4.A37 (STATE4), MOD5.A37 (STATE4), MOD6.A37 (STATE4), MOD7.A37 (STATE4), MOD8.A37 (STATE4)
/STATE5: MOD1.A38 (STATE5), MOD2.A38 (STATE5), MOD3.A38 (STATE5), MOD4.A38 (STATE5), MOD5.A38 (STATE5), MOD6.A38 (STATE5), MOD7.A38 (STATE5), MOD8.A38 (STATE5)
/STATE6: MOD1.A39 (STATE6), MOD2.A39 (STATE6), MOD3.A39 (STATE6), MOD4.A39 (STATE6), MOD5.A39 (STATE6), MOD6.A39 (STATE6), MOD7.A39 (STATE6), MOD8.A39 (STATE6)
/STATE7: MOD1.A40 (STATE7), MOD2.A40 (STATE7), MOD3.A40 (STATE7), MOD4.A40 (STATE7), MOD5.A40 (STATE7), MOD6.A40 (STATE7), MOD7.A40 (STATE7), MOD8.A40 (STATE7)
/STATE8: J2.5, MOD1.A42 (STATE8), MOD2.A42 (STATE8), MOD3.A42 (STATE8), MOD4.A42 (STATE8), MOD5.A42 (STATE8), MOD6.A42 (STATE8), MOD7.A42 (STATE8), MOD8.A42 (STATE8)
/STATE9: J2.6, MOD1.A43 (STATE9), MOD2.A43 (STATE9), MOD3.A43 (STATE9), MOD4.A43 (STATE9), MOD5.A43 (STATE9), MOD6.A43 (STATE9), MOD7.A43 (STATE9), MOD8.A43 (STATE9)
/STATE10: J2.7, MOD1.A44 (STATE10), MOD2.A44 (STATE10), MOD3.A44 (STATE10), MOD4.A44 (STATE10), MOD5.A44 (STATE10), MOD6.A44 (STATE10), MOD7.A44 (STATE10), MOD8.A44 (STATE10)
/STATE11: J2.8, MOD1.A45 (STATE11), MOD2.A45 (STATE11), MOD3.A45 (STATE11), MOD4.A45 (STATE11), MOD5.A45 (STATE11), MOD6.A45 (STATE11), MOD7.A45 (STATE11), MOD8.A45 (STATE11)
/STATE12: J2.9, MOD1.A46 (STATE12), MOD2.A46 (STATE12), MOD3.A46 (STATE12), MOD4.A46 (STATE12), MOD5.A46 (STATE12), MOD6.A46 (STATE12), MOD7.A46 (STATE12), MOD8.A46 (STATE12)
/STATE13: J2.10, MOD1.A47 (STATE13), MOD2.A47 (STATE13), MOD3.A47 (STATE13), MOD4.A47 (STATE13), MOD5.A47 (STATE13), MOD6.A47 (STATE13), MOD7.A47 (STATE13), MOD8.A47 (STATE13)
/STATE14: J2.11, MOD1.A48 (STATE14), MOD2.A48 (STATE14), MOD3.A48 (STATE14), MOD4.A48 (STATE14), MOD5.A48 (STATE14), MOD6.A48 (STATE14), MOD7.A48 (STATE14), MOD8.A48 (STATE14)
/STATE15: J2.12, MOD1.A49 (STATE15), MOD2.A49 (STATE15), MOD3.A49 (STATE15), MOD4.A49 (STATE15), MOD5.A49 (STATE15), MOD6.A49 (STATE15), MOD7.A49 (STATE15), MOD8.A49 (STATE15)
/STATE16: MOD1.A79 (STATE16), MOD2.A79 (STATE16), MOD3.A79 (STATE16), MOD4.A79 (STATE16), MOD5.A79 (STATE16), MOD6.A79 (STATE16), MOD7.A79 (STATE16), MOD8.A79 (STATE16)
/~ALUCI: MOD1.B38 (~ALUCI), MOD2.B38 (~ALUCI), MOD3.B38 (~ALUCI), MOD4.B38 (~ALUCI), MOD5.B38 (~ALUCI), MOD6.B38 (~ALUCI), MOD7.B38 (~ALUCI), MOD8.B38 (~ALUCI)
/~ALUCO: MOD1.A61 (~ALUCO), MOD2.A61 (~ALUCO), MOD3.A61 (~ALUCO), MOD4.A61 (~ALUCO), MOD5.A61 (~ALUCO), MOD6.A61 (~ALUCO), MOD7.A61 (~ALUCO), MOD8.A61 (~ALUCO)
/~CLK: MOD1.B73 (~CLK), MOD2.B73 (~CLK), MOD3.B73 (~CLK), MOD4.B73 (~CLK), MOD5.B73 (~CLK), MOD6.B73 (~CLK), MOD7.B73 (~CLK), MOD8.B73 (~CLK)
/~HALT: MOD1.B46 (~HALT), MOD2.B46 (~HALT), MOD3.B46 (~HALT), MOD4.B46 (~HALT), MOD5.B46 (~HALT), MOD6.B46 (~HALT), MOD7.B46 (~HALT), MOD8.B46 (~HALT)
/~INTD: MOD1.B58 (~INTD), MOD2.B58 (~INTD), MOD3.B58 (~INTD), MOD4.B58 (~INTD), MOD5.B58 (~INTD), MOD6.B58 (~INTD), MOD7.B58 (~INTD), MOD8.B58 (~INTD)
/~LAC: MOD1.A21 (~LAC), MOD2.A21 (~LAC), MOD3.A21 (~LAC), MOD4.A21 (~LAC), MOD5.A21 (~LAC), MOD6.A21 (~LAC), MOD7.A21 (~LAC), MOD8.A21 (~LAC)
/~LARGH: MOD1.A19 (~LARGH), MOD2.A19 (~LARGH), MOD3.A19 (~LARGH), MOD4.A19 (~LARGH), MOD5.A19 (~LARGH), MOD6.A19 (~LARGH), MOD7.A19 (~LARGH), MOD8.A19 (~LARGH)
/~LARGL: MOD1.A20 (~LARGL), MOD2.A20 (~LARGL), MOD3.A20 (~LARGL), MOD4.A20 (~LARGL), MOD5.A20 (~LARGL), MOD6.A20 (~LARGL), MOD7.A20 (~LARGL), MOD8.A20 (~LARGL)
/~LFR: MOD1.A28 (~LFR), MOD2.A28 (~LFR), MOD3.A28 (~LFR), MOD4.A28 (~LFR), MOD5.A28 (~LFR), MOD6.A28 (~LFR), MOD7.A28 (~LFR), MOD8.A28 (~LFR)
/~LINST: MOD1.A29 (~LINST), MOD2.A29 (~LINST), MOD3.A29 (~LINST), MOD4.A29 (~LINST), MOD5.A29 (~LINST), MOD6.A29 (~LINST), MOD7.A29 (~LINST), MOD8.A29 (~LINST)
/~LMEM: MOD1.A14 (~LMEM), MOD2.A14 (~LMEM), MOD3.A14 (~LMEM), MOD4.A14 (~LMEM), MOD5.A14 (~LMEM), MOD6.A14 (~LMEM), MOD7.A14 (~LMEM), MOD8.A14 (~LMEM)
/~LXH: MOD1.A22 (~LXH), MOD2.A22 (~LXH), MOD3.A22 (~LXH), MOD4.A22 (~LXH), MOD5.A22 (~LXH), MOD6.A22 (~LXH), MOD7.A22 (~LXH), MOD8.A22 (~LXH)
/~LYH: MOD1.A25 (~LYH), MOD2.A25 (~LYH), MOD3.A25 (~LYH), MOD4.A25 (~LYH), MOD5.A25 (~LYH), MOD6.A25 (~LYH), MOD7.A25 (~LYH), MOD8.A25 (~LYH)
/~LYL: MOD1.A24 (~LYL), MOD2.A24 (~LYL), MOD3.A24 (~LYL), MOD4.A24 (~LYL), MOD5.A24 (~LYL), MOD6.A24 (~LYL), MOD7.A24 (~LYL), MOD8.A24 (~LYL)
/~LZH: MOD1.A27 (~LZH), MOD2.A27 (~LZH), MOD3.A27 (~LZH), MOD4.A27 (~LZH), MOD5.A27 (~LZH), MOD6.A27 (~LZH), MOD7.A27 (~LZH), MOD8.A27 (~LZH)
/~LZL: MOD1.A26 (~LZL), MOD2.A26 (~LZL), MOD3.A26 (~LZL), MOD4.A26 (~LZL), MOD5.A26 (~LZL), MOD6.A26 (~LZL), MOD7.A26 (~LZL), MOD8.A26 (~LZL)
/~RAC: MOD1.B21 (~RAC), MOD2.B21 (~RAC), MOD3.B21 (~RAC), MOD4.B21 (~RAC), MOD5.B21 (~RAC), MOD6.B21 (~RAC), MOD7.B21 (~RAC), MOD8.B21 (~RAC)
/~RALU: MOD1.B30 (~RALU), MOD2.B30 (~RALU), MOD3.B30 (~RALU), MOD4.B30 (~RALU), MOD5.B30 (~RALU), MOD6.B30 (~RALU), MOD7.B30 (~RALU), MOD8.B30 (~RALU)
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

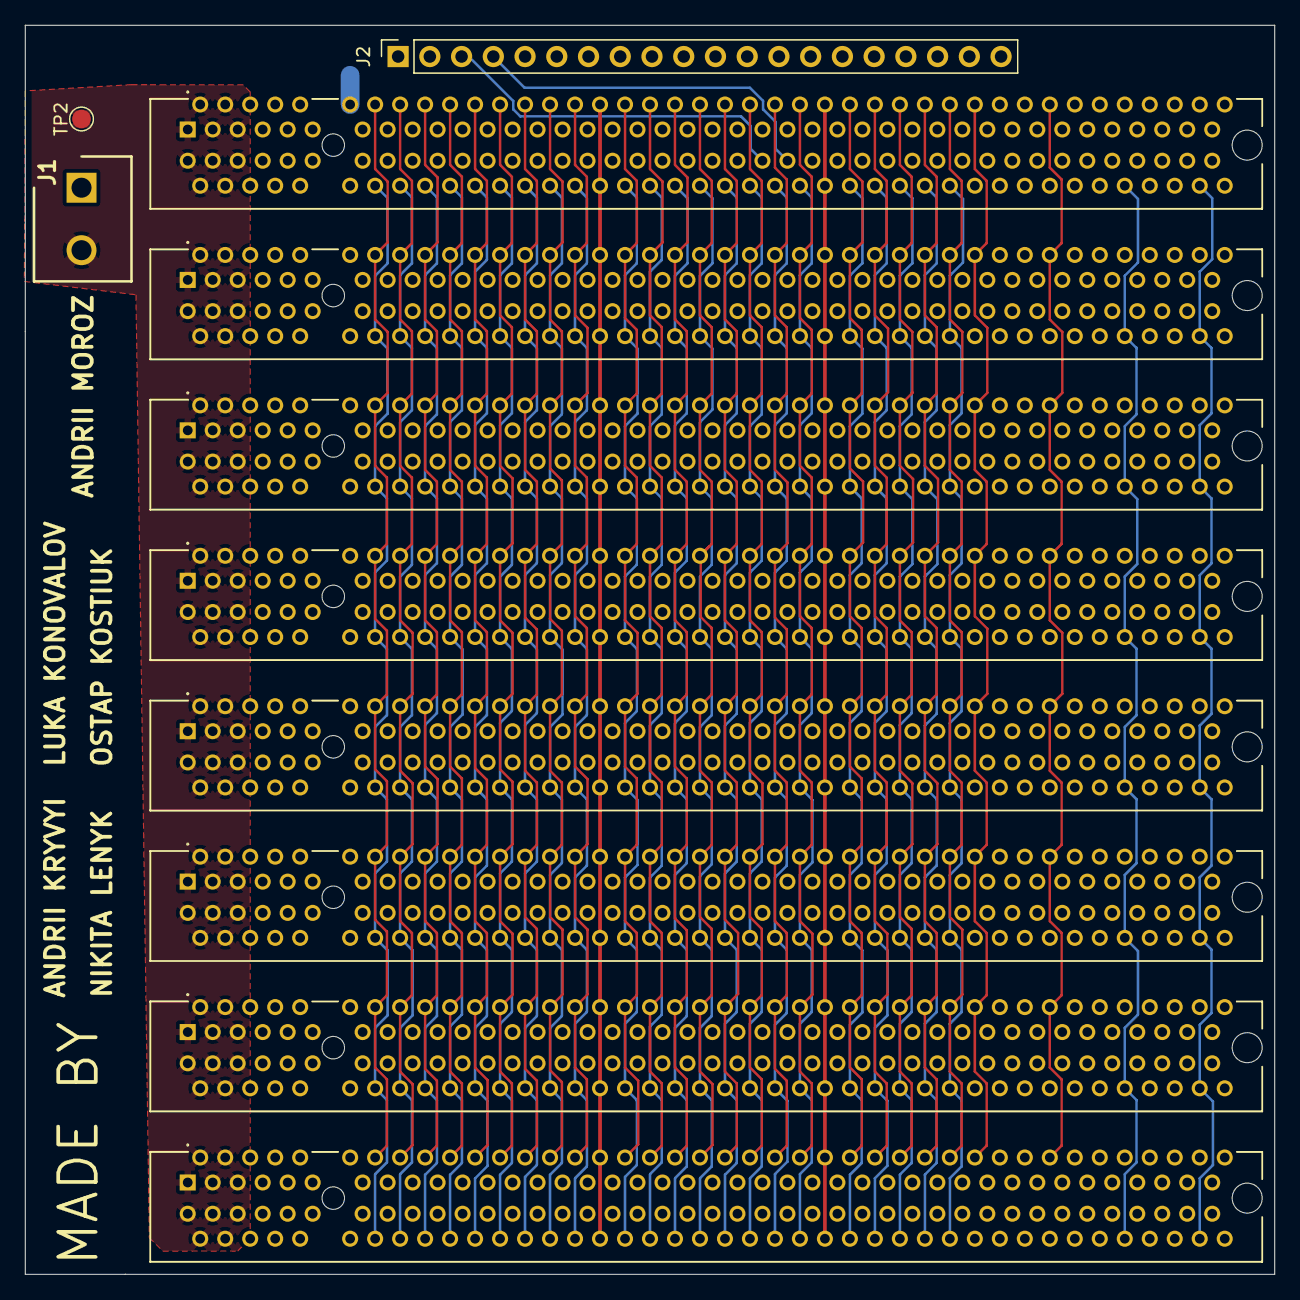
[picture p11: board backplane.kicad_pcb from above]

Board: 4 copper layers, 100.0 x 100.0 mm, 12 parts (1 on the bottom side), 97 nets.

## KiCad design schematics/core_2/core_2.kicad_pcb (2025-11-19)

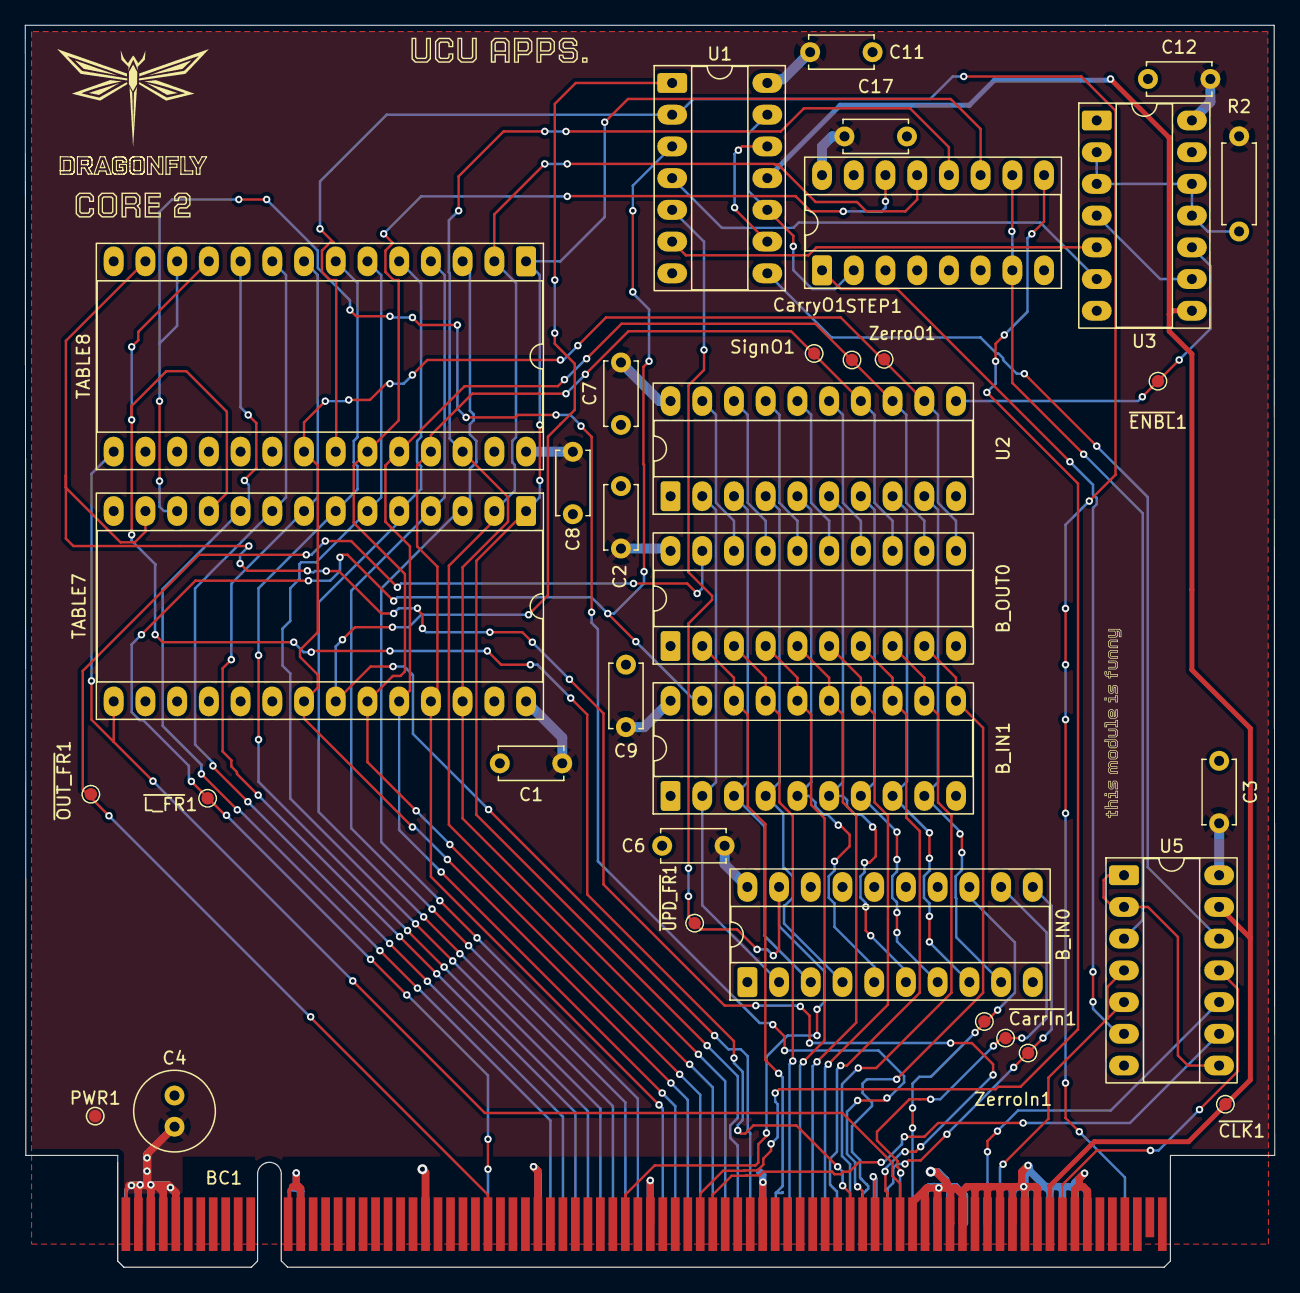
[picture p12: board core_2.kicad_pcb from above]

Board: 2 copper layers, 100.0 x 99.5 mm, 31 parts (0 on the bottom side), 67 nets.

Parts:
BC1: BusConnector; BUS_PCIexpress_x16
B_IN0, B_IN1: 74LS245; DIP-20_W7.62mm_Socket_LongPads
B_OUT0: 74LS245; DIP-20_W7.62mm_Socket_LongPads
C1, C2, C3, C6, C7, C8, C9, C11, C12, C17: C; C_Disc_D5.0mm_W2.5mm_P5.00mm
C4: C; C_Radial_D6.3mm_H5.0mm_P2.50mm
CarryO1: TestPoint; TestPoint_Pad_D1.0mm
PWR1: TestPoint; TestPoint_Pad_D1.0mm
R2: R; R_Axial_DIN0207_L6.3mm_D2.5mm_P7.62mm_Horizontal
STEP1: 74LS161; DIP-16_W7.62mm_Socket_LongPads
SignO1: TestPoint; TestPoint_Pad_D1.0mm
TABLE7, TABLE8: 28C256; DIP-28_W15.24mm_Socket_LongPads
U1: 74LS04; DIP-14_W7.62mm_Socket_LongPads
U2: 74LS574; DIP-20_W7.62mm_Socket_LongPads
U3: 74LS02; DIP-14_W7.62mm_Socket_LongPads
U5: 74LS00; DIP-14_W7.62mm_Socket_LongPads
ZerroIn1: TestPoint; TestPoint_Pad_D1.0mm
ZerroO1: TestPoint; TestPoint_Pad_D1.0mm
kibuzzard-691DDE8A: G***; kibuzzard-691DDE8A
kibuzzard-691DE0EC: G***; kibuzzard-691DE0EC
kibuzzard-6911C9E9: G***; kibuzzard-6911C9E9

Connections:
/AddrDecrement: BC1.B60 (ADRDEC), TABLE7.13 (D2), TABLE8.13 (D2)
/AddrIncrement: BC1.B61 (ADDRINC), TABLE7.15 (D3), TABLE8.15 (D3)
/Clk: STEP1.2 (CP), U1.10, U1.13
/D0: BC1.A51 (DATA0), B_IN1.18 (B0), B_OUT0.2 (A0)
/D1: BC1.A52 (DATA1), B_IN1.17 (B1), B_OUT0.3 (A1)
/D2: BC1.A53 (DATA2), B_IN1.16 (B2), B_OUT0.4 (A2)
/D3: BC1.A54 (DATA3), B_IN1.15 (B3), B_OUT0.5 (A3)
/D4: BC1.A55 (DATA4), B_IN1.14 (B4), B_OUT0.6 (A4)
/D5: BC1.A56 (DATA5), B_IN1.13 (B5), B_OUT0.7 (A5)
/D6: BC1.A57 (DATA6), B_IN1.12 (B6), B_OUT0.8 (A6)
/D7: BC1.A58 (DATA7), B_IN1.11 (B7), B_OUT0.9 (A7)
/IntEnable: BC1.B57 (INTE), TABLE7.11 (D0), TABLE8.11 (D0)
/Reset: BC1.A69 (RESET), U5.4, U5.5
/STATE0: BC1.A33 (STATE0), TABLE7.10 (A0), TABLE8.10 (A0)
/STATE1: BC1.A34 (STATE1), TABLE7.9 (A1), TABLE8.9 (A1)
/STATE2: BC1.A35 (STATE2), TABLE7.8 (A2), TABLE8.8 (A2)
/STATE3: BC1.A36 (STATE3), TABLE7.7 (A3), TABLE8.7 (A3)
/STATE4: BC1.A37 (STATE4), TABLE7.6 (A4), TABLE8.6 (A4)
/STATE5: BC1.A38 (STATE5), TABLE7.5 (A5), TABLE8.5 (A5)
/STATE6: BC1.A39 (STATE6), TABLE7.4 (A6), TABLE8.4 (A6)
/STATE7: BC1.A40 (STATE7), TABLE7.3 (A7), TABLE8.3 (A7)
/STATE8: BC1.A42 (STATE8), B_OUT0.13 (B5), SignO1.1, TABLE7.25 (A8), TABLE8.25 (A8), U2.14 (Q5)
/STATE9: BC1.A43 (STATE9), B_OUT0.12 (B6), CarryO1.1, TABLE7.24 (A9), TABLE8.24 (A9), U2.13 (Q6)
/STATE10: BC1.A44 (STATE10), B_OUT0.11 (B7), TABLE7.21 (A10), TABLE8.21 (A10), U2.12 (Q7), ZerroO1.1
/STATE11: BC1.A45 (STATE11), STEP1.14 (Q0), TABLE7.23 (A11), TABLE8.23 (A11)
/STATE12: BC1.A46 (STATE12), STEP1.13 (Q1), TABLE7.2 (A12), TABLE8.2 (A12)
/STATE13: BC1.A47 (STATE13), STEP1.12 (Q2), TABLE7.26 (A13), TABLE8.26 (A13)
/STATE14: BC1.A48 (STATE14), STEP1.11 (Q3), TABLE7.1 (A14), TABLE8.1 (A14)
/STATE15: BC1.A49 (STATE15), TABLE7.22 (~OE), U1.1
/STATE16: BC1.A79 (STATE16), TABLE8.22 (~OE), U1.2
/SignIn: BC1.A62 (ALUSO), B_IN0.13 (B5)
/ZeroIn: BC1.A60 (ALUZO), B_IN0.11 (B7), ZerroIn1.1
/~CLK: BC1.B73 (~CLK), U1.11, U3.8, U5.13
/~CarryIn: BC1.A61 (~ALUCO), B_IN0.12 (B6)
/~Halt: BC1.B46 (~HALT), U5.9
/~IntDisable: BC1.B58 (~INTD), TABLE7.12 (D1), TABLE8.12 (D1)
/~LOAD_FR: BC1.A28 (~LFR), B_IN1.19 (CE), U1.3
/~OUT_FR: BC1.B28 (~RFR), B_OUT0.19 (CE)
/~SCClear: BC1.B45 (~SCCLR), STEP1.9 (~PE)
/~UPDATE_FR: BC1.B39 (FRUpd), B_IN0.19 (CE), U1.5
/~Wait: BC1.A68 (~WAIT), U5.10
GND: BC1.A12 (GND), BC1.A13 (GND), BC1.A23 (GND), BC1.A32 (GND), BC1.A41 (GND), BC1.A50 (GND), BC1.A59 (GND), BC1.A63 (GND), BC1.A64 (GND), BC1.A65 (GND), BC1.A66 (GND), BC1.A70 (GND), BC1.A71 (GND), BC1.A72 (GND), BC1.A73 (GND), BC1.A74 (GND), BC1.A75 (GND), BC1.A76 (GND), BC1.B12 (GND), BC1.B13 (GND), BC1.B23 (GND), BC1.B32 (GND), BC1.B41 (GND), BC1.B50 (GND), BC1.B59 (GND), BC1.B62 (GND), BC1.B63 (GND), BC1.B64 (GND), BC1.B65 (GND), BC1.B66 (GND), BC1.B67 (GND), BC1.B68 (GND), BC1.B69 (GND), BC1.B70 (GND), BC1.B71 (GND), BC1.B72 (GND), BC1.B75 (GND), BC1.B76 (GND), B_IN0.1 (A->B), B_IN0.10 (GND), B_IN0.14 (B4), B_IN0.15 (B3), B_IN0.16 (B2), B_IN0.17 (B1), B_IN0.18 (B0), B_IN1.1 (A->B), B_IN1.10 (GND), B_OUT0.1 (A->B), B_OUT0.10 (GND), C1.2, C2.2, C3.2, C4.2, C6.1, C7.1, C8.1, C9.1, C11.2, C12.2, C17.2, STEP1.3 (D0), STEP1.4 (D1), STEP1.5 (D2), STEP1.6 (D3), STEP1.8 (GND), TABLE7.14 (GND), TABLE7.20 (~CS), TABLE7.27 (~WE), TABLE8.14 (GND), TABLE8.20 (~CS), TABLE8.27 (~WE), U1.7 (GND), U2.1 (OE), U2.10 (GND), U3.7 (GND), U5.7 (GND)
unnamed: BC1.B74 (PULSE), U5.11
unnamed: B_IN0.2 (A0), B_IN1.2 (A0), U2.2 (D0)
unnamed: B_IN0.3 (A1), B_IN1.3 (A1), U2.3 (D1)
unnamed: B_IN0.4 (A2), B_IN1.4 (A2), U2.4 (D2)
unnamed: B_IN0.5 (A3), B_IN1.5 (A3), U2.5 (D3)
unnamed: B_IN0.6 (A4), B_IN1.6 (A4), U2.6 (D4)
unnamed: B_IN0.7 (A5), B_IN1.7 (A5), U2.7 (D5)
unnamed: B_IN0.8 (A6), B_IN1.8 (A6), U2.8 (D6)
unnamed: B_IN0.9 (A7), B_IN1.9 (A7), U2.9 (D7)
unnamed: B_OUT0.18 (B0), U2.19 (Q0)
unnamed: B_OUT0.17 (B1), U2.18 (Q1)
unnamed: B_OUT0.16 (B2), U2.17 (Q2)
unnamed: B_OUT0.15 (B3), U2.16 (Q3)
unnamed: B_OUT0.14 (B4), U2.15 (Q4)
unnamed: R2.2, U3.2, U3.3, U3.11, U3.12
unnamed: STEP1.7 (CEP), STEP1.10 (CET), U5.3
unnamed: STEP1.1 (~MR), U5.6
unnamed: U1.4, U3.6
unnamed: U1.6, U3.5
unnamed: U1.8, U5.12
unnamed: U1.9, U1.12
unnamed: U2.11 (Cp), U3.10
unnamed: U3.4, U3.9
unnamed: U5.1, U5.2, U5.8
VCC: BC1.A1 (VCC), BC1.A2 (VCC), BC1.A3 (VCC), BC1.A4 (VCC), BC1.A5 (VCC), BC1.B1 (VCC), BC1.B2 (VCC), BC1.B3 (VCC), BC1.B4 (VCC), BC1.B5 (VCC), B_IN0.20 (VCC), B_IN1.20 (VCC), B_OUT0.20 (VCC), C1.1, C2.1, C3.1, C4.1, C6.2, C7.2, C8.2, C9.2, C11.1, C12.1, C17.1, PWR1.1, R2.1, STEP1.16 (VCC), TABLE7.28 (VCC), TABLE8.28 (VCC), U1.14 (VCC), U2.20 (VCC), U3.14 (VCC), U5.14 (VCC)

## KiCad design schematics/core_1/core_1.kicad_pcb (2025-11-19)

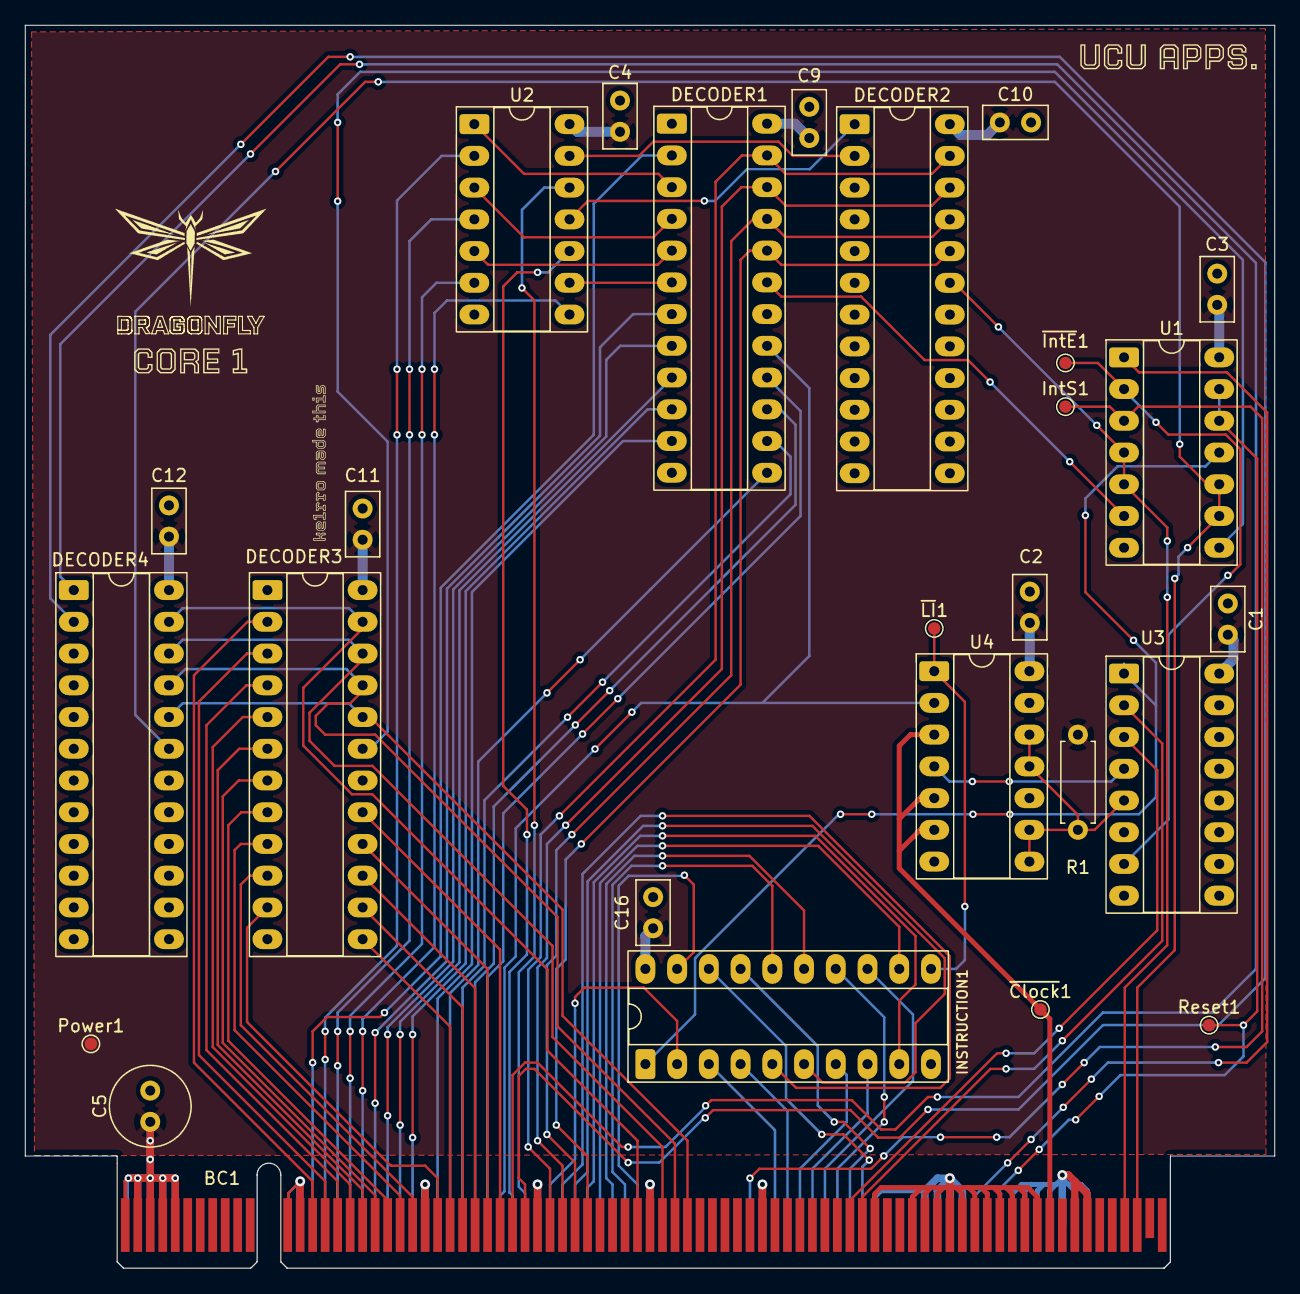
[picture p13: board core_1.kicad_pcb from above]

Board: 2 copper layers, 100.0 x 99.5 mm, 27 parts (0 on the bottom side), 81 nets.

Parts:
BC1: BusConnector; BUS_PCIexpress_x16
C1, C2, C3, C4, C9, C10, C11, C12, C16: C; C_Disc_D5.0mm_W2.5mm_P2.50mm
C5: C; C_Radial_D6.3mm_H5.0mm_P2.50mm
DECODER1, DECODER2, DECODER3, DECODER4: 74LS154; DIP-24_W7.62mm_Socket_LongPads
INSTRUCTION1: 74LS273; DIP-20_W7.62mm_Socket_LongPads
IntS1: IntS; TestPoint_Pad_D1.0mm
Power1: Power; TestPoint_Pad_D1.0mm
R1: 5kOhm; R_Axial_DIN0207_L6.3mm_D2.5mm_P7.62mm_Horizontal
Reset1: Reset; TestPoint_Pad_D1.0mm
U1: 74LS00; DIP-14_W7.62mm_Socket_LongPads
U2: 74LS04; DIP-14_W7.62mm_Socket_LongPads
U3: 74LS109; DIP-16_W7.62mm_Socket_LongPads
U4: 74LS02; DIP-14_W7.62mm_Socket_LongPads
kibuzzard-691DE05D: G***; kibuzzard-691DE05D
kibuzzard-691DE084: G***; kibuzzard-691DE084
kibuzzard-6911CC41: G***; kibuzzard-6911CC41

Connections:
/AddrHighIn: BC1.A30 (LADRH), U2.10
/AddrLowIn: BC1.A31 (LADRL), U2.12
/BUS0: BC1.A51 (DATA0), INSTRUCTION1.3 (D0)
/BUS1: BC1.A52 (DATA1), INSTRUCTION1.4 (D1)
/BUS2: BC1.A53 (DATA2), INSTRUCTION1.7 (D2)
/BUS3: BC1.A54 (DATA3), INSTRUCTION1.8 (D3)
/BUS4: BC1.A55 (DATA4), INSTRUCTION1.13 (D4)
/BUS5: BC1.A56 (DATA5), INSTRUCTION1.14 (D5)
/BUS6: BC1.A57 (DATA6), INSTRUCTION1.17 (D6)
/BUS7: BC1.A58 (DATA7), INSTRUCTION1.18 (D7)
/IRQ: BC1.A67 (INTREQ), U1.1
/IntEnable: BC1.B57 (INTE), U3.3 (~K)
/L0: BC1.B33 (L0), DECODER1.23 (A0), DECODER2.23 (A0)
/L1: BC1.B34 (L1), DECODER1.22 (A1), DECODER2.22 (A1)
/L2: BC1.B35 (L2), DECODER1.21 (A2), DECODER2.21 (A2)
/L3: BC1.B36 (L3), DECODER1.20 (A3), DECODER2.20 (A3)
/L4: BC1.B79 (L4), DECODER2.19 (E1), U1.4, U1.5
/PCHighReader: BC1.A17 (LPCH), U2.6
/PCLowReader: BC1.A18 (LPCL), U2.8
/R0: BC1.B40 (R0), DECODER3.23 (A0), DECODER4.23 (A0)
/R1: BC1.B42 (R1), DECODER3.22 (A1), DECODER4.22 (A1)
/R2: BC1.B43 (R2), DECODER3.21 (A2), DECODER4.21 (A2)
/R3: BC1.B44 (R3), DECODER3.20 (A3), DECODER4.20 (A3)
/R4: BC1.B80 (R4), DECODER4.19 (E1), U1.9, U1.10
/Reset: BC1.A69 (RESET), Reset1.1, U1.12, U1.13
/SPHighReader: BC1.A15 (LSPH), U2.2
/SPLowReader: BC1.A16 (LSPL), U2.4
/STATE0: BC1.A33 (STATE0), INSTRUCTION1.2 (Q0)
/STATE1: BC1.A34 (STATE1), INSTRUCTION1.5 (Q1)
/STATE2: BC1.A35 (STATE2), INSTRUCTION1.6 (Q2)
/STATE3: BC1.A36 (STATE3), INSTRUCTION1.9 (Q3)
/STATE4: BC1.A37 (STATE4), INSTRUCTION1.12 (Q4)
/STATE5: BC1.A38 (STATE5), INSTRUCTION1.15 (Q5)
/STATE6: BC1.A39 (STATE6), INSTRUCTION1.16 (Q6)
/STATE7: BC1.A40 (STATE7), INSTRUCTION1.19 (Q7)
/~ALUWriter: BC1.B30 (~RALU), DECODER4.1 (S0)
/~AccumReader: BC1.A21 (~LAC), DECODER1.9 (S8)
/~AccumWriter: BC1.B21 (~RAC), DECODER3.9 (S8)
/~AddressHighReader: DECODER2.1 (S0), U2.11
/~AddressLowReader: DECODER2.2 (S1), U2.13
/~Clk: BC1.B73 (~CLK), U4.3, U4.5, U4.6
/~ConstantWriter: BC1.B29 (~RCONST), DECODER3.17 (S15)
/~FlagsReader: BC1.A28 (~LFR), DECODER1.16 (S14)
/~FlagsWriter: BC1.B28 (~RFR), DECODER3.16 (S14)
/~InstructionReader: BC1.A29 (~LINST), DECODER1.17 (S15), U4.2
/~IntAck: BC1.B31 (~RINTC), DECODER4.2 (S1)
/~IntDisable: BC1.B58 (~INTD), U3.2 (J)
/~MemoryReader: BC1.A14 (~LMEM), DECODER1.2 (S1)
/~MemoryWriter: BC1.B14 (~RMEM), DECODER3.2 (S1)
/~PCHighReader: DECODER1.5 (S4), U2.5
/~PCHighWriter: BC1.B17 (~RPCH), DECODER3.5 (S4)
/~PCLowReader: DECODER1.6 (S5), U2.9
/~PCLowWriter: BC1.B18 (~RPCL), DECODER3.6 (S5)
/~Reset: INSTRUCTION1.1 (~Mr), U1.11, U3.1 (~R)
/~SPHighReader: DECODER1.3 (S2), U2.1
/~SPHighWriter: BC1.B15 (~RSPH), DECODER3.3 (S2)
/~SPLowReader: DECODER1.4 (S3), U2.3
/~SPLowWriter: BC1.B16 (~RSPL), DECODER3.4 (S3)
/~TemporaryHighReader: BC1.A19 (~LARGH), DECODER1.7 (S6)
/~TemporaryHighWriter: BC1.B19 (~RARGH), DECODER3.7 (S6)
/~TemporaryLowReader: BC1.A20 (~LARGL), DECODER1.8 (S7)
/~TemporaryLowWriter: BC1.B20 (~RARGL), DECODER3.8 (S7)
/~XHReader: BC1.A22 (~LXH), DECODER1.10 (S9)
/~XHWriter: BC1.B22 (~RXH), DECODER3.10 (S9)
/~YHReader: BC1.A25 (~LYH), DECODER1.13 (S11)
/~YHWriter: BC1.B25 (~RYH), DECODER3.13 (S11)
/~YLReader: BC1.A24 (~LYL), DECODER1.11 (S10)
/~YLWriter: BC1.B24 (~RYL), DECODER3.11 (S10)
/~ZHReader: BC1.A27 (~LZH), DECODER1.15 (S13)
/~ZHWriter: BC1.B27 (~RZH), DECODER3.15 (S13)
/~ZLReader: BC1.A26 (~LZL), DECODER1.14 (S12)
/~ZLWriter: BC1.B26 (~RZL), DECODER3.14 (S12)
GND: BC1.A12 (GND), BC1.A13 (GND), BC1.A23 (GND), BC1.A32 (GND), BC1.A41 (GND), BC1.A50 (GND), BC1.A59 (GND), BC1.A63 (GND), BC1.A64 (GND), BC1.A65 (GND), BC1.A66 (GND), BC1.A70 (GND), BC1.A71 (GND), BC1.A72 (GND), BC1.A73 (GND), BC1.A74 (GND), BC1.A75 (GND), BC1.A76 (GND), BC1.B12 (GND), BC1.B13 (GND), BC1.B23 (GND), BC1.B32 (GND), BC1.B41 (GND), BC1.B50 (GND), BC1.B59 (GND), BC1.B62 (GND), BC1.B63 (GND), BC1.B64 (GND), BC1.B65 (GND), BC1.B66 (GND), BC1.B67 (GND), BC1.B68 (GND), BC1.B69 (GND), BC1.B70 (GND), BC1.B71 (GND), BC1.B72 (GND), BC1.B75 (GND), BC1.B76 (GND), C1.2, C2.2, C3.2, C4.2, C5.2, C9.2, C10.2, C11.2, C12.2, C16.2, DECODER1.12 (GND), DECODER1.18 (E0), DECODER2.12 (GND), DECODER2.18 (E0), DECODER3.12 (GND), DECODER3.18 (E0), DECODER4.12 (GND), DECODER4.18 (E0), INSTRUCTION1.10 (GND), U1.7 (GND), U2.7 (GND), U3.8 (GND), U3.15 (~R), U4.7 (GND)
unnamed: BC1.A49 (STATE15), IntS1.1, U1.3
unnamed: DECODER1.19 (E1), U1.6
unnamed: DECODER3.19 (E1), U1.8
unnamed: INSTRUCTION1.11 (Cp), U4.1
unnamed: U3.4 (C), U4.4
unnamed: U1.2, U3.7 (~Q)
unnamed: R1.2, U3.5 (~S), U4.8, U4.9, U4.11, U4.12
VCC: BC1.A1 (VCC), BC1.A2 (VCC), BC1.A3 (VCC), BC1.A4 (VCC), BC1.A5 (VCC), BC1.B1 (VCC), BC1.B2 (VCC), BC1.B3 (VCC), BC1.B4 (VCC), BC1.B5 (VCC), C1.1, C2.1, C3.1, C4.1, C5.1, C9.1, C10.1, C11.1, C12.1, C16.1, DECODER1.24 (VCC), DECODER2.24 (VCC), DECODER3.24 (VCC), DECODER4.24 (VCC), INSTRUCTION1.20 (VCC), Power1.1, R1.1, U1.14 (VCC), U2.14 (VCC), U3.16 (VCC), U4.14 (VCC)

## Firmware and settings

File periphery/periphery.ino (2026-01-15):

#pragma GCC diagnostic ignored "-Wunused-parameter"
// #include <LiquidCrystal.h>
#include "ROMData.h"

#define BAUD_RATE 115200

#define HEADER F("time,not_read,not_write,address,data,clk")

#define PIN_DATA_DIR 2
#define PIN_DATA_EN 3
#define DATA_DIRECTION_INPUT HIGH
#define DATA_DIRECTION_OUTPUT LOW
const uint8_t PIN_DATA[8] = {22, 23, 24, 25, 26, 27, 28, 29};
const uint8_t PIN_ADDRESS[16] = {32, 33, 34, 35, 36, 37, 38, 39, 40, 41, 42, 43, 44, 45, 46, 47};

#define PIN_CTL_NREAD  7
#define PIN_CTL_NWRITE 6

#define PIN_BTN1 A3
#define PIN_BTN2 A4

#define PIN_CLK A5
#define PIN_CLK_OUT A6

#define EDGE_RISING 0x01
#define EDGE_FALLING 0xff
#define EDGE_TRIGGER EDGE_RISING

#define PIN_DISPLAY_RS     8
#define PIN_DISPLAY_ENABLE 9
#define PIN_DISPLAY_D4     10
#define PIN_DISPLAY_D5     11
#define PIN_DISPLAY_D6     12
#define PIN_DISPLAY_D7     13

#define OPERATION_NOP 0
#define OPERATION_READ 1
#define OPERATION_WRITE 2

#define DISPLAY_COLS 16
#define DISPLAY_ROWS 2
#define DISPLAY_CHARSIZE LCD_5x8DOTS
#define DISPLAY_SIZE DISPLAY_COLS * DISPLAY_ROWS

volatile uint8_t memoryRW[6144];
volatile uint8_t memoryStack[1024];

/*** CONTROL BUS ***/
uint8_t controlGetOperation(uint8_t not_read, uint8_t not_write) {
  if(!not_read && !not_write) {
    return OPERATION_NOP;
  }

  if(!not_read) {
    return OPERATION_READ;
  }
  
  if(!not_write) {
    return OPERATION_WRITE;
  }

  return OPERATION_NOP;
}

/*** ADDRESS BUS ***/
uint16_t addressRead() {
  uint16_t result = 0;
  uint8_t i;

  for (i = 0; i < 16; i++) {
    result |= digitalRead(PIN_ADDRESS[i]) << i;
  }
  return result;
}

void addressSetup() {
  uint8_t i;

  for (i = 0; i < 16; i++) {
    pinMode(PIN_ADDRESS[i], INPUT_PULLUP);
  }
}


/*** DATA BUS ***/
bool dataIsInput = false;

inline void dataSetInput(bool isInput) {
  uint8_t i;

  if (dataIsInput == isInput)
    return;

  digitalWrite(PIN_DATA_EN, HIGH);
  delayMicroseconds(1);

  if (isInput)
    digitalWrite(PIN_DATA_DIR, DATA_DIRECTION_INPUT);
  else
    digitalWrite(PIN_DATA_DIR, DATA_DIRECTION_OUTPUT);
  delayMicroseconds(1);

  for (i = 0; i < 8; i++) {
    if (isInput)
      pinMode(PIN_DATA[i], INPUT);
    else
      pinMode(PIN_DATA[i], OUTPUT);
  }

  digitalWrite(PIN_DATA_EN, LOW);

  dataIsInput = isInput;
}

void dataWrite(uint8_t value) {
  dataSetInput(false);

  uint8_t i;

  for (i = 0; i < 8; ++i) {
    digitalWrite(PIN_DATA[i], (value >> i) & 1);
  }
}

uint8_t dataRead(bool force = true) {
  uint8_t value = 0;
  uint8_t i;

  if (force)
    dataSetInput(true);

  for (i = 0; i < 8; ++i) {
    value |= digitalRead(PIN_DATA[i]) << i;
  }

  return value;
}

void dataSetup() {
  dataSetInput(true);
}

/*** BUTTONS ***/
// uint8_t buttonsGet() {
//   return digitalRead(PIN_BTN1) | (digitalRead(PIN_BTN2) << 1);
// }

// void buttonsSetup() {
//   pinMode(PIN_BTN1, INPUT);
//   pinMode(PIN_BTN2, INPUT);
// }

/*** SERIAL COM ***/
void serialSetup();

void serialSetup() {
  Serial.begin(BAUD_RATE);
}

/*** DISPLAY ***/
// LiquidCrystal display(
//   PIN_DISPLAY_RS, PIN_DISPLAY_ENABLE,
//   PIN_DISPLAY_D4, PIN_DISPLAY_D5,
//   PIN_DISPLAY_D6, PIN_DISPLAY_D7
// );
// void displaySet(uint8_t position);
// void displaySetup();

// void displaySet(uint8_t position, uint8_t value) {
//   display.setCursor(position % DISPLAY_COLS, position / DISPLAY_COLS);
//   display.write(value);
// }

// void displaySetup() {
//   display.begin(DISPLAY_COLS, DISPLAY_ROWS, DISPLAY_CHARSIZE);
// }

/*** MEMORY ***/
uint8_t memoryRead(uint16_t address);
void memoryWrite(uint16_t address, uint8_t value);

uint8_t memoryRead(uint16_t address) {
  // 0x0000 -- 0x27FF
  if (address < 0x2800) {
    // to ROM: 0x0000 -- 0x27FF
    return pgm_read_byte(&memoryRO[address]);
  }

  // 0x4000 -- 0x57FF
  if (address >= 0x4000 && address < 0x5800) {
    // to RAM: 0x0000 -- 0x27FF
    return memoryRW[address-0x4000];
  }

  // 0xFC00 -- 0xFFFF
  if (address >= 0xFC00 && address < 0xFFFF) {
    // to STACK: 0x0000 -- 0x03FF
    return memoryStack[address-0xFC00];
  }

  // 0x8000 -- 0x801F
  if (address >= 0x8000 && address <= 0x801F) {
    // to DISPLAY: 0x0000 -- 0x001F
    return 0x00;
  }

  // 0x9000
  if (address == 0x9000) {
    // to BUTTONS
    // return buttonsGet();
    return 0x00;
  }

  return 0xff;
}

void memoryWrite(uint16_t address, uint8_t value) {
  // 0x0000 -- 0x27FF
  if (address < 0x2800) {
    // to ROM: 0x0000 -- 0x27FF
    return;
  }

  // 0x4000 -- 0x57FF
  if (address >= 0x4000 && address < 0x5800) {
    // to RAM: 0x0000 -- 0x27FF
    memoryRW[address-0x4000] = value;
  }

  // 0xFC00 -- 0xFFFF
  if (address >= 0xFC00 && address < 0xFFFF) {
    // to STACK: 0x0000 -- 0x03FF
    memoryStack[address-0xFC00] = value;
  }

  // 0x8000 -- 0x801F
  if (address >= 0x8000 && address <= 0x801F) {
    // to DISPLAY: 0x0000 -- 0x001F
    return;
  }

  // 0x9000
  if (address == 0x9000) {
    // to BUTTONS
    return;
  }

  return;
}

/*** MAIN ***/
void setup() {
  addressSetup();
  dataSetup();
  serialSetup();
  //displaySetup();
  // buttonsSetup();
  pinMode(PIN_CLK, INPUT);
  pinMode(PIN_CLK_OUT, OUTPUT);
  Serial.println(HEADER);
}

void log(uint8_t not_read, uint8_t not_write, uint16_t address, uint8_t data, uint8_t clkValue) {
  Serial.print(micros());
  Serial.print(',');
  Serial.print(not_read);
  Serial.print(',');
  Serial.print(not_write);
  Serial.print(',');
  Serial.print(address);
  Serial.print(',');
  Serial.print(data);
  Serial.print(',');
  Serial.println(clkValue);
}

void loop() {
  uint16_t address = 0;
  uint8_t operation, not_read, not_write;

  uint8_t value = memoryRead(address);
  // dataWrite(value);
  dataSetInput(true);

  uint8_t prevClkValue = digitalRead(PIN_CLK);
  uint8_t clkValue = prevClkValue;
  for(;;) {
    clkValue = digitalRead(PIN_CLK);

    not_read = digitalRead(PIN_CTL_NREAD);
    not_write = digitalRead(PIN_CTL_NWRITE);
    operation = controlGetOperation(not_read, not_write);

    address = addressRead();
    value = dataRead(false);

    digitalWrite(PIN_CLK_OUT, clkValue);

    if (clkValue - prevClkValue != EDGE_TRIGGER) {
      prevClkValue = clkValue;
      log(not_read, not_write, address, value, clkValue);
      continue;
    } else {
      prevClkValue = clkValue;
    }

    if (operation == OPERATION_NOP) {
      log(not_read, not_write, address, value, clkValue);
      continue;
    }

    if (operation == OPERATION_READ) {
      value = memoryRead(address);
      dataWrite(value);
      log(not_read, not_write, address, value, clkValue);
      continue;
    }

    if (operation == OPERATION_WRITE) {
      value = dataRead(true);
      memoryWrite(address, value);
      log(not_read, not_write, address, value, clkValue);
      continue;
    }

    continue;
  }
}

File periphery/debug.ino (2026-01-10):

#define SPLIT_LINE "-------|----------|------|----"
#define COLUMNS "PORT   | BINARY   | HEX  | DEC"
#define DATA_ROW "DATA   | "
#define STATE_ROW "STATE  | "

// DATA[0] -> Pin 37 and DATA[7] -> Pin 23
const byte dataPins[] = {37, 35, 33, 31, 29, 27, 25, 23};
// STATE[0] -> Pin 52 and STATE[7] -> Pin 38
const byte statePins[] = {52, 50, 48, 46, 44, 42, 40, 38};

void printFormatted(byte val)
{
  for (int i = 7; i >= 0; i--)
  {
    Serial.print(bitRead(val, i));
  }

  Serial.print("  | 0x");
  if (val < 16)
  {
    Serial.print("0");
  }
  Serial.print(val, HEX);

  Serial.print(" | ");
  Serial.println(val, DEC);
}

void setup()
{
  Serial.begin(115200);

  for (int i = 0; i < 8; i++)
  {
    pinMode(dataPins[i], INPUT);
    pinMode(statePins[i], INPUT);
  }

  Serial.println(COLUMNS);
  Serial.println(SPLIT_LINE);
}

void loop()
{
  byte dataVal = 0;
  byte stateVal = 0;

  for (int i = 0; i < 8; i++)
  {
    if (digitalRead(dataPins[i]) == HIGH)
    {
      dataVal |= (1 << i);
    }

    if (digitalRead(statePins[i]) == HIGH)
    {
      stateVal |= (1 << i);
    }
  }

  Serial.print(DATA_ROW);
  printFormatted(dataVal);

  Serial.print(STATE_ROW);
  printFormatted(stateVal);

  Serial.println(SPLIT_LINE);
  delay(1000);
}

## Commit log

2024-10-09 more convenient file structure
    [c5_pin_model_dump.txt]
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2025-10-05 Fix interrupts and make intack a component of bus
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2025-10-05 refactor(EncodeTable): changed the gen_encode_table.py to work with new file csv format
    [table.csv]
2025-10-05 added emulator base structure
    [table.csv]
2025-10-06 Fix bug on next operation loading under interrupt, remove constant in instruction decoder
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2025-10-19 added register file hub
    [register_file.kicad_pcb, register_file.kicad_sch]
2025-10-19 Added pointerhub + basecouter sch
    [BaseCounter.kicad_sch, pointer_hub.kicad_pcb, pointer_hub.kicad_sch]
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2025-10-23 feat(kicad): added alu hub, combined accumulator, argument register, alu from logisim-evolution
    [alu.kicad_pcb, alu.kicad_sch]
2025-10-23 fix(kicad): errors related with high args
2025-10-24 fix(kicad): updated footprints
    [alu.kicad_sch]
2025-10-24 fix(kicad): added footprints
    [alu.kicad_sch]
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2025-10-24 fixed all errors
    [register_file.kicad_sch]
2025-10-24 fix(kicad): fixed kicad ERC errors, replaces resistors to capacitors
    [alu.kicad_sch]
2025-10-24 Add more labels to main hub decoder
    [main_hub.kicad_pcb, main_hub.kicad_sch]
2025-10-24 Connnect all modules together
    [alu.kicad_pcb, alu.kicad_sch, main_hub.kicad_pcb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]
2025-10-25 added lowarg to pointerhub, also replaced resistor + vcc logic by grnd and changing A and B pins(A was in became out...)
    [pointer_hub.kicad_pcb, pointer_hub.kicad_sch]
2025-10-25 fix: added kicad gitignore
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2025-10-25 Add interface module schematic
    [interface.kicad_pcb, interface.kicad_sch, main_hub.kicad_pcb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]
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2025-10-25 Refactor and enhance assembler toolchain
    - Added Serializer class for file operations in `Serializer.hpp`.
    - Removed obsolete test files (`test.S`, `test2.S`, `test_mini.s`) to clean up the project.
    - Introduced comprehensive documentation for the CPU8/16 assembler in `ASM_DOCUMENTATION.md`.
    - Created detailed `DOCUMENTATION.md` outlining operand types, registers, symbol tables, and error types.
    - Added multiple example programs to demonstrate assembler functionality and instruction coverage.
    - Implemented a full test program (`ExampleALL_Emu.s`) exercising all mnemonics from the instruction set.
    - Updated example files to reflect new structure and functionality.
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2025-10-31 split rf into rf and core 1
    [core_1.kicad_pcb, core_1.kicad_sch, register_file.kicad_sch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]
2025-10-31 new folder for gen 2 schematics
    [core_2.kicad_pcb, core_2.kicad_sch, register_file_gen2.kicad_pcb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]
2025-10-31 (feat) sp and pc added
    [pc.kicad_pcb, pc.kicad_sch, sp.kicad_sch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]
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2025-10-31 Fix namings on connector
2025-10-31 Add gen2 base module and interface module
    [base_module.kicad_pcb, interface.kicad_pcb, interface.kicad_sch]
2025-10-31 feat: Alu hub + pdfs
    [accum.kicad_pcb, accum.kicad_sch, alu_hub.kicad_pcb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]
2025-10-31 fix: base module to match 100 mm x 100mm
    [accum.kicad_pcb, base_module.kicad_pcb]
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2025-11-01 fix: update accumulator schematic and routing rules
    [accum.kicad_pcb, accum.kicad_sch]
2025-11-01 feat: accumulator pcb plate, with routes and gnd plate
    [accum.kicad_pcb]
2025-11-01 implemented pcb for register file
    [register_file_gen2.kicad_pcb, register_file_gen2.kicad_sch]
2025-11-02 feat: alu hub + pcb base not finished yet
    [alu.kicad_sch, alu_hub.kicad_pcb, alu_hub.kicad_sch]
2025-11-02 pc and sp sch
    [pc.kicad_pcb, pc.kicad_sch, step_counter.kicad_pcb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]
2025-11-02 feat: position files path in ALU Hub schematic configuration
    [alu_hub.kicad_pcb]
2025-11-02 feat(alu): added vcc and gnd back plate
    [alu_hub.kicad_pcb, alu_hub.kicad_sch]
2025-11-04 (feat) stack pointer and program counter pcb, QA needed.
    [main.kicad_pcb, pc.kicad_pcb, pc.kicad_sch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]
2025-11-04 feat: added gnd connections for alu hub
    [alu_hub.kicad_pcb]
2025-11-04 fix: gnd plate
    [alu_hub.kicad_pcb]
2025-11-04 fix: changed the placement
    [alu_hub.kicad_pcb]
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2025-11-04 fix: changed footprints in accum, added resistor and capacitor footrpint
    [accum.kicad_pcb, accum.kicad_sch]
2025-11-05 fix(alu): removed 90 degrees
    [alu_hub.kicad_pcb]
2025-11-05 fix(accum): update segment connections and adjust routing
    [accum.kicad_pcb]
2025-11-07 stack rework
    [step_counter.kicad_pcb]
2025-11-07 remake of register file module
    [register_file_gen2.kicad_pcb]
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2025-11-07 fixed errors
    [register_file_gen2.kicad_pcb]
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2025-11-07 refactor(accum): reimplemented accumalot module
    [accum.kicad_pcb, accum.kicad_sch]
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2025-11-07 Add core3, fix core2
    [core_2.kicad_pcb, core_2.kicad_sch]
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2025-11-07 fixed bugs in core 1 sch
    [core_1.kicad_sch]
2025-11-08 feat(alu): add resistor symbol and connections to ALU hub schematic
    [alu_hub.kicad_pcb, alu_hub.kicad_sch]
2025-11-08 inprgress(alu); 9 traces left
    [alu_hub.kicad_pcb]
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2025-11-08 almost ready core 2
    [core_2.kicad_pcb, core_2.kicad_sch]
2025-11-08 Implement code changes to enhance functionality and improve performance
    [interface.kicad_pcb, interface.kicad_sch]
2025-11-08 doine(core_ 2): almost ready to print
    [core_2.kicad_pcb, core_2.kicad_sch]
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2025-11-09 inprogress(interface): 19 pins left
    [interface.kicad_pcb]
2025-11-09 upd: changed logo to svg + svg
    [register_file_gen2.kicad_pcb]
2025-11-10 design + fix core_2
    [core_1.kicad_pcb, core_2.kicad_pcb, pc.kicad_pcb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]
2025-11-10 fix(register file): added pull up resistor fixed schematic, changed capacitors
    [register_file_gen2.kicad_pcb, register_file_gen2.kicad_sch]
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2025-11-10 fix clk in core_1
    [core_1.kicad_pcb]
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2025-11-10 accum review complete final
    [accum.kicad_pcb]
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2025-11-10 fix(pc): changed resistor, capacitors footprints
    [pc.kicad_pcb, pc.kicad_sch]
2025-11-10 fix(stack pointer): fixed footprints
    [step_counter.kicad_pcb, step_counter.kicad_sch]
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2025-11-10 chore(alu hub): changed logo and text
    [alu_hub.kicad_pcb]
2025-11-10 chore(accum): changed logo and text
    [accum.kicad_pcb]
2025-11-10 chore(core 2): changed logo and text
    [core_2.kicad_pcb]
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2025-11-10 chore(core 1): added logo and text
    [core_1.kicad_pcb]
2025-11-10 chore(kicad-pcb): added apps ucu logo
    [accum.kicad_pcb, alu_hub.kicad_pcb, core_1.kicad_pcb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]
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2025-11-10 changes pc sc interface
    [interface.kicad_pcb, pc.kicad_pcb, step_counter.kicad_pcb]
2025-11-10 fix(kicad): vcc zones
    [accum.kicad_pcb, alu_hub.kicad_pcb, core_1.kicad_pcb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]
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2025-11-12 combine accum and reg_file
    [register_file_accum.kicad_pcb, register_file_accum.kicad_sch]
2025-11-12 fix(alu): deleted copy file
    [alu_hub copy.kicad_pcb]
2025-11-12 structure(kicad): redefined the structure of the repository
    [BaseCounter.kicad_sch, accum.kicad_pcb, accum.kicad_sch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]
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2025-11-12 small change to core_1
    [core_1.kicad_pcb]
2025-11-12 Update backplane, add power supply and debug port
    [backplane.kicad_pcb, backplane.kicad_sch]
2025-11-13 tried to make core_3
    [core_3.kicad_pcb, core_3_old.kicad_pcb]
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2025-11-15 fix(alu): changed vcc gnd connection + clearence of cooper zones
    [alu_hub.kicad_pcb]
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2025-11-15 fix(core2): changed vcc and gnd connection + cooper clearence
    [core_2.kicad_pcb]
2025-11-16 fix(alu, core2, interface): vcc conection some routing issues
    [alu_hub.kicad_pcb, core_2.kicad_pcb, interface.kicad_pcb]
2025-11-16 fix: removed in control pins daisy chains
    [alu_hub.kicad_pcb, core_1.kicad_pcb, core_2.kicad_pcb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]
2025-11-16 fix(backplane): changed vcc and gnd connector
    [backplane.kicad_pcb, backplane.kicad_sch]
2025-11-17 fix(backplane): changed connector, fixed zones issues
    [backplane.kicad_pcb]
2025-11-17 Add pcb for core 3
    [core_3.kicad_pcb, core_3.kicad_sch]
2025-11-17 fix(backplane): removed duplicates of zones
    [backplane.kicad_pcb, backplane.kicad_sch]
2025-11-17 fix(alu): vcc conn
    [alu_hub.kicad_pcb]
2025-11-18 fix(alu, core_1_2, interface): put vcc zones on back layer
    [alu_hub.kicad_pcb, core_1.kicad_pcb, core_2.kicad_pcb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]
2025-11-19 fix(register_accum): fixed the data to y shape connection removed the vcc from the resistor
    [alu_hub.kicad_pcb, register_file_accum.kicad_pcb, register_file_accum.kicad_sch]
2025-11-19 added testpoints on core 2
    [core_2.kicad_pcb, core_2.kicad_sch]
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2025-11-19 Add test points in Core 1
    [alu_hub.kicad_sch, core_1.kicad_sch]
2025-11-19 slight changes to vcc
    [core_1.kicad_pcb, core_3.kicad_pcb]
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2025-11-19 update pc and sp
    [old_step_counter.kicad_pcb, pc.kicad_pcb, step_counter.kicad_pcb]
2025-11-19 feat(alu): added tp to alu
    [alu_hub.kicad_pcb, alu_hub.kicad_sch]
2025-11-19 fix(alu, interface): fix tp
    [alu_hub.kicad_pcb, alu_hub.kicad_sch, interface.kicad_pcb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]
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2025-11-19 Add test points for register file + accum
    [register_file_accum.kicad_pcb, register_file_accum.kicad_sch]
2025-11-19 Fix register file accum
    [register_file_accum.kicad_pcb]
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2025-11-20 feat(gerbers): made order in jlcpcb and fixed document
    [alu_hub-B_Cu.gbr, alu_hub-B_Mask.gbr, alu_hub-B_Paste.gbr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]
2025-12-29 chore: deleted python emulator, depracated schematics, moved dragonfly logo to assets, moved asm code to asm_toolchain/examples directory
    [BaseCounter.kicad_sch, accum.kicad_pcb, accum.kicad_sch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]
2026-01-07 Push periphery and fix schematics
    [alu_hub.kicad_sch, core_2.kicad_sch, core_3.kicad_sch]
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2026-01-10 fix(debug.ino): fixed alignment in output str
    [debug.ino]
2026-01-10 Fix U4 connection in interface
    [interface.kicad_sch]
2026-01-10 Fix inverted pulse
    [core_2.kicad_sch]
2026-01-10 Fix pulse detector
    [core_2.kicad_sch]
2026-01-10 Fix addressing in stack and add halt condition in simulator
    [periphery.ino]
2026-01-10 Add hotfix for timing issue
    [core_1.kicad_sch]
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2026-01-11 fix(export): fixed path to kicad
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2026-01-12 fix(gdb): changed endiannes in debugger, added recongnition for cycles per operation, updated table.csv in asm toolchain, added reg command, fixed watch command, changed xl->ac
    [table.csv]
2026-01-14 fix(gdb): fixed issues with nexti in gdb, removed unused files from asm, added bug report
    [periphery.ino]
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2026-01-15 Replace millis with micros for better precision and add not_ for inverted pins
    [periphery.ino]
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2026-01-16 Repair dumps and add merging mechanism to create waveforms
    [debug_1.csv, debug_2.csv, debug_3.csv]
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
